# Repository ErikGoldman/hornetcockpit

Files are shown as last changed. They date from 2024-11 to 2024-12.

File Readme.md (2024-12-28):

# Stuff to buy

* [Buttons](https://www.aliexpress.us/item/3256807596969239.html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)
  * 3x for landing panel, 1x for emergency jet button

* [Rotary switches](https://www.aliexpress.us/item/3256806749667426.html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)
  * 2 x 3-position for the DDI on/day/night
  * 1 x 5-position for jett select on the button box

* [Rtoary encoder](https://www.aliexpress.us/item/3256804721655912.html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)
  * 2 for the UFC comm knobs

* [Switches](https://www.aliexpress.us/item/3256803381777279.html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)
  * 4 x On-Off for the landing panel
  * 1 x On-Off-On for the landing panel (flaps switch)

* [Heavy on/off switch](https://www.aliexpress.us/item/3256807335530736.html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)
  * 1  for Master Arm
  * 1 for landing gear on button box

* [Infinite metric inserts](https://www.aliexpress.us/item/3256806602613585.html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)
  * You'll need M2, M3, and M4. Length doesn't matter that much.

* [Tactile switches](https://www.aliexpress.us/item/3256806726559452.html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)
  * You'll need ~25 B3F-1025 buttons for the UFC

* [LED tactile switches](https://www.aliexpress.us/item/3256805751476152.html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)
  * You'll need 40 for the DDIs. Might as well get green even if we're not lighting them up but up to you.

* [Potentiometers](https://www.aliexpress.us/item/3256806040646290.html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)
  * 4 total for the DDI brightness and contrast

* [Micro limit switches](https://www.aliexpress.us/item/3256805410237576.html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)
  * 4x for the parking brake

* [Lots of metric screws](https://www.aliexpress.us/item/3256806962079941.html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)
  * Either buy a few packs or just go to a hardware store and get the ones you need. You'll use M2, M3, and M4 screws for this project.

* [S2 minis](https://www.aliexpress.us/item/3256807363603425.html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)
  * You'll need 4: 2x DDI, 1x UFC, 1x landing box

* [Jumper Wire](https://www.aliexpress.us/item/3256805315188857.html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)
  * Get 2x Female-to-Female and 2x Male-To-Male

* [Flexible wire](https://www.aliexpress.us/item/3256807235268703.html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)
  * 28 AWG flexible silicone wire is handy here

# Assemble

## Printing

Print one of everything in FilesToPrint. Let me know if you run into any trouble but otherwise just keep it organized since you'll have a lot of parts sitting around.

We'll be replacing all of the imperial inserts and screws with metric ones since metric is way cheaper and easier to source. Take a look at "Assembly instructions" to see how everything fits together and use the similarly-sized metric insert and screw instead of whatever is listed there.

There are backplates for the two DDIs, master arm panel, and UFC. Print those and they should line up next to each other. The desk clamps mount on the DDIs and on the master arm panel and allow you to screw into your desk. You may want to put some foam or something soft in the clamp to prevent scratching on your desk.

## PCBs

NextPCB is crazy cheap. There should be NextPCB-compatible BOMs in the directories and the .zip files should be what PCBNext wants to give a quote and manufacture everything.

Note that the holes in the DDIs are too small for your rotary encoders and potentiometers. I dremeled them to be a bit larger and everything was fine. I could modify the PCB to fit the new components but I'm lazy.

## Electrical

Look at the top of the .ino files to see the pin assignments. Look up how to wire buttons and switches if you haven't done it before, the internet will help here.

## Software

Use the .ino sketches to upload to the ESP32s. Note that if you just upload the sketch normally the ESP32 will have its default product ID/serial number/etc. and so you can't have multiple of them connected to DCS at the same time. To fix that, go to Tools -> USB CDC On Boot and set to "Disabled". They should now have descriptive names like "F18 UFC" in DCS.

At the top of the DDI.ino sketch you should see `#define IS_LEFT_DDI 1` -- that should be 1 for for the left DDI but set it to zero before you upload to the right DDI (`#define IS_LEFT_DDI 0`).

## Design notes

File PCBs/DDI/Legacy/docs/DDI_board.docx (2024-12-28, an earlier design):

# DDI and AMPCD boards

This document contains information about the hardware design for DDI and AMPCD panels.

# Modular vs non modular

## Option A: Modular DDI

A modular approach allows for simpler hardware thanks to the reuse of parts, this approach requires a total of 8 DDI/4 PCBs + four AMPCD/4 + three (3) Nano shields made for this purpose.

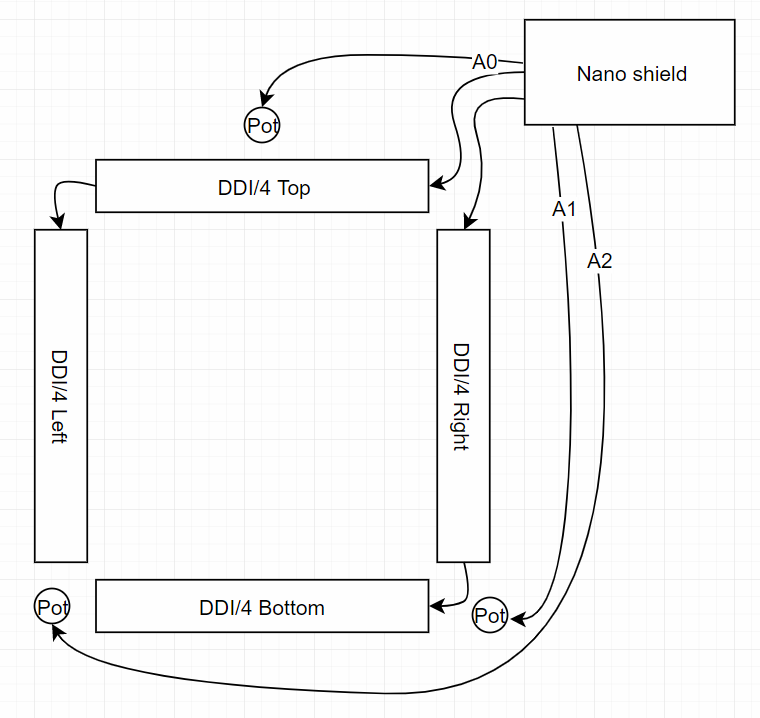
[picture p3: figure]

## Option B: Full board

This approach reuses 100% schematic from modular DDI but two different boards need to be created, one for LEFT/RIGHT DDI panels and one for AMPCD. One thing to consider is that this approach requires three boards of approximately 158mm (6.23in) x 167mm (6.59in) in size.

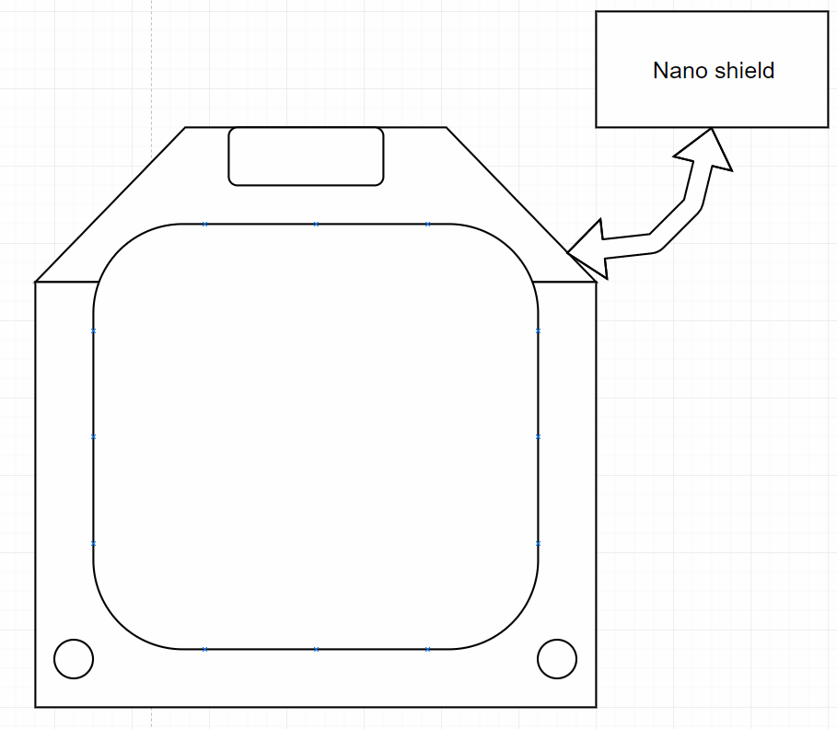
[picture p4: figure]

# Modular detailed

## Left and Right DDI panels

Left and right panels are identical, the only way to differentiate between these two panels is what option is installed on the Nano shield (see Nano shield options for more information)

## AMPCD panel

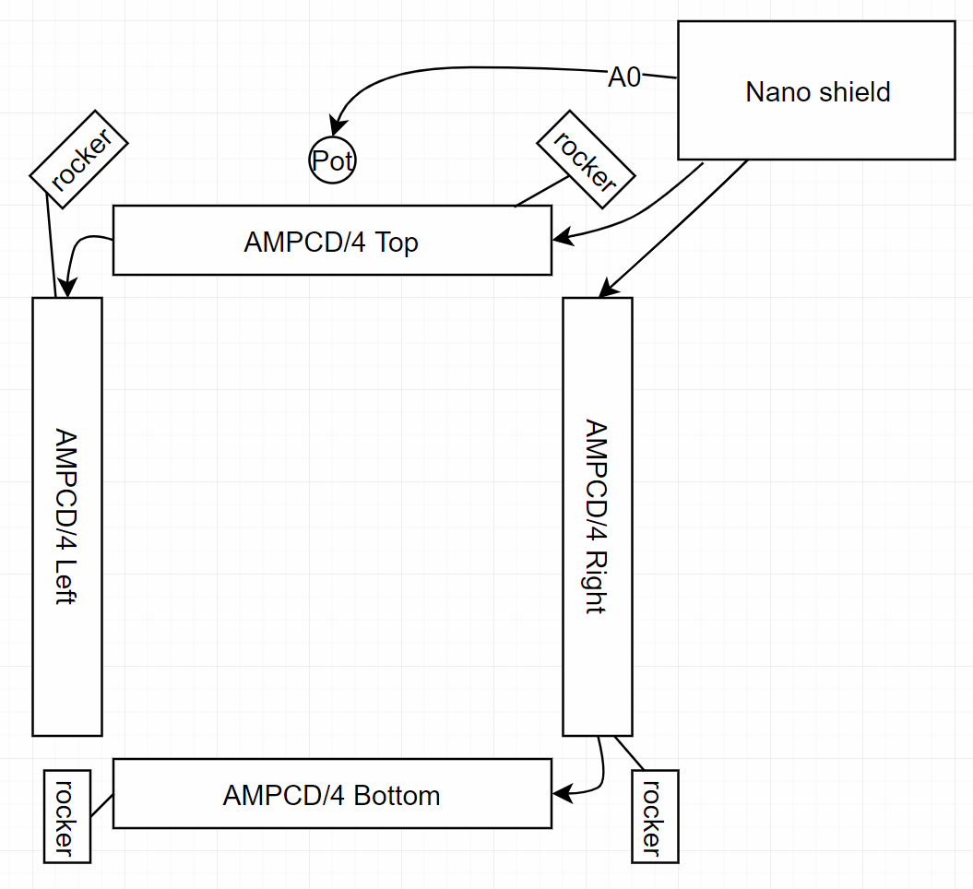
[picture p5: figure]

The AMPCD panel differentiates from the DDI panels thanks to the use of rocker switches, the rocker switches are handled the same way as the OSBs.

## Nano shield options

The Nano shield boards allow for software to recognize the position in the cockpit, this is done by configuring the pull-ups and pull-downs according to the following table.

Option | Requires
Left DDI | d1 Pull down, d0 Pull up
Right DDI | d1 Pull up, d0 Pull down
AMPCD | d1 pull up, d0 pull up

## DDI/4 and AMPCD/4 Addressing

Each one of the boards contains a TCA9534A IO expander, this device can be configured with up to 8 different I2C addresses, upon boot, and Software shall poll all 8 addresses in order to identify what modules are installed. The address assignation is done according to this table.

Location | I2C Address
DDI/4 Top | 0b0111000
DDI/4 Left | 0b0111001
DDI/4 Right | 0b0111010
DDI/4 bottom | 0b0111011

## Button press handling

Each DDI/4 board uses IO expander capable of generating an interrupt when any button is pressed, the PCB provides two button debouncing mechanisms in order to prevent fake interrupts or multiple interrupts in a short period of time.

The debouncing mechanism consists of:

- 6 hysteresis triggered inverted mechanism with <5ms detection delay. These circuits provide full debouncing capabilities and are intended to be used for the five OSBs + an extra button. These inputs filter most of the fake interrupts created by button bouncing by allowing only 0v or 5v outputs. One important distinction is that the values of the switch are inverted and software needs to take this into account.
- 2 non inverted switches with ~5ms detection delay intended for rockers (AMPCD only). These inputs provide medium debouncing capability by smoothing any glitches, fake interrupts may be triggered depending on the receiving IC specific thresholds.

Any change of any of these inputs will cause an interrupt to be fired and software can now read the status of all four DDI/4 blocks in order to determine which button was pushed. If necessary software might add extra debouncing time to compensate for flaky connections and bouncy switches.

The following pictures represent a simulation of the debouncing hardware please notice that the RC constant has been calculated for 10ms leading to a sub 5ms detection delay in most cases.

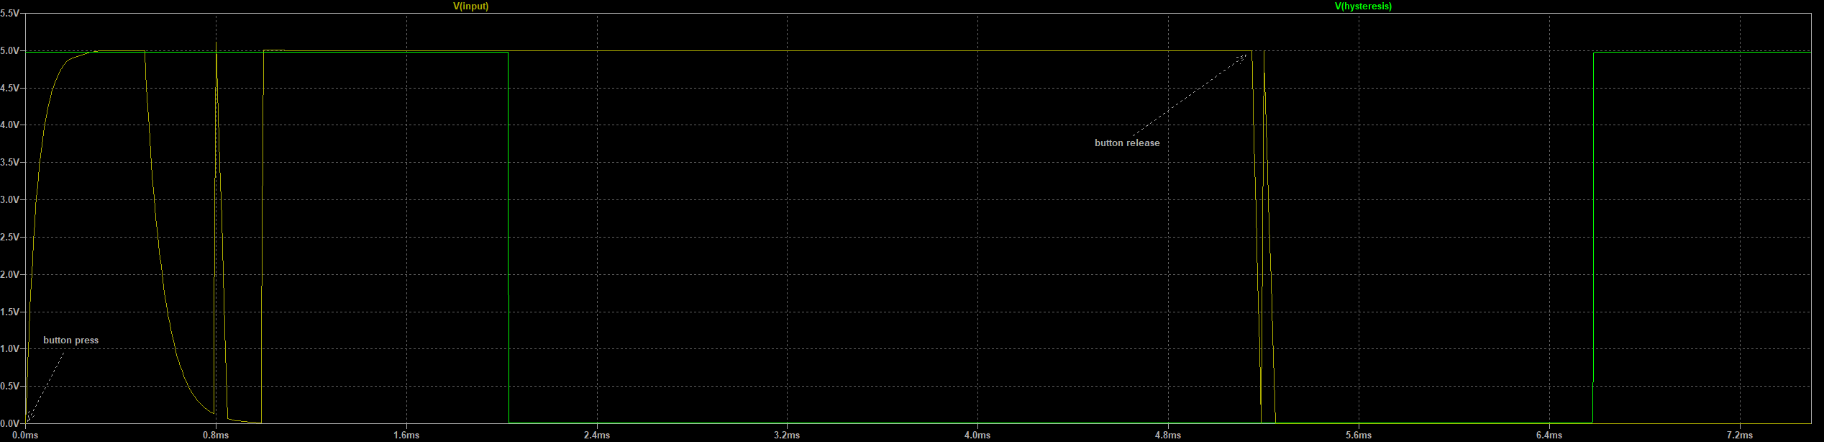
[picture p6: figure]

Figure 1 Button press detection with hysteresis

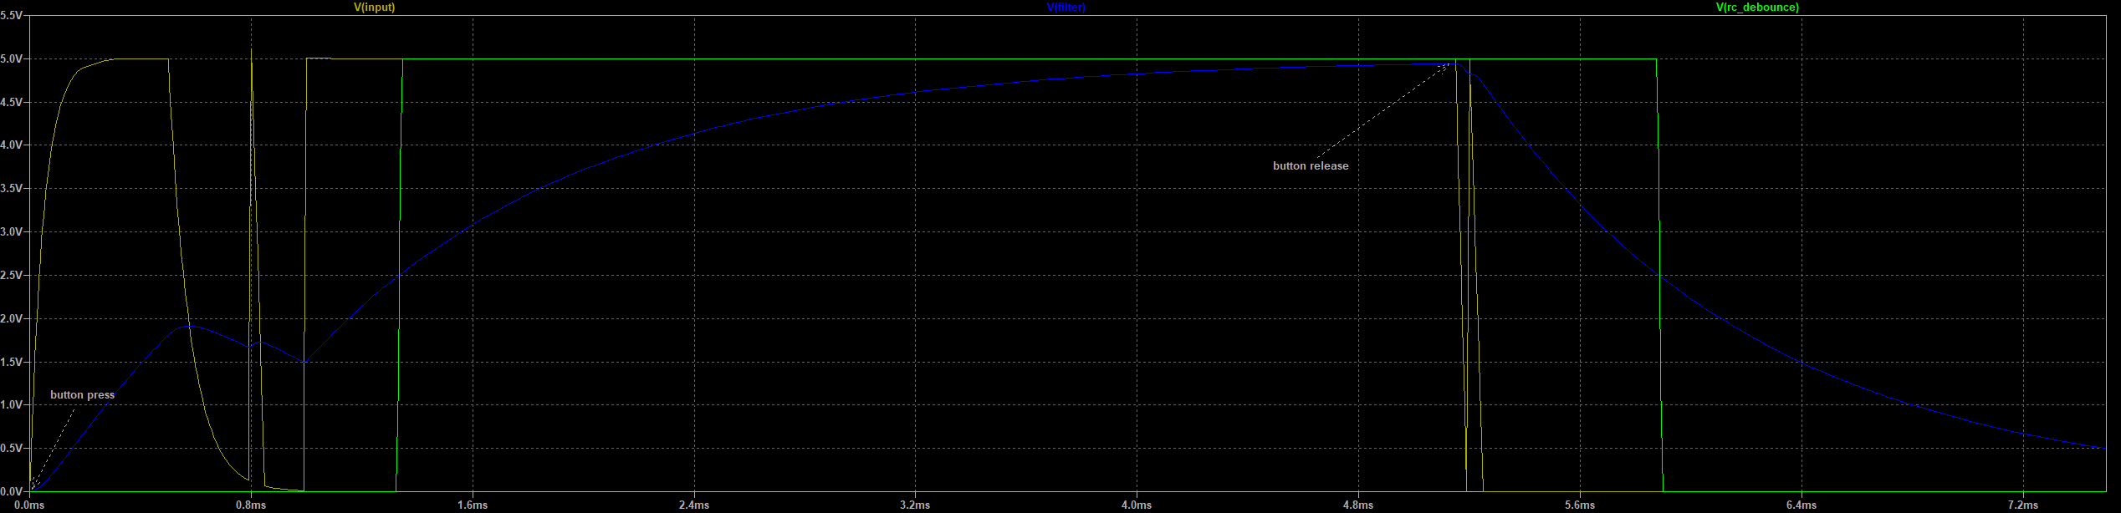
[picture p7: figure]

Figure 2 low pass detection using a 2.5v threshold example

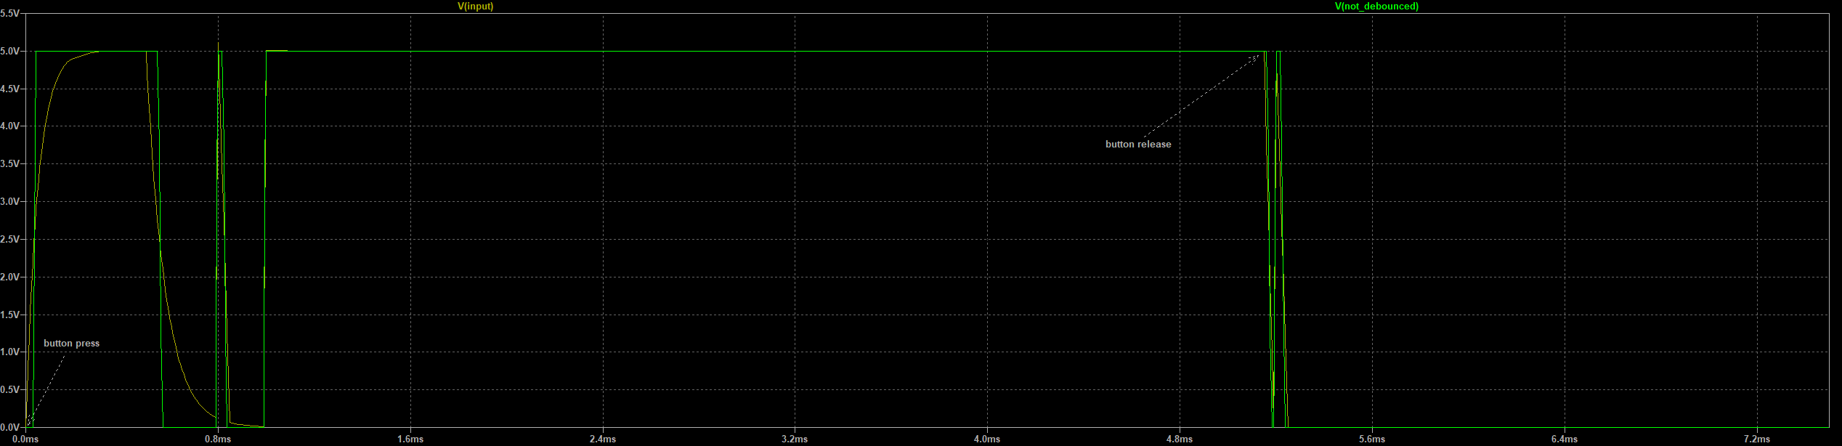
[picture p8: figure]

Figure 3 Raw signal detection (no debouncing)

## Potentiometer handling

The potentiometers installed in each DDI are read from A0-A2 pins from Arduino according to this table:

potentiometer | Pin
<<find names>> | A0
| A1
| A2

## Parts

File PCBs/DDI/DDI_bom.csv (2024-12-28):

Id | Designator | Footprint | Quantity | Designation | Supplier and ref
1 | C1,C2,C3,C4 | C_1206_3216Metric | 4 | 47uF
2 | D1,D2,D3,D4,D5,D6,D7,D8,D9,D10,D11,D12,D13,D14,D17,D18,D19,D20,D21,D22,D23,D24,D25,D26,D27,D28,D29,D30,D31,D32 | LED_0402_1005Metric | 30 | LED
3 | R1,R2,R3 | R_0603_1608Metric | 3 | 10K
4 | R4,R6,R8,R10,R16,R17,R19,R20 | R_0402_1005Metric | 8 | 150
5 | R5,R9,R11,R15,R18,R21,R7 | R_0402_1005Metric | 7 | 270
6 | R12,R13,R14 | R_0402_1005Metric | 3 | 33
7 | U1,U2,U3,U4 | TSSOP-16_4.4x5mm_P0.65mm | 4 | TCA9554PWR
8 | SW1,SW3,SW4,SW5,SW6,SW7,SW8,SW9,SW10,SW11,SW12,SW13,SW14,SW15,SW16,SW17,SW18,SW20,SW2,SW19 | TL1240GQ | 20 | TL1240GQ
9 | G***,G*** | OH_LOGO_ONLY_11x6mm | 2 | OH_LOGO_ONLY_11x6mm

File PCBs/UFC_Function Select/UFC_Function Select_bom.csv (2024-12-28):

Id | Designator | Footprint | Quantity | Designation | Supplier and ref
1 | D23,D4,D3,D27,D1,D26,D15,D20,D13,D10,D25,D7,D2,D24,D6,D16,D19,D11,D5,D21,D9,D8,D14,D22,D12,D28,D17,D18 | LED_WS2812B-2020_PLCC4_2.0x2.0mm | 28 | WS2812B-2020
2 | SW7,SW4,SW3,SW2,SW1,SW6,SW5 | Omron_B3F-1026 | 7 | B3F-1026
3 | J1 | PinHeader_2x03_P2.54mm_Vertical | 1 | TO UFC
4 | U1 | VQFN-24-1EP_4x4mm_P0.5mm_EP2.45x2.45mm | 1 | PCA9555RGER
5 | C1 | CP_Elec_6.3x5.4 | 1 | 100uF
6 | C2 | C_0603_1608Metric | 1 | .1uF
7 | R4 | R_0603_1608Metric | 1 | 10K

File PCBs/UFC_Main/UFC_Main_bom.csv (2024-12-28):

Id | Designator | Footprint | Quantity | Designation | Supplier and ref
1 | MK1,MK2,MK3,MK4 | MountingHole_4.5mm | 4 | MH
2 | POT1 | BR10K_Pot_11mm_x_11mm | 1 | VOL1
3 | POT3 | BR10K_Pot_11mm_x_11mm | 1 | BRT
4 | POT2 | BR10K_Pot_11mm_x_11mm | 1 | VOL2
5 | MK5 | MountingHole_6.4mm_M6 | 1 | SW_ADF
6 | TP1 | TestPoint_THTPad_D1.5mm_Drill0.7mm | 1 | 5V
7 | TP2,TP10,TP7,TP9,TP8 | TestPoint_THTPad_D1.5mm_Drill0.7mm | 5 | GND
8 | DS7,DS8 | UFCSingleDigit | 2 | UFCSingleDigit
9 | DS2 | UFCOptionDigit | 1 | UFCOptionDigit
10 | DS3,DS4,DS5,DS6 | UFCOptionDigit | 4 | UFCOptionDigit
11 | BL1 | SCRATCHPADBACKLIGHT | 1 | SCR BL
12 | DS1 | SCRATCHPADLCD | 1 | SCR DISP
13 | D30,D13,D44,D57,D99,D67,D1,D17,D9,D52,D62,D111,D14,D27,D54,D46,D2,D91,D109,D63,D45,D49,D113,D33,D26,D97,D101,D50,D41,D8,D107,D10,D68,D90,D11,D114,D5,D105,D115,D95,D92,D28,D117,D53,D22,D35,D23,D7,D65,D108,D42,D93,D103,D61,D29,D88,D64,D19,D87,D31,D102,D100,D32,D55,D56,D112,D4,D60,D51,D106,D6,D86,D21,D15,D12,D104,D94,D16,D18,D43,D116,D20,D48,D25,D96,D3,D66,D89,D98,D34,D24,D36,D47,D58,D59,D110 | LED_WS2812B-2020_PLCC4_2.0x2.0mm | 96 | WS2812B-2020
14 | SW4,SW12,SW11,SW5,SW10,SW9,SW7,SW17,SW14,SW1,SW6,SW3,SW13,SW19,SW2,SW8,SW18,SW15,SW16 | Omron_B3F-1026 | 19 | B3F-1026
15 | TP3 | TestPoint_THTPad_D1.5mm_Drill0.7mm | 1 | SCL
16 | TP5 | TestPoint_THTPad_D1.5mm_Drill0.7mm | 1 | SCL@3.3V
17 | TP4 | TestPoint_THTPad_D1.5mm_Drill0.7mm | 1 | SDA
18 | TP6 | TestPoint_THTPad_D1.5mm_Drill0.7mm | 1 | SDA@3.3V
19 | C1,C2,C3,C4,C16,C15,C13 | C_0805_2012Metric | 7 | 10uF
20 | C7,C9,C10,C11,C12 | C_0603_1608Metric | 5 | .1uF
21 | C8,C6,C5 | C_0402_1005Metric | 3 | 100nF
22 | J1 | PinHeader_1x02_P2.54mm_Vertical | 1 | EXT_PWR
23 | J2 | PinHeader_1x04_P2.54mm_Vertical | 1 | ENC1
24 | J3 | PinHeader_1x03_P2.54mm_Vertical | 1 | VOL1
25 | J4 | PinHeader_1x03_P2.54mm_Vertical | 1 | BRT
26 | J5 | PinHeader_2x03_P2.54mm_Vertical | 1 | AP KB
27 | J6 | PinHeader_1x04_P2.54mm_Vertical | 1 | HUD BIT
28 | J7 | PinHeader_1x04_P2.54mm_Vertical | 1 | ENC2
29 | J8 | PinHeader_1x03_P2.54mm_Vertical | 1 | VOL2
30 | J9 | PinHeader_1x03_P2.54mm_Vertical | 1 | ADF SW
31 | R3,R7,R8,R2 | R_0603_1608Metric | 4 | 10K
32 | R4,R9,R10,R11,R12,R41,R40 | R_0603_1608Metric | 7 | 4.7k
33 | R43,R44 | R_0603_1608Metric | 2 | 68
34 | U1 | LQFP-48_7x7mm_P0.5mm | 1 | HT1621B
35 | U2,U3,U4,U5,U7,U6,U11 | SSOP-28_3.9x9.9mm_P0.635mm | 7 | GN1640T
36 | U8,U9 | TSSOP-20_4.4x6.5mm_P0.65mm | 2 | TXS0108EPWR
37 | MC1 | S2_MINI | 1 | S2_MINI
38 | G*** | OH_LOGO_75.4mm_11.9mm | 1 | LOGO
39 | D75,D70,D76,D74,D78,D80,D82,D73,D71,D81,D84,D85,D83,D79,D77,D69,D72 | D_SOD-523 | 17 | 1N4148WT
40 | Q5,Q6,Q4,Q7,Q8 | SOT-23 | 5 | ME2328-G
41 | C14 | CP_Elec_8x10 | 1 | 1000uF
42 | R1 | R_1812_4532Metric_Pad1.30x3.40mm_HandSolder | 1 | 30
43 | Q2 | SOT-23 | 1 | 2N7002
44 | D38 | LED_0603_1608Metric_Pad1.05x0.95mm_HandSolder | 1 | +3.3V_PWR
45 | R14,R6 | R_0402_1005Metric | 2 | 100K
46 | U10 | WQFN-24-1EP_4x4mm_P0.5mm_EP2.45x2.45mm | 1 | TCA8418RTWR
47 | D40 | LED_0603_1608Metric_Pad1.05x0.95mm_HandSolder | 1 | EXT PWR
48 | D37 | LED_0603_1608Metric_Pad1.05x0.95mm_HandSolder | 1 | +5V_PWR
49 | R46 | R_0402_1005Metric | 1 | 33
50 | D39 | D_SOD-123F | 1 | 1N4004W
51 | R13,R45 | R_0603_1608Metric | 2 | 120

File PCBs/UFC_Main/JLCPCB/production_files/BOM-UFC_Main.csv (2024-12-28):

Comment | Designator | Footprint | LCSC
TCA8418RTWR | U10 | WQFN-24-1EP_4x4mm_P0.5mm_EP2.45x2.45mm | C138713
.1uF | C10,C11,C12,C7,C9 | C_0603_1608Metric | C14663
100nF | C5,C6,C8 | C_0402_1005Metric | C1525
10uF | C1,C13,C15,C16,C2,C3,C4 | C_0805_2012Metric | C15850
1N4004W | D39 | D_SOD-123F | C162732
TXS0108EPWR | U8,U9 | TSSOP-20_4.4x6.5mm_P0.65mm | C17206
30 | R1 | R_1812_4532Metric_Pad1.30x3.40mm_HandSolder | C174837
120 | R13,R45 | R_0603_1608Metric | C22787
4.7k | R10,R11,R12,R4,R40,R41,R9 | R_0603_1608Metric | C23162
33 | R46 | R_0402_1005Metric | C25105
10K | R2,R3,R7,R8 | R_0603_1608Metric | C25804
GN1640T | U11,U2,U3,U4,U5,U6,U7 | SSOP-28_3.9x9.9mm_P0.635mm | C2758330
68 | R43,R44 | R_0603_1608Metric | C27592
100K | R14,R6 | R_0402_1005Metric | C327804
1000uF | C14 | CP_Elec_8x10 | C445083
ME2328-G | Q1,Q10,Q11,Q3,Q4,Q5,Q6,Q7,Q8,Q9 | SOT-23 | C709746
+5V_PWR | D37,D38,D40 | LED_0603_1608Metric_Pad1.05x0.95mm_HandSolder | C72043
1N4148WT | D69,D70,D71,D72,D73,D74,D75,D76,D77,D78,D79,D80,D81,D82,D83,D84,D85 | D_SOD-523 | C727112
HT1621B | U1 | LQFP-48_7x7mm_P0.5mm | C7532
2N7002 | Q2 | SOT-23 | C8545
WS2812B-2020 | D1,D10,D100,D101,D102,D103,D104,D105,D106,D107,D108,D109,D11,D110,D111,D112,D113,D114,D115,D116,D117,D12,D13,D14,D15,D16,D17,D18,D19,D2,D20,D21,D22,D23,D24,D25,D26,D27,D28,D29,D3,D30,D31,D32,D33,D34,D35,D36,D4,D41,D42,D43,D44,D45,D46,D47,D48,D49,D5,D50,D51,D52,D53,D54,D55,D56,D57,D58,D59,D6,D60,D61,D62,D63,D64,D65,D66,D67,D68,D7,D8,D86,D87,D88,D89,D9,D90,D91,D92,D93,D94,D95,D96,D97,D98,D99 | LED_WS2812B-2020_PLCC4_2.0x2.0mm | C965555
S2_MINI | MC1 | S2_MINI
ADF SW | J9 | PinHeader_1x03_P2.54mm_Vertical
VOL2 | J8 | PinHeader_1x03_P2.54mm_Vertical
ENC2 | J7 | PinHeader_1x04_P2.54mm_Vertical
HUD BIT | J6 | PinHeader_1x04_P2.54mm_Vertical
AP KB | J5 | PinHeader_2x03_P2.54mm_Vertical
BRT | J4 | PinHeader_1x03_P2.54mm_Vertical
VOL1 | J3 | PinHeader_1x03_P2.54mm_Vertical
ENC1 | J2 | PinHeader_1x04_P2.54mm_Vertical
EXT_PWR | J1 | PinHeader_1x02_P2.54mm_Vertical
SCR DISP | DS1 | SCRATCHPADLCD
SCR BL | BL1 | SCRATCHPADBACKLIGHT
UFCOptionDigit | DS6 | UFCOptionDigit
UFCOptionDigit | DS5 | UFCOptionDigit
UFCOptionDigit | DS4 | UFCOptionDigit
UFCOptionDigit | DS3 | UFCOptionDigit
UFCOptionDigit | DS2 | UFCOptionDigit
UFCSingleDigit | DS8 | UFCSingleDigit
UFCSingleDigit | DS7 | UFCSingleDigit
VOL2 | POT2 | BR10K_Pot_11mm_x_11mm
BRT | POT3 | BR10K_Pot_11mm_x_11mm
VOL1 | POT1 | BR10K_Pot_11mm_x_11mm
B3F-1026 | SW1 | Omron_B3F-1026
B3F-1026 | SW2 | Omron_B3F-1026
B3F-1026 | SW3 | Omron_B3F-1026
B3F-1026 | SW4 | Omron_B3F-1026
B3F-1026 | SW5 | Omron_B3F-1026
B3F-1026 | SW6 | Omron_B3F-1026
B3F-1026 | SW7 | Omron_B3F-1026
B3F-1026 | SW8 | Omron_B3F-1026
B3F-1026 | SW9 | Omron_B3F-1026
B3F-1026 | SW10 | Omron_B3F-1026
B3F-1026 | SW11 | Omron_B3F-1026
B3F-1026 | SW12 | Omron_B3F-1026
B3F-1026 | SW13 | Omron_B3F-1026
B3F-1026 | SW14 | Omron_B3F-1026
B3F-1026 | SW15 | Omron_B3F-1026
B3F-1026 | SW16 | Omron_B3F-1026
B3F-1026 | SW17 | Omron_B3F-1026
B3F-1026 | SW18 | Omron_B3F-1026
B3F-1026 | SW19 | Omron_B3F-1026

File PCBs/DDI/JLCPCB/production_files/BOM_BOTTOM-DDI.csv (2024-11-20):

Comment | Designator | Footprint | LCSC
Conn_01x06 | J1 | Molex_KK-254_AE-6410-06A_1x06_P2.54mm_Vertical | C504992

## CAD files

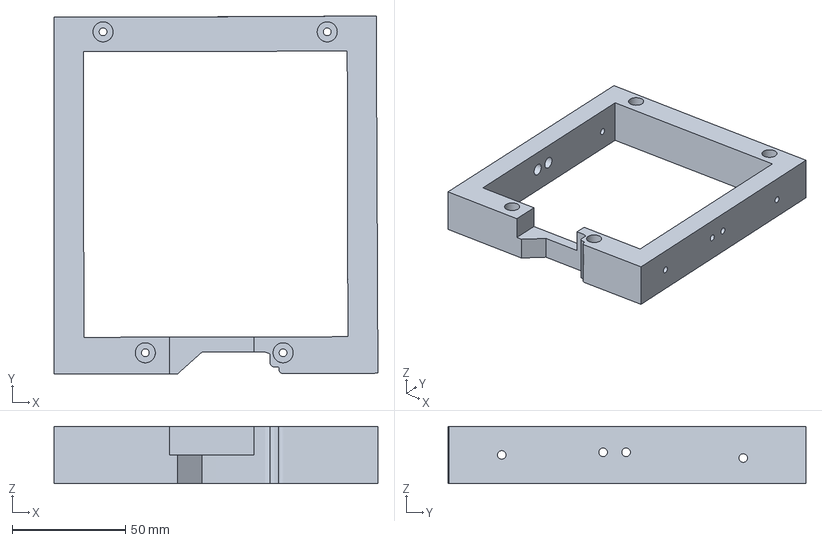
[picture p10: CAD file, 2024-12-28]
FilesToPrint/DDI/DDI desk Mount Plate.3mf
143.3 x 158.4 x 25.4 mm

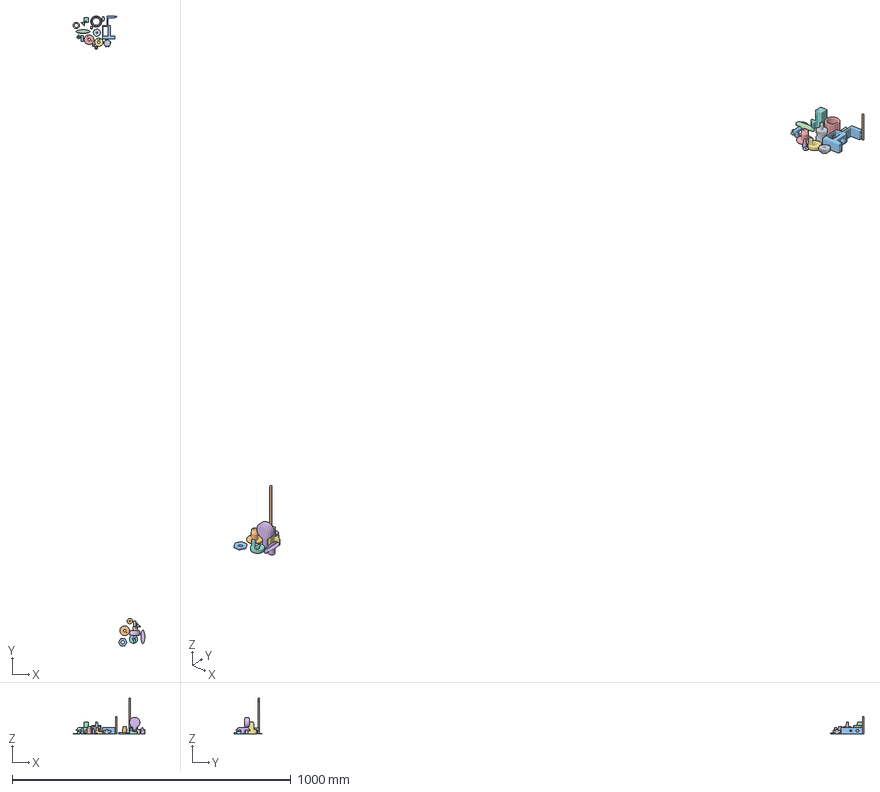
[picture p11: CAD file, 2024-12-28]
FilesToPrint/Landing panel/button box components.3mf
257.4 x 2259.5 x 128.1 mm
launch bar switch cover
circular top switch cover
parking brake lollipop
PB enclosure
PB EnclosureTopBody
PB M14 nut
PB handle
PB EnclosureBottomBody
PB shaft
flaps switch cover
AntiSkidSwitchCover
PB washer

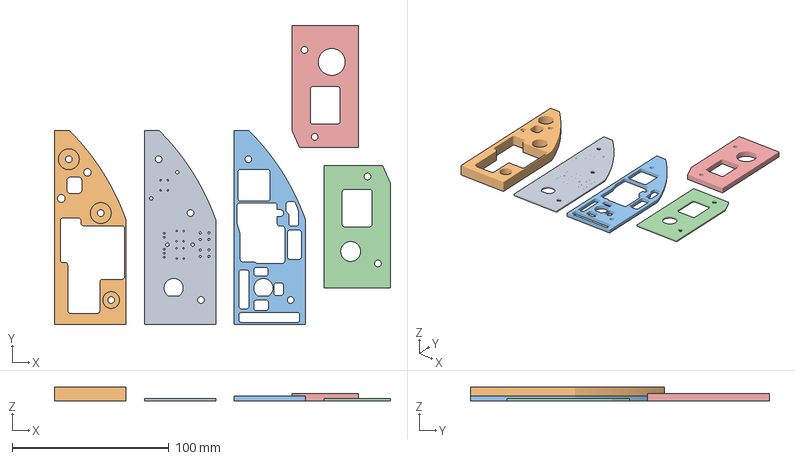
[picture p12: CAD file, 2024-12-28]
FilesToPrint/Master arm panel/master arm front panels.3mf
214.2 x 190.4 x 9.20 mm
master arm pcb
master arm spacer
master arm backplate
master arm legend plate
master arm thick front cover

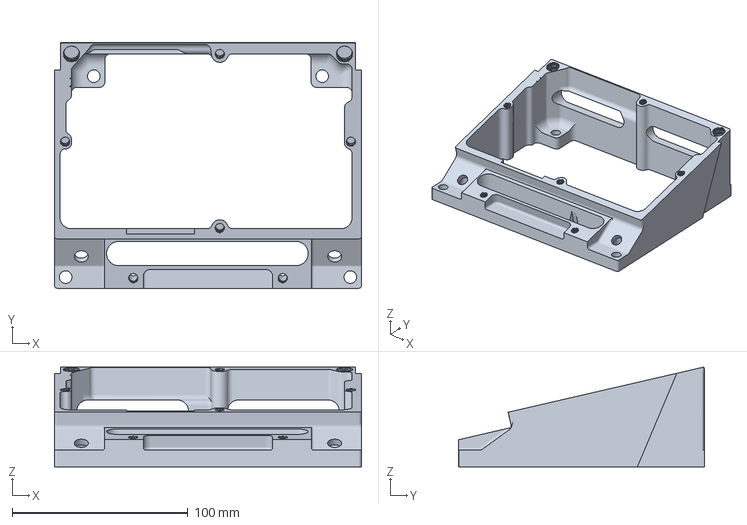
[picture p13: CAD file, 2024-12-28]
FilesToPrint/UFC/ufc panel support structure.3mf
174.6 x 139.7 x 56.8 mm

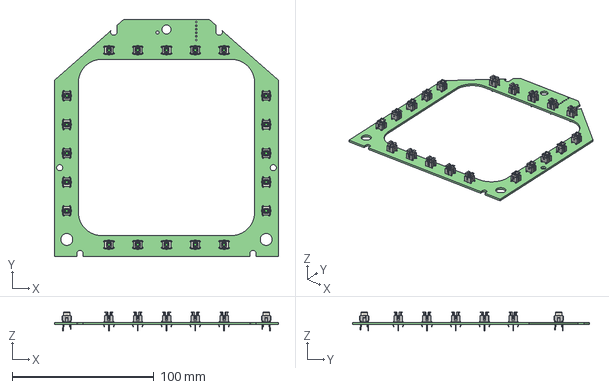
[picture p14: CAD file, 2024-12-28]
PCBs/DDI/MCAD/DDI.step
158.2 x 167.4 x 13.4 mm
DDI PCB

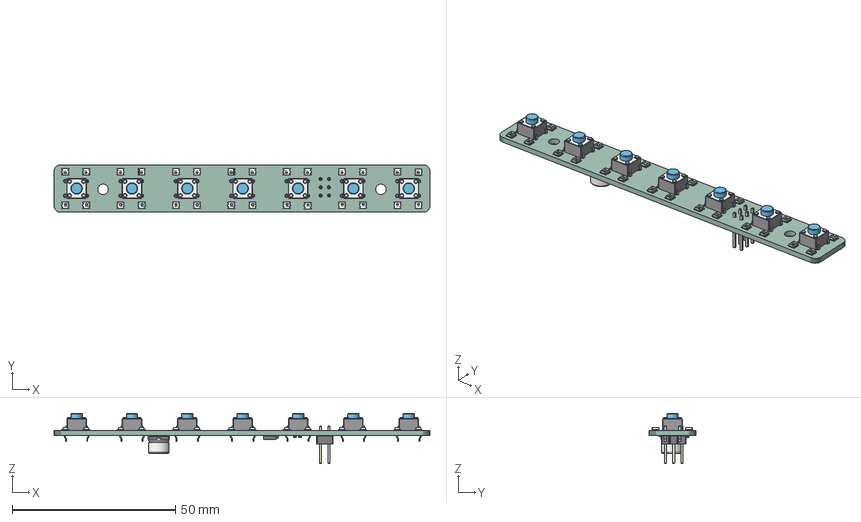
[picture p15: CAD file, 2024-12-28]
PCBs/UFC_Function Select/MCAD/PCB, UFC_Function Select.step
115.0 x 14.5 x 15.4 mm
PCB

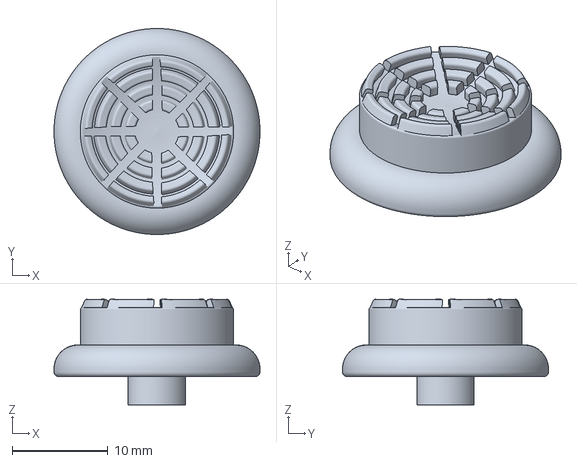
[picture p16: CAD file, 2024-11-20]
stecs mods/tdc.3mf
21.5 x 21.5 x 11.0 mm

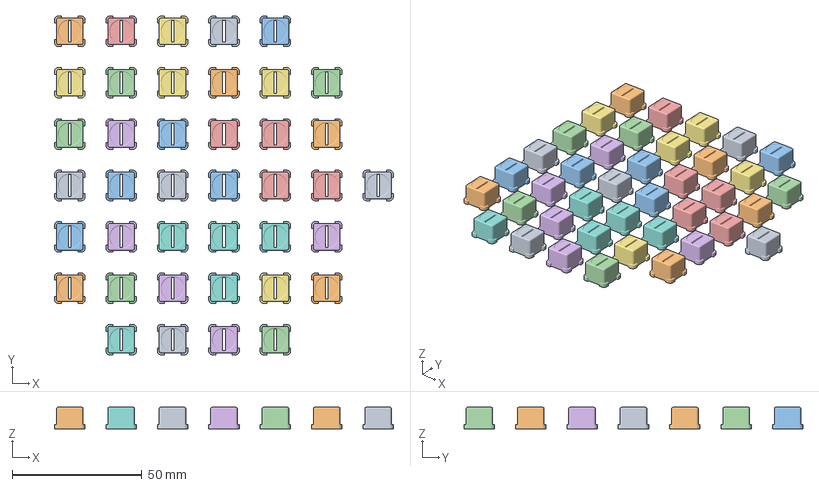
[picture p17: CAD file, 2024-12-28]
FilesToPrint/DDI/ddi buttons.3mf
130.6 x 130.6 x 8.29 mm
RESN_OH1A3-11_DDI BUTTON_-_V8 x 40

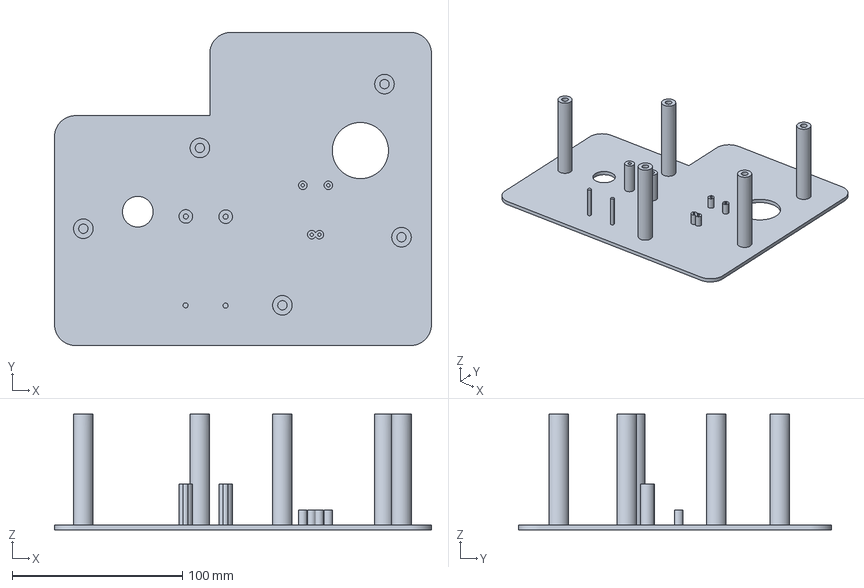
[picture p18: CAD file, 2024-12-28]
FilesToPrint/Landing panel/button box landing enclosure bottom.3mf
221.6 x 184.1 x 68.0 mm

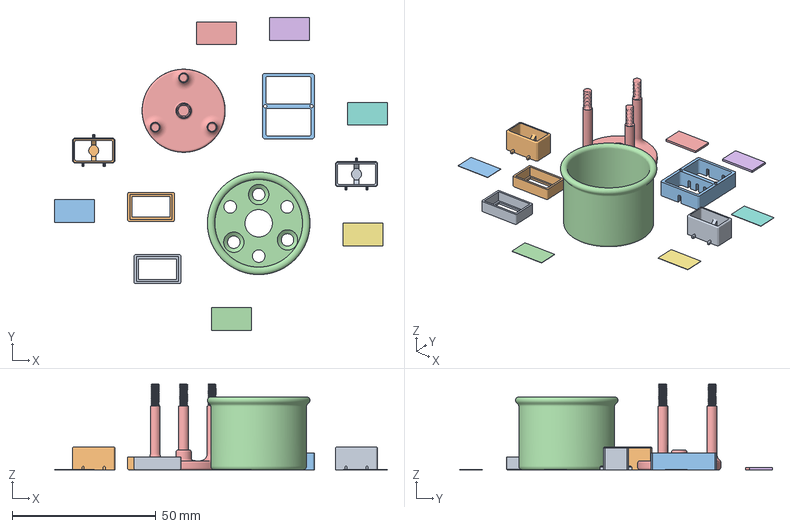
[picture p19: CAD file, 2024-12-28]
FilesToPrint/Master arm panel/master mode buttons.3mf
115.9 x 108.8 x 29.9 mm
master mode pushbutton actuator
master mode pushbutton legend diffuser
master mode pushbutton legend cover
master mode pushbutton legend
master mode pushbutton bezel
master mode pushbutton base
emerg jett housing
emergency jett button

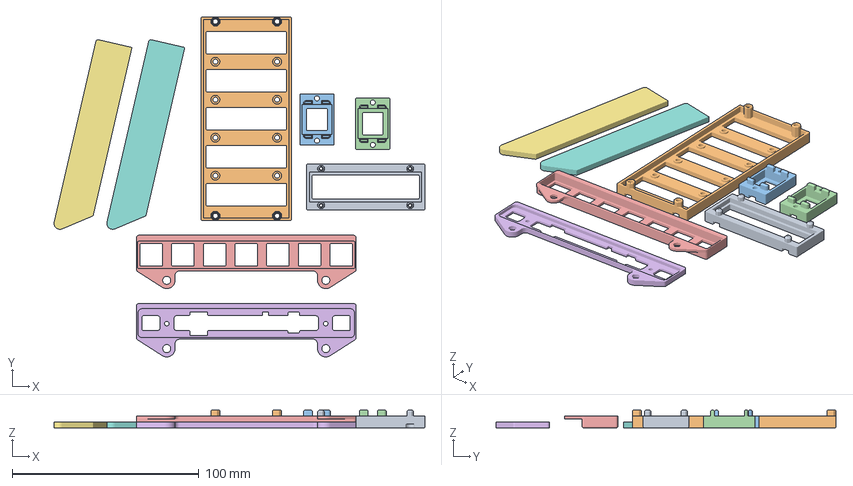
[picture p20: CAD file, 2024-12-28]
FilesToPrint/UFC/ufc bezels.3mf
198.4 x 181.8 x 9.52 mm
FDM_OH1A8A1-105_UFC SCRATCHPAD BEZEL_-_V33
FDM_OH1A8A1-103_UFC OPT BEZEL_-_V33
FDM_OH1A8A1-101_UFC COMM BEZEL_-_V33 x 2
FDM_OH1A8A3-10 - AP MODULE FWD BODY_-_v10
FDM_OH1A8A3-11 - AP MODULE MOUNTING PLATE_-_v10
OH1A8A1-11 FWD UFC GUARD x 2

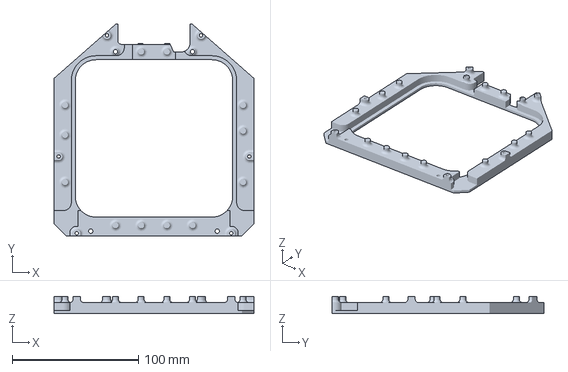
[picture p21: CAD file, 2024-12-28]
FilesToPrint/DDI/ddi bezel.3mf
158.2 x 167.4 x 13.6 mm

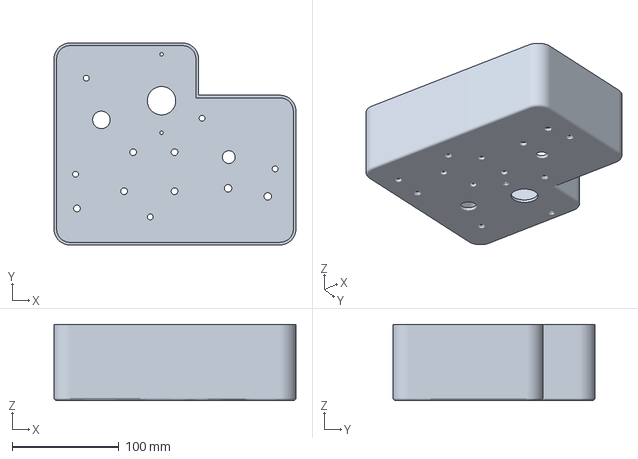
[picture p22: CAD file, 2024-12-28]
FilesToPrint/Landing panel/button box landing enclosure top.3mf
226.8 x 189.3 x 71.3 mm

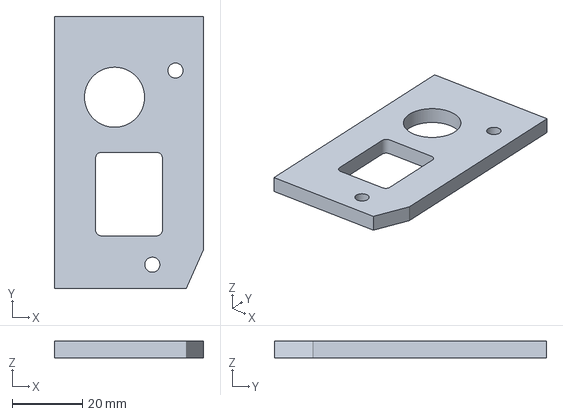
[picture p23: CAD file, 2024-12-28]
FilesToPrint/Master arm panel/master arm thick front cover.3mf
42.5 x 77.8 x 4.76 mm

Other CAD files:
FilesToPrint/UFC/UFC desk Back Plate.3mf
FilesToPrint/DDI/DDI desk mount clamps.3mf
FilesToPrint/Master arm panel/master arm fake pcb.3mf
FilesToPrint/UFC/ufc spacer plate.3mf
FilesToPrint/DDI/OHC0003-08FLGN3-SR - KNOB, GREY, .25 SHAFT, SINGLE SETSCREW.3mf
FilesToPrint/DDI/ddi back.3mf
FilesToPrint/DDI/ddi button accessories.3mf
FilesToPrint/Master arm panel/master arm desk extension.3mf
FilesToPrint/UFC/ufc backplate.3mf
FilesToPrint/UFC/ufc button guards.3mf
FilesToPrint/UFC/ufc buttons.3mf
FilesToPrint/UFC/ufc top panel.3mf
PCBs/DDI/Legacy/docs/DDI_PCB.DXF
PCBs/DDI/Legacy/docs/DDI_PCB_DEFINITION.SLDDRW
PCBs/UFC_Function Select/Legacy/AP Switch Module.dxf
PCBs/UFC_Main/Legacy/UFC Panel_v4.dxf
stecs mods/tdc.stl

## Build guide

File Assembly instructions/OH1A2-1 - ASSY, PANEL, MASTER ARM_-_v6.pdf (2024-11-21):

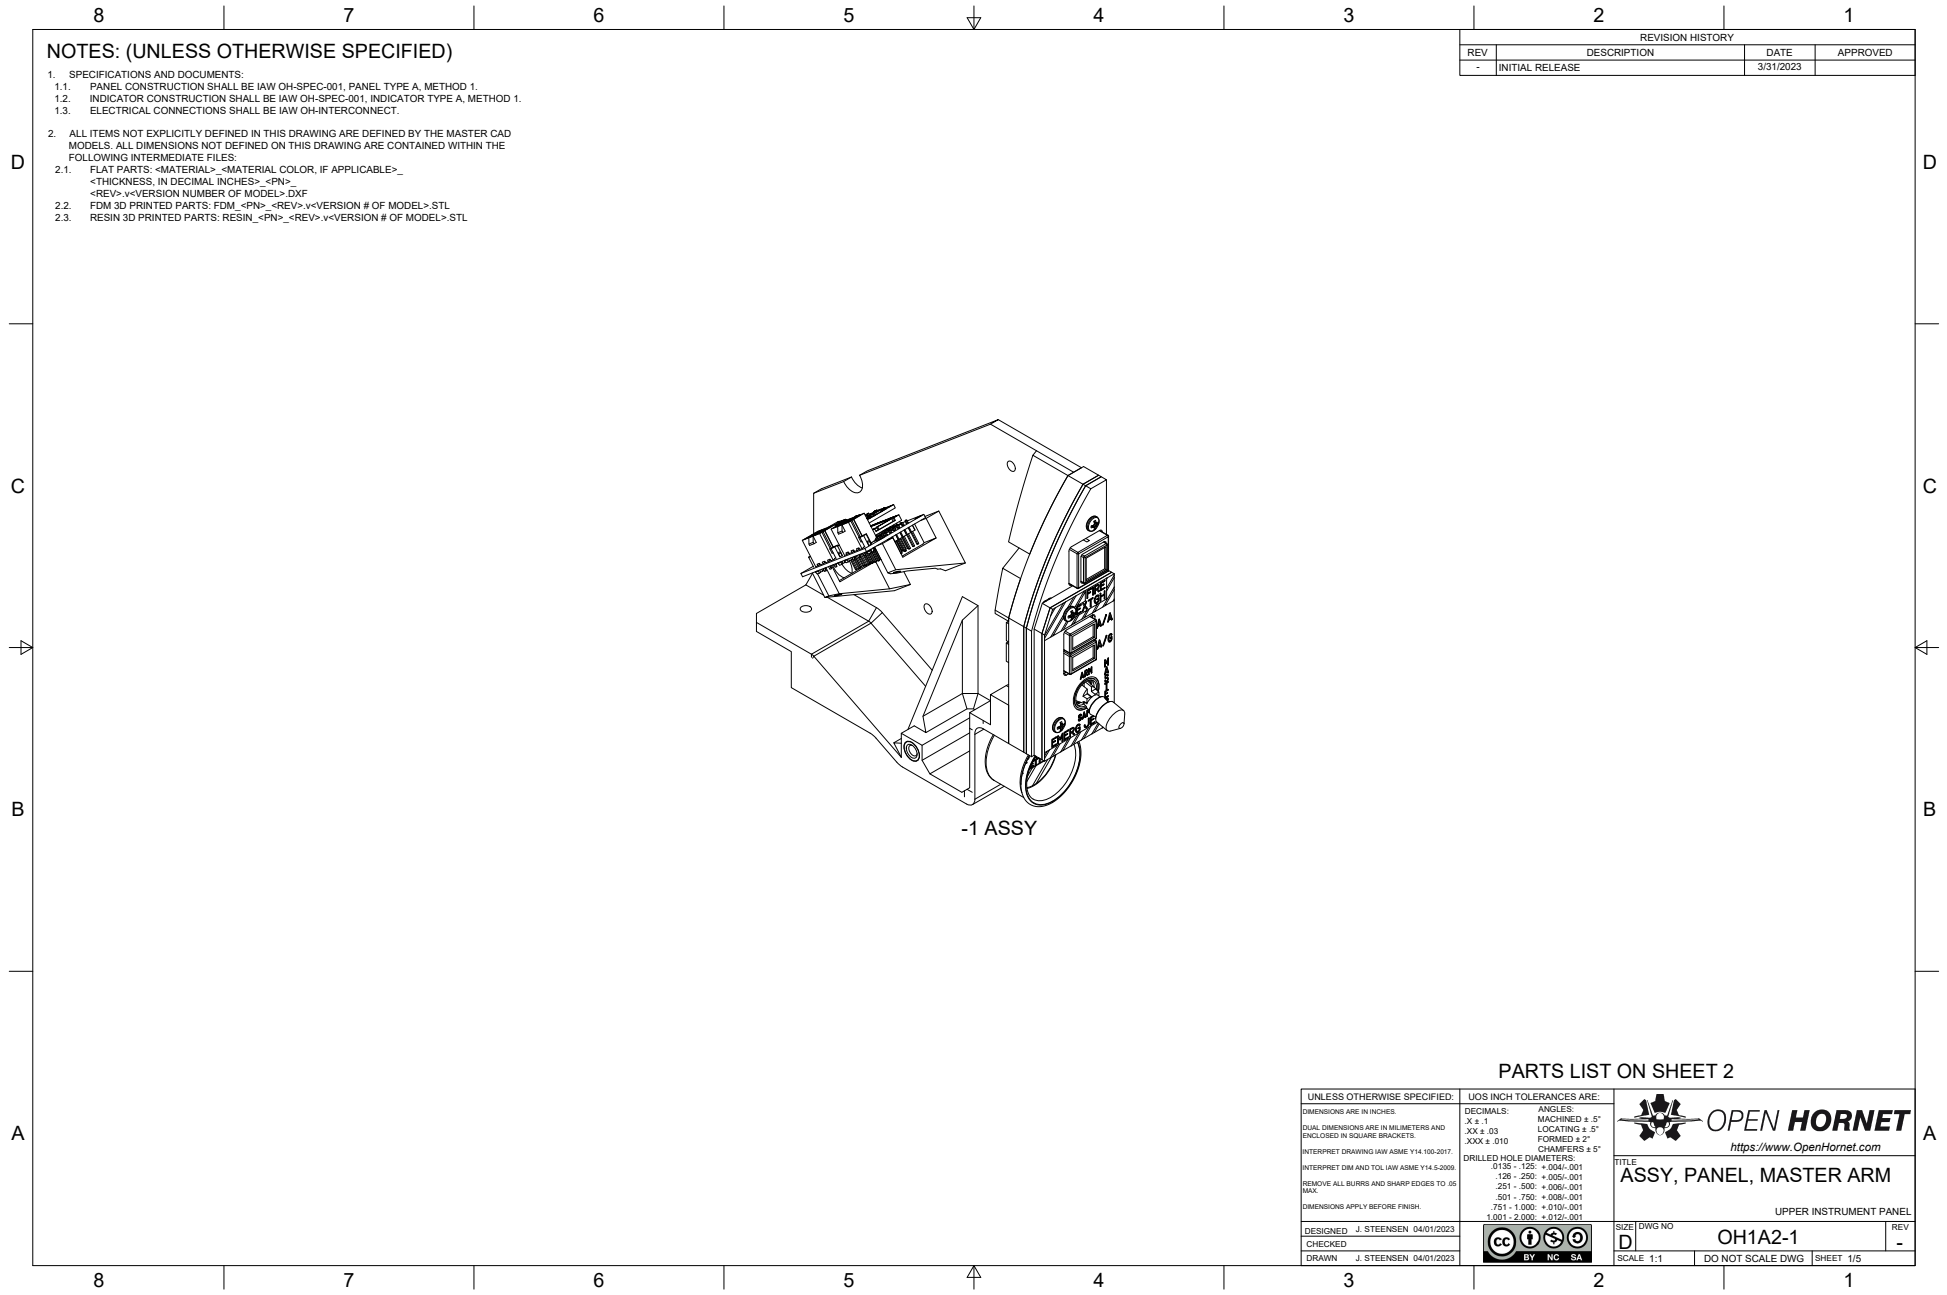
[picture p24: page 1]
J. STEENSEN 04/01/2023; DO NOT SCALE DWG; -1 ASSY; REVISION HISTORY

NOTES: (UNLESS OTHERWISE SPECIFIED)

REV | DESCRIPTION | DATE | APPROVED
- | INITIAL RELEASE | 3/31/2023

1. SPECIFICATIONS AND DOCUMENTS:
1.1. PANEL CONSTRUCTION SHALL BE IAW OH-SPEC-001, PANEL TYPE A, METHOD 1.
1.2. INDICATOR CONSTRUCTION SHALL BE IAW OH-SPEC-001, INDICATOR TYPE A, METHOD 1.
1.3. ELECTRICAL CONNECTIONS SHALL BE IAW OH-INTERCONNECT.

2. ALL ITEMS NOT EXPLICITLY DEFINED IN THIS DRAWING ARE DEFINED BY THE MASTER CAD
MODELS. ALL DIMENSIONS NOT DEFINED ON THIS DRAWING ARE CONTAINED WITHIN THE
FOLLOWING INTERMEDIATE FILES:
2.1. FLAT PARTS: <MATERIAL>_<MATERIAL COLOR, IF APPLICABLE>_

<THICKNESS, IN DECIMAL INCHES>_<PN>_
<REV>.v<VERSION NUMBER OF MODEL>.DXF

2.2. FDM 3D PRINTED PARTS: FDM_<PN>_<REV>.v<VERSION # OF MODEL>.STL
2.3. RESIN 3D PRINTED PARTS: RESIN_<PN>_<REV>.v<VERSION # OF MODEL>.STL

PARTS LIST ON SHEET 2

UNLESS OTHERWISE SPECIFIED: | UOS INCH TOLERANCES ARE: | https://www.OpenHornet.com
DIMENSIONS ARE IN INCHES. DUAL DIMENSIONS ARE IN MILIMETERS AND ENCLOSED IN SQUARE BRACKETS. INTERPRET DRAWING IAW ASME Y14.100-2017. INTERPRET DIM AND TOL IAW ASME Y14.5-2009. REMOVE ALL BURRS AND SHARP EDGES TO .05 MAX. DIMENSIONS APPLY BEFORE FINISH. | ANGLES: DECIMALS: MACHINED ± .5° .X ± .1 LOCATING ± .5° .XX ± .03 FORMED ± 2° .XXX ± .010 CHAMFERS ± 5° DRILLED HOLE DIAMETERS: .0135 - .125: +.004/-.001 .126 - .250: +.005/-.001 .251 - .500: +.006/-.001 .501 - .750: +.008/-.001 .751 - 1.000: +.010/-.001 1.001 - 2.000: +.012/-.001

TITLE
ASSY, PANEL, MASTER ARM

UPPER INSTRUMENT PANEL

J. STEENSEN 04/01/2023 DESIGNED | | SIZE D | DWG NO OH1A2-1 | REV -

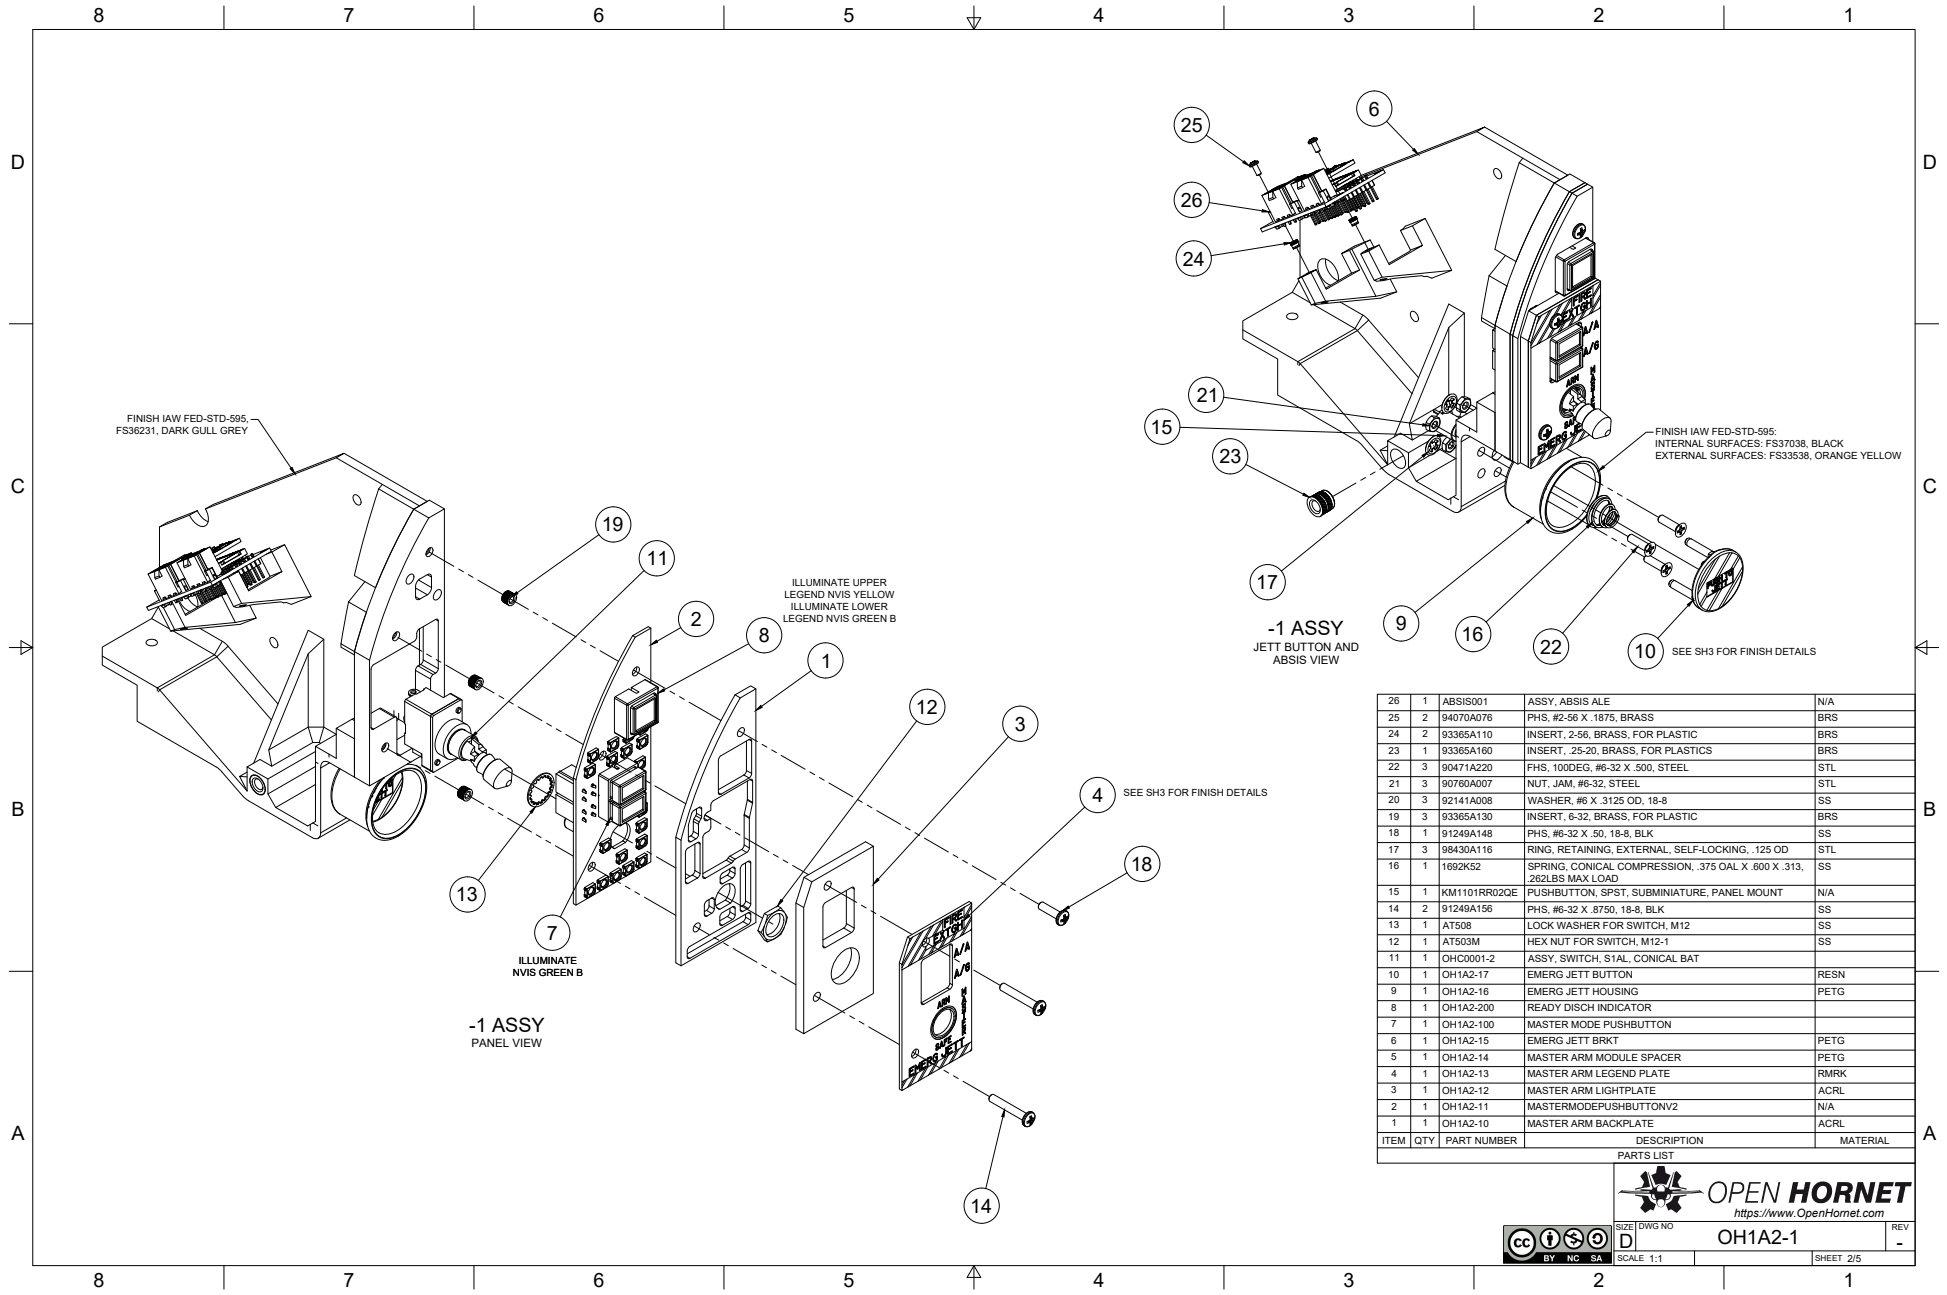
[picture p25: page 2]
-1 ASSY; PARTS LIST; ITEM QTY PART NUMBER; DESCRIPTION; MATERIAL; MASTER ARM BACKPLATE; ACRL; MASTER ARM LIGHTPLATE; MASTER ARM LEGEND PLATE; RMRK; MASTER ARM MODULE SPACER; PETG; EMERG JETT BRKT; MASTER MODE PUSHBUTTON; READY DISCH INDICATOR; EMERG JETT HOUSING; EMERG JETT BUTTON; RESN; OHC0001-2; ASSY, SWITCH, S1AL, CONICAL BAT; HEX NUT FOR SWITCH, M12-1; LOCK WASHER FOR SWITCH, M12; PHS, #6-32 X .8750, 18-8, BLK; KM1101RR02QE PUSHBUTTON, SPST, SUBMINIATURE, PANEL MOUNT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

FINISH IAW FED-STD-595,

INTERNAL SURFACES: FS37038, BLACK
EXTERNAL SURFACES: FS33538, ORANGE YELLOW

ILLUMINATE UPPER
LEGEND NVIS YELLOW
ILLUMINATE LOWER
LEGEND NVIS GREEN B

JETT BUTTON AND
ABSIS VIEW

SEE SH3 FOR FINISH DETAILS

https://www.OpenHornet.com

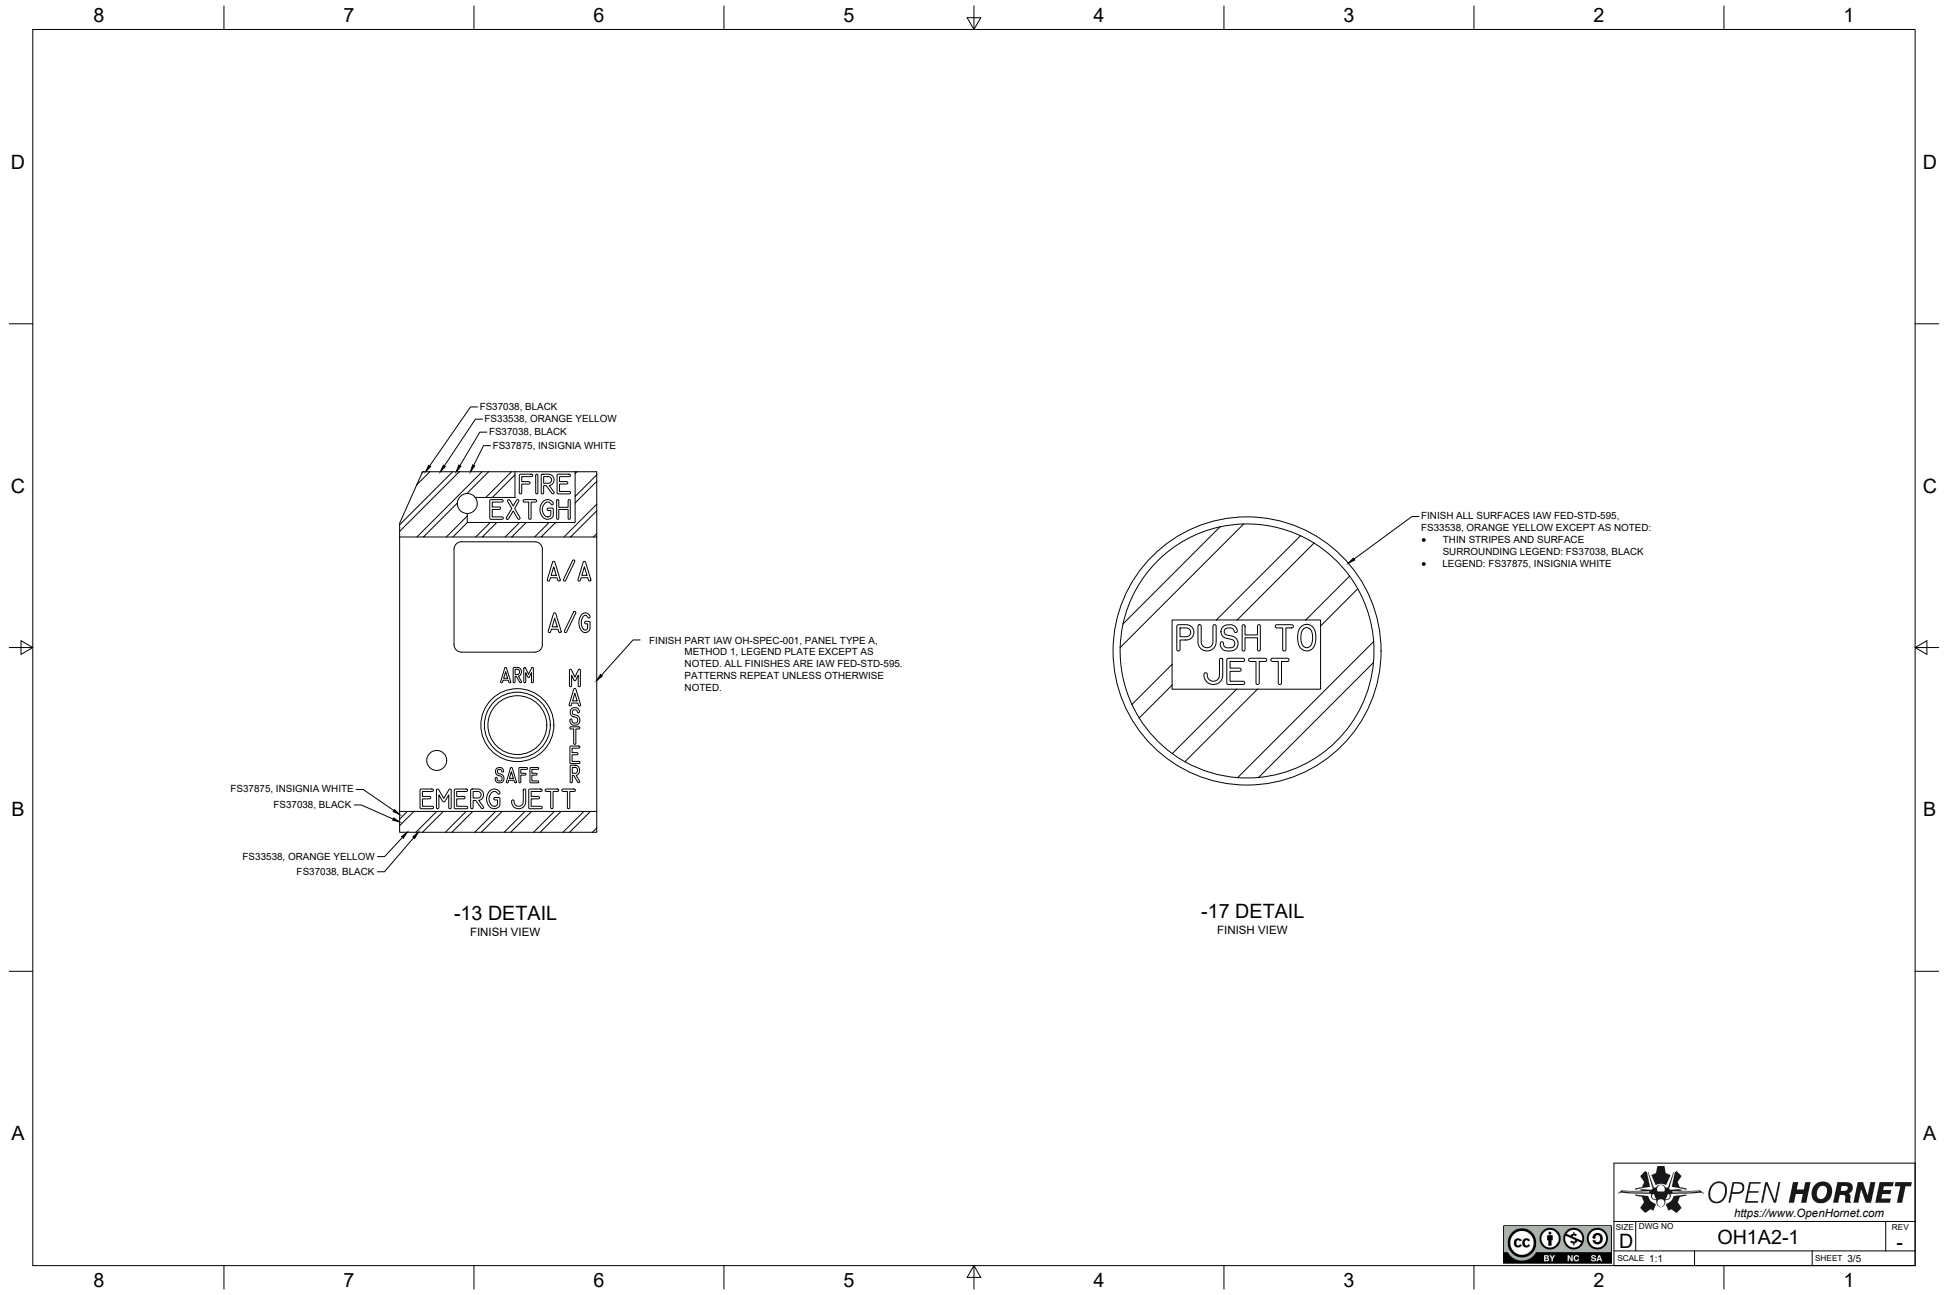
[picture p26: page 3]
-13 DETAIL; FINISH VIEW; FS37038, BLACK FS33538, ORANGE YELLOW FS37038, BLACK FS37875, INSIGNIA WHITE; FS37875, INSIGNIA WHITE; FS37038, BLACK; FS33538, ORANGE YELLOW; -17 DETAIL

FINISH ALL SURFACES IAW FED-STD-595,
FS33538, ORANGE YELLOW EXCEPT AS NOTED:
· THIN STRIPES AND SURFACE
SURROUNDING LEGEND: FS37038, BLACK
· LEGEND: FS37875, INSIGNIA WHITE

FINISH PART IAW OH-SPEC-001, PANEL TYPE A,

METHOD 1, LEGEND PLATE EXCEPT AS
NOTED. ALL FINISHES ARE IAW FED-STD-595.
PATTERNS REPEAT UNLESS OTHERWISE
NOTED.

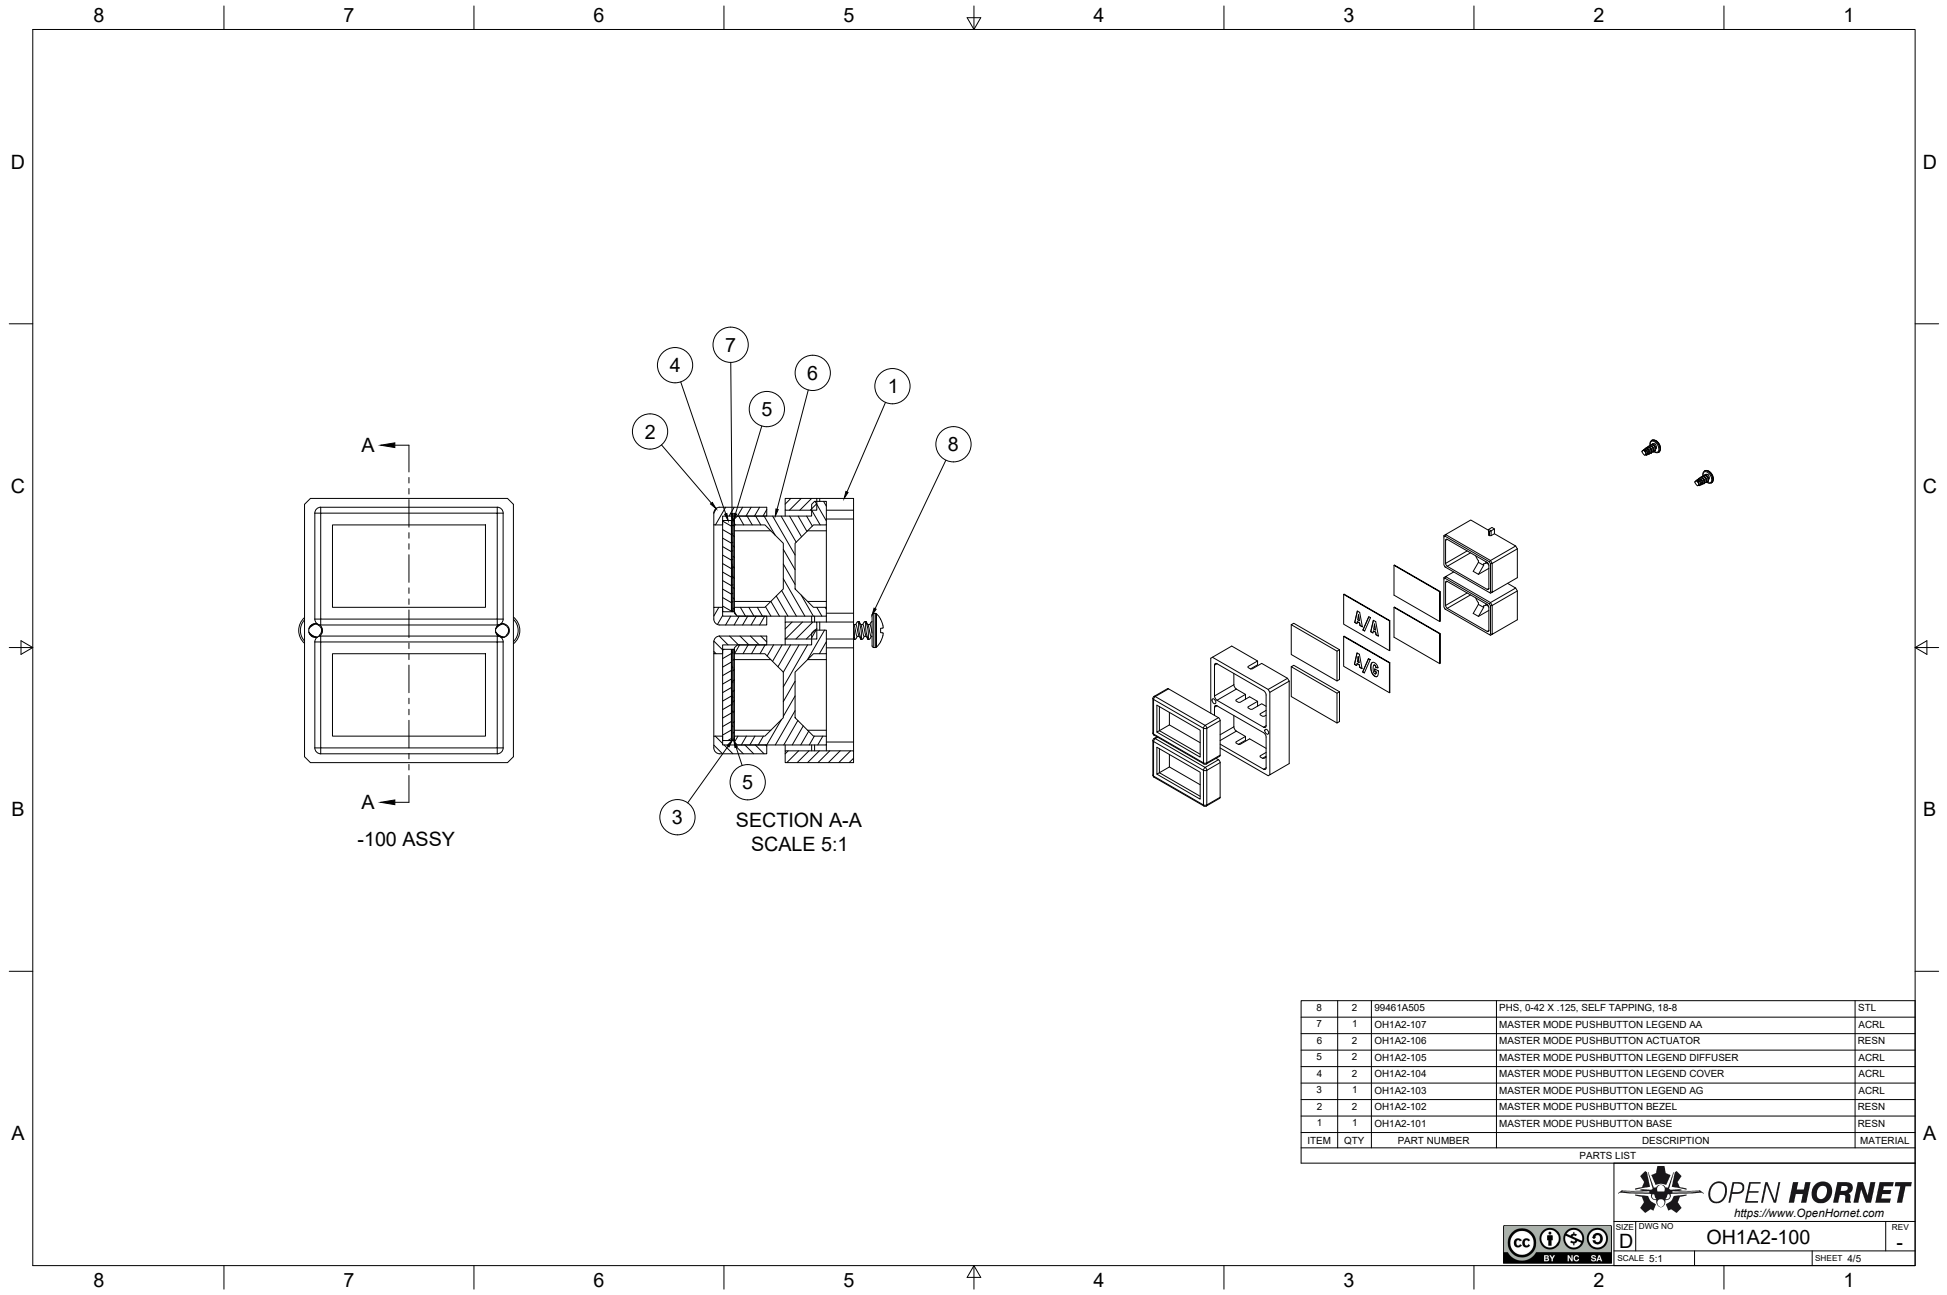
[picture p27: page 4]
-100 ASSY; PARTS LIST; SECTION A-A SCALE 5:1

8 | 2 | 99461A505 | PHS, 0-42 X .125, SELF TAPPING, 18-8 | STL
7 | 1 | OH1A2-107 | MASTER MODE PUSHBUTTON LEGEND AA | ACRL
6 | 2 | OH1A2-106 | MASTER MODE PUSHBUTTON ACTUATOR | RESN
5 | 2 | OH1A2-105 | MASTER MODE PUSHBUTTON LEGEND DIFFUSER | ACRL
4 | 2 | OH1A2-104 | MASTER MODE PUSHBUTTON LEGEND COVER | ACRL
3 | 1 | OH1A2-103 | MASTER MODE PUSHBUTTON LEGEND AG | ACRL
2 | 2 | OH1A2-102 | MASTER MODE PUSHBUTTON BEZEL | RESN
1 | 1 | OH1A2-101 | MASTER MODE PUSHBUTTON BASE | RESN
ITEM | QTY | PART NUMBER | DESCRIPTION | MATERIAL

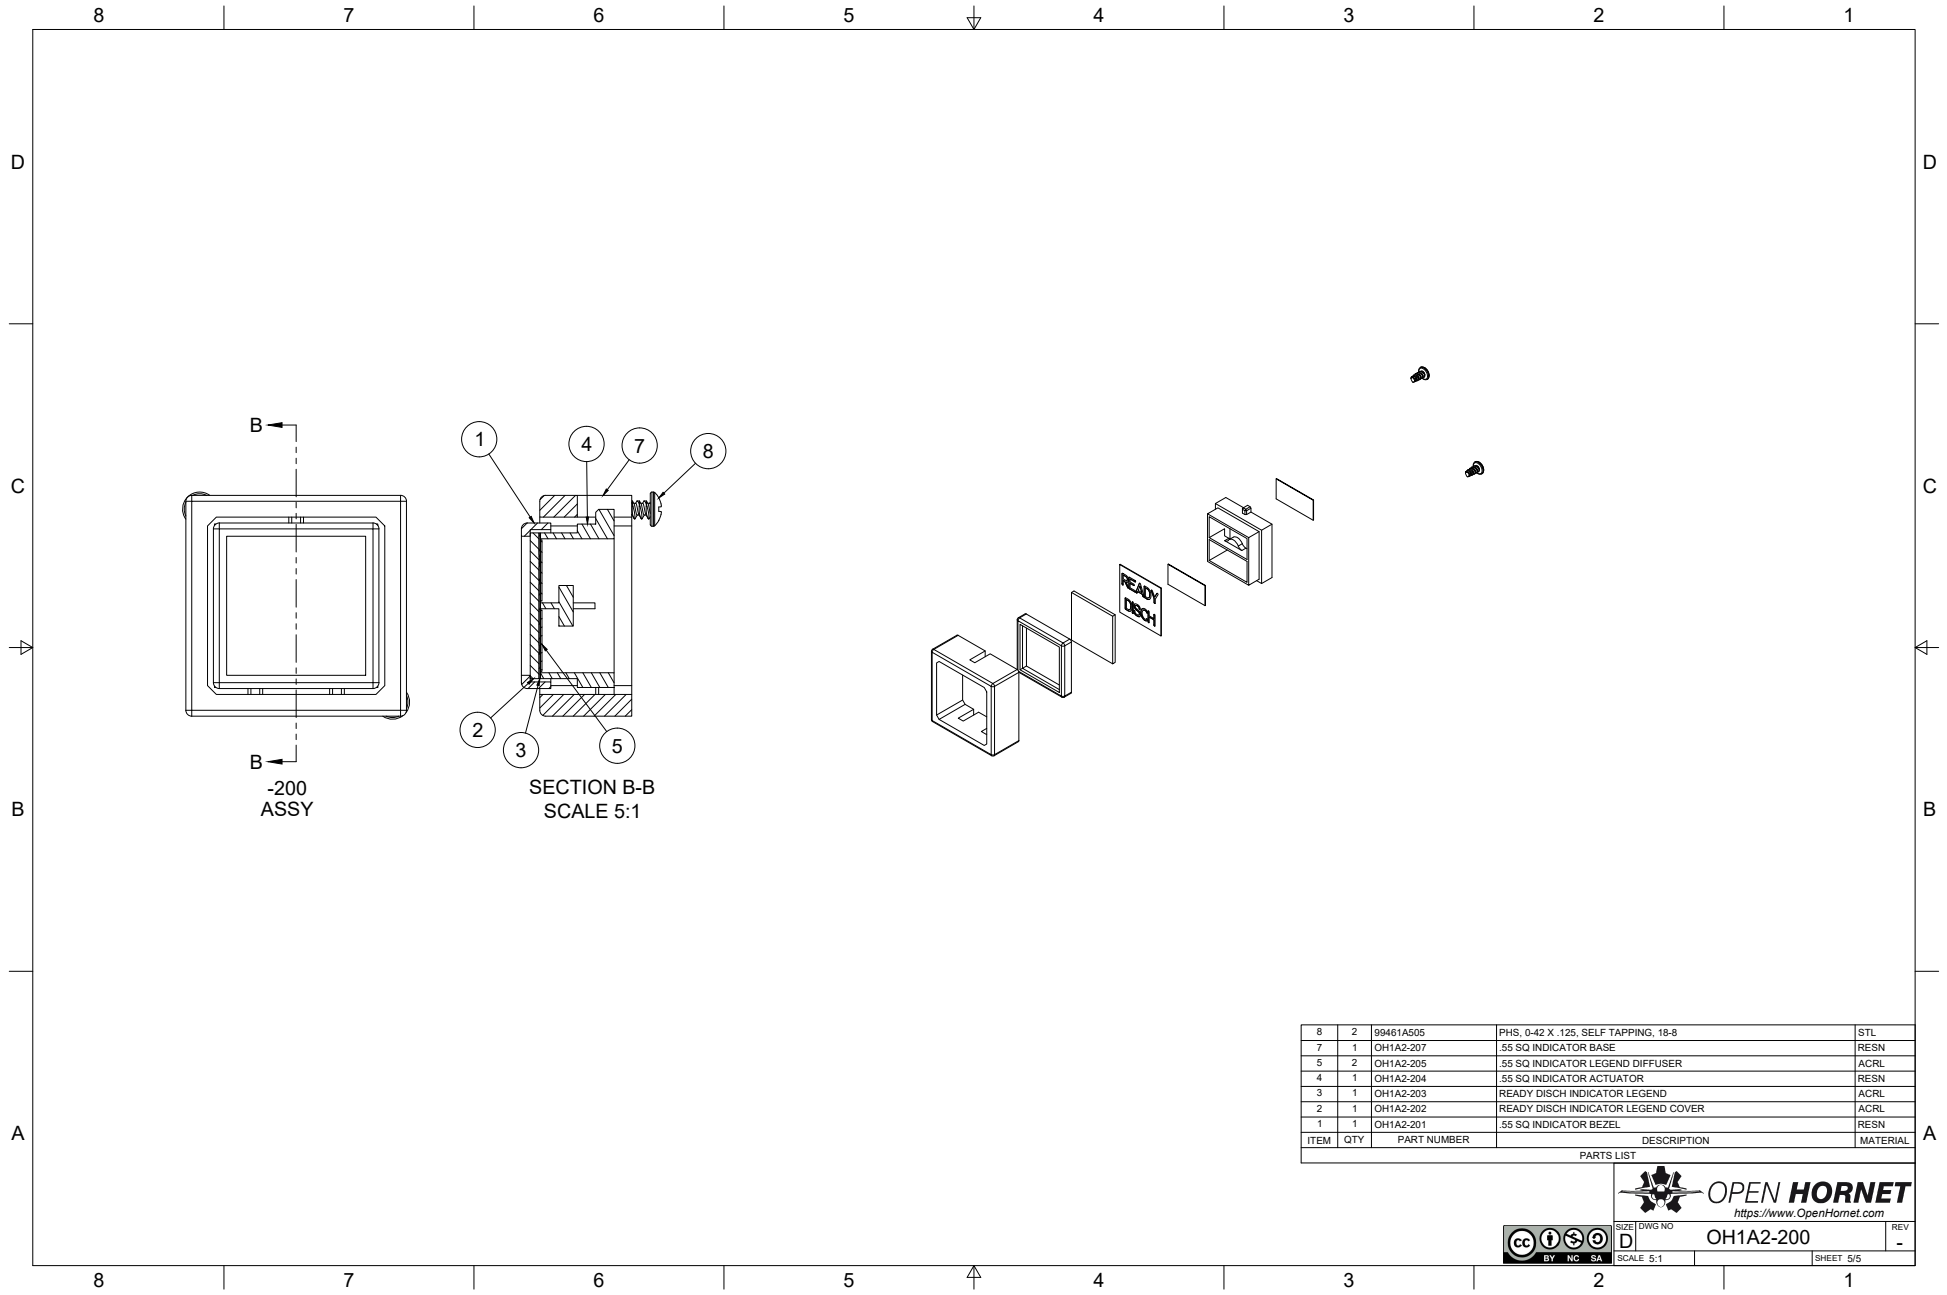
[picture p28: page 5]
PARTS LIST; SECTION B-B SCALE 5:1

8 | 2 | 99461A505 | PHS, 0-42 X .125, SELF TAPPING, 18-8 | STL
7 | 1 | OH1A2-207 | .55 SQ INDICATOR BASE | RESN
5 | 2 | OH1A2-205 | .55 SQ INDICATOR LEGEND DIFFUSER | ACRL
4 | 1 | OH1A2-204 | .55 SQ INDICATOR ACTUATOR | RESN
3 | 1 | OH1A2-203 | READY DISCH INDICATOR LEGEND | ACRL
2 | 1 | OH1A2-202 | READY DISCH INDICATOR LEGEND COVER | ACRL
1 | 1 | OH1A2-201 | .55 SQ INDICATOR BEZEL | RESN
ITEM | QTY | PART NUMBER | DESCRIPTION | MATERIAL

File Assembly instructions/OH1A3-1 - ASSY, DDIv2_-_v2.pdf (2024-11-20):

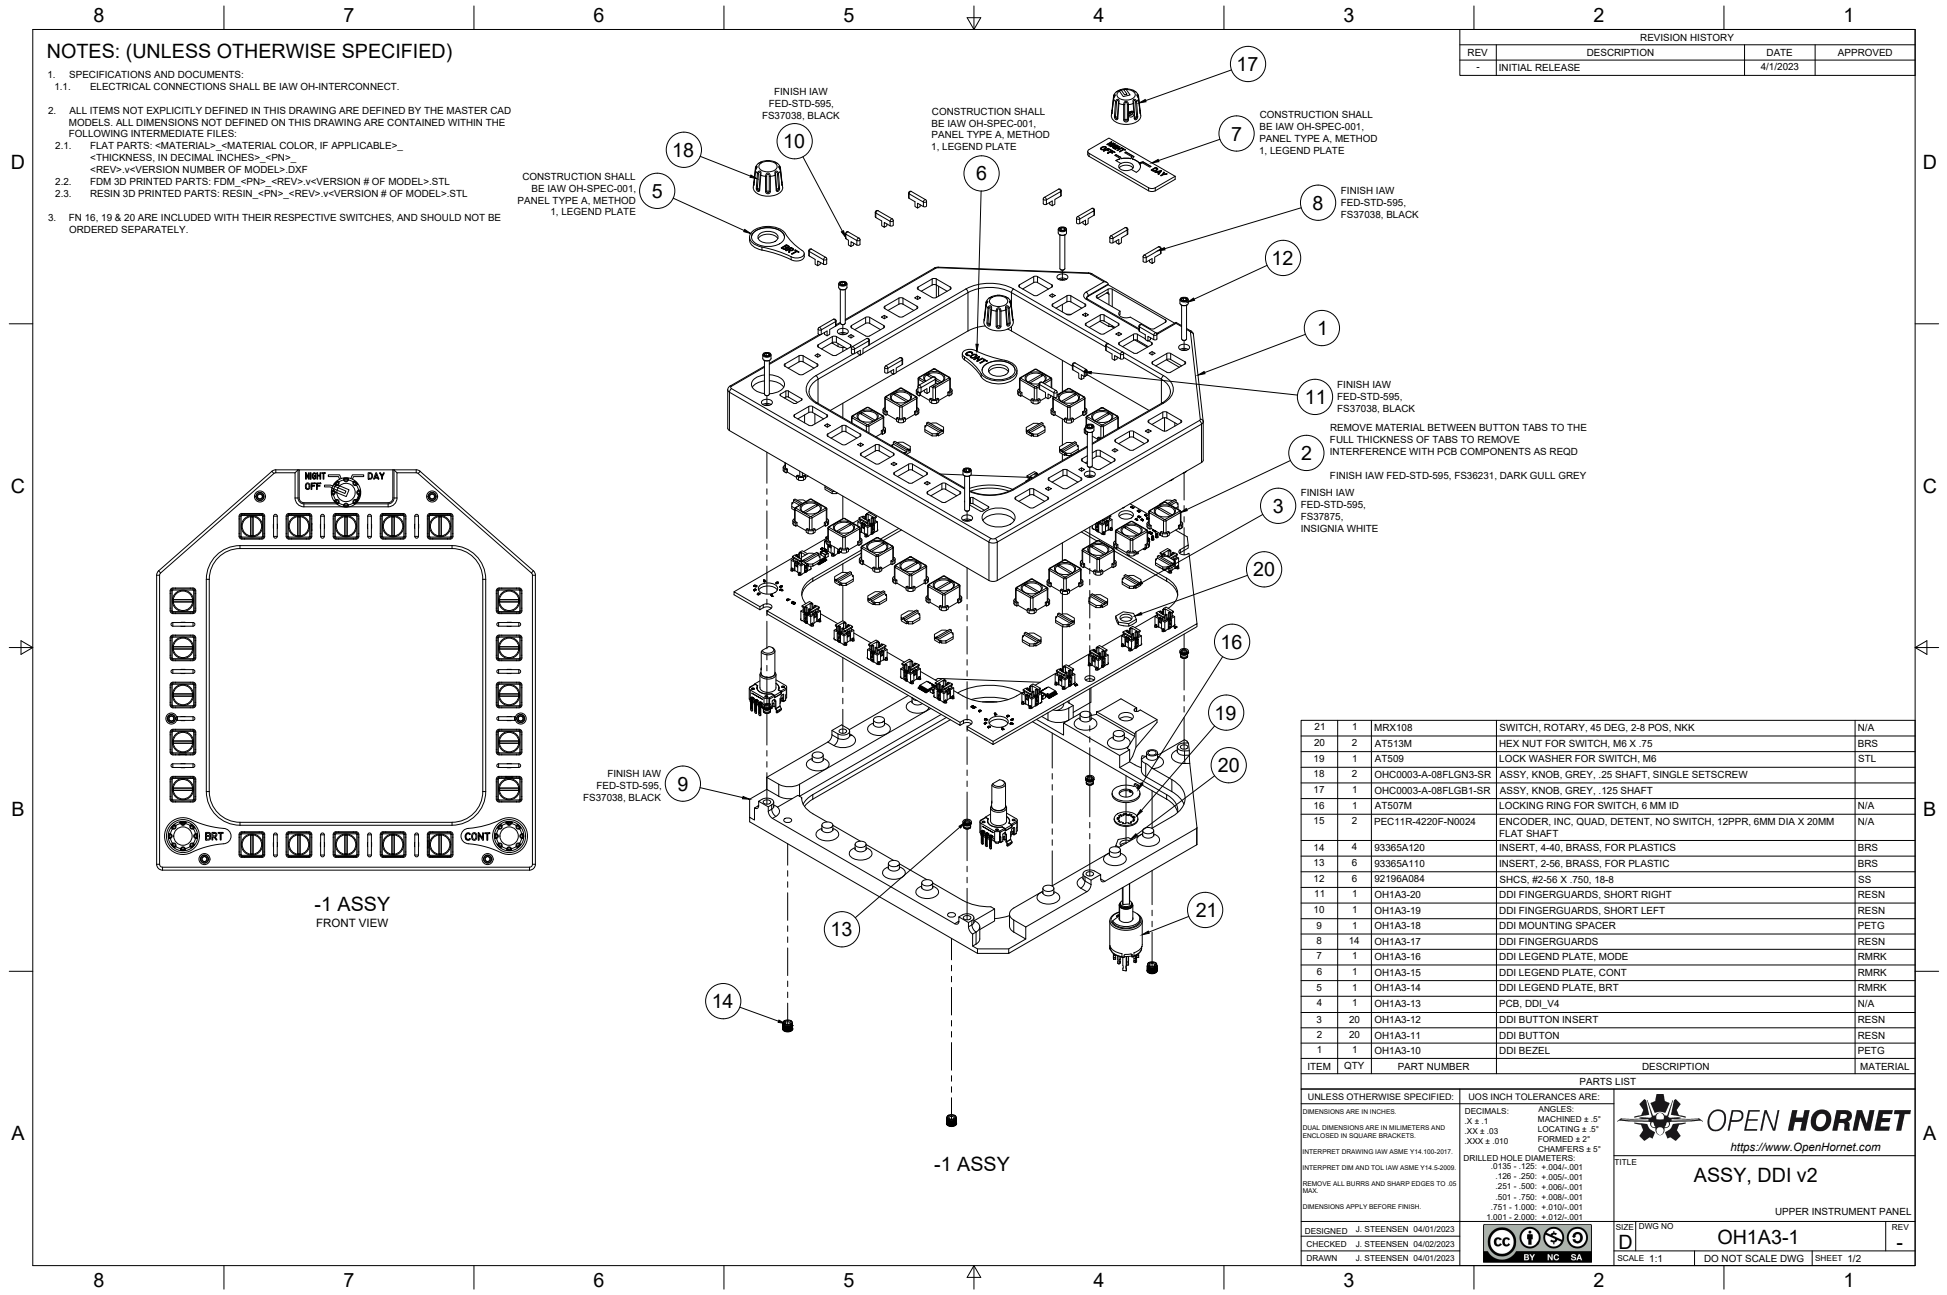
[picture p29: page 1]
SIZE DWG NO; REV; .X ± .1 .XX ± .03 .XXX ± .010; MACHINED ± .5° LOCATING ± .5° FORMED ± 2° CHAMFERS ± 5°; UNLESS OTHERWISE SPECIFIED:; UOS INCH TOLERANCES ARE:; J. STEENSEN 04/01/2023; DO NOT SCALE DWG; J. STEENSEN 04/02/2023; PARTS LIST; ITEM; QTY; PART NUMBER; DESCRIPTION; MATERIAL; DDI BEZEL; PETG; DDI BUTTON; RESN; DDI BUTTON INSERT; PCB, DDI_V4; DDI LEGEND PLATE, BRT; RMRK; DDI LEGEND PLATE, CONT; DDI LEGEND PLATE, MODE; DDI FINGERGUARDS; DDI MOUNTING SPACER; DDI FINGERGUARDS, SHORT LEFT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

NOTES: (UNLESS OTHERWISE SPECIFIED)

1. SPECIFICATIONS AND DOCUMENTS:
1.1. ELECTRICAL CONNECTIONS SHALL BE IAW OH-INTERCONNECT.

2. ALL ITEMS NOT EXPLICITLY DEFINED IN THIS DRAWING ARE DEFINED BY THE MASTER CAD
MODELS. ALL DIMENSIONS NOT DEFINED ON THIS DRAWING ARE CONTAINED WITHIN THE
FOLLOWING INTERMEDIATE FILES:
2.1. FLAT PARTS: <MATERIAL>_<MATERIAL COLOR, IF APPLICABLE>_

CONSTRUCTION SHALL
BE IAW OH-SPEC-001,
PANEL TYPE A, METHOD
1, LEGEND PLATE

<THICKNESS, IN DECIMAL INCHES>_<PN>_
<REV>.v<VERSION NUMBER OF MODEL>.DXF

2.2. FDM 3D PRINTED PARTS: FDM_<PN>_<REV>.v<VERSION # OF MODEL>.STL
2.3. RESIN 3D PRINTED PARTS: RESIN_<PN>_<REV>.v<VERSION # OF MODEL>.STL

3. FN 16, 19 & 20 ARE INCLUDED WITH THEIR RESPECTIVE SWITCHES, AND SHOULD NOT BE
ORDERED SEPARATELY.

REMOVE MATERIAL BETWEEN BUTTON TABS TO THE
FULL THICKNESS OF TABS TO REMOVE

INTERFERENCE WITH PCB COMPONENTS AS REQD

FINISH IAW FED-STD-595, FS36231, DARK GULL GREY

DIMENSIONS ARE IN INCHES.

DUAL DIMENSIONS ARE IN MILIMETERS AND
ENCLOSED IN SQUARE BRACKETS.

https://www.OpenHornet.com
ASSY, DDI v2

INTERPRET DRAWING IAW ASME Y14.100-2017.

DRILLED HOLE DIAMETERS:

INTERPRET DIM AND TOL IAW ASME Y14.5-2009.

REMOVE ALL BURRS AND SHARP EDGES TO .05
MAX.

DIMENSIONS APPLY BEFORE FINISH.

UPPER INSTRUMENT PANEL

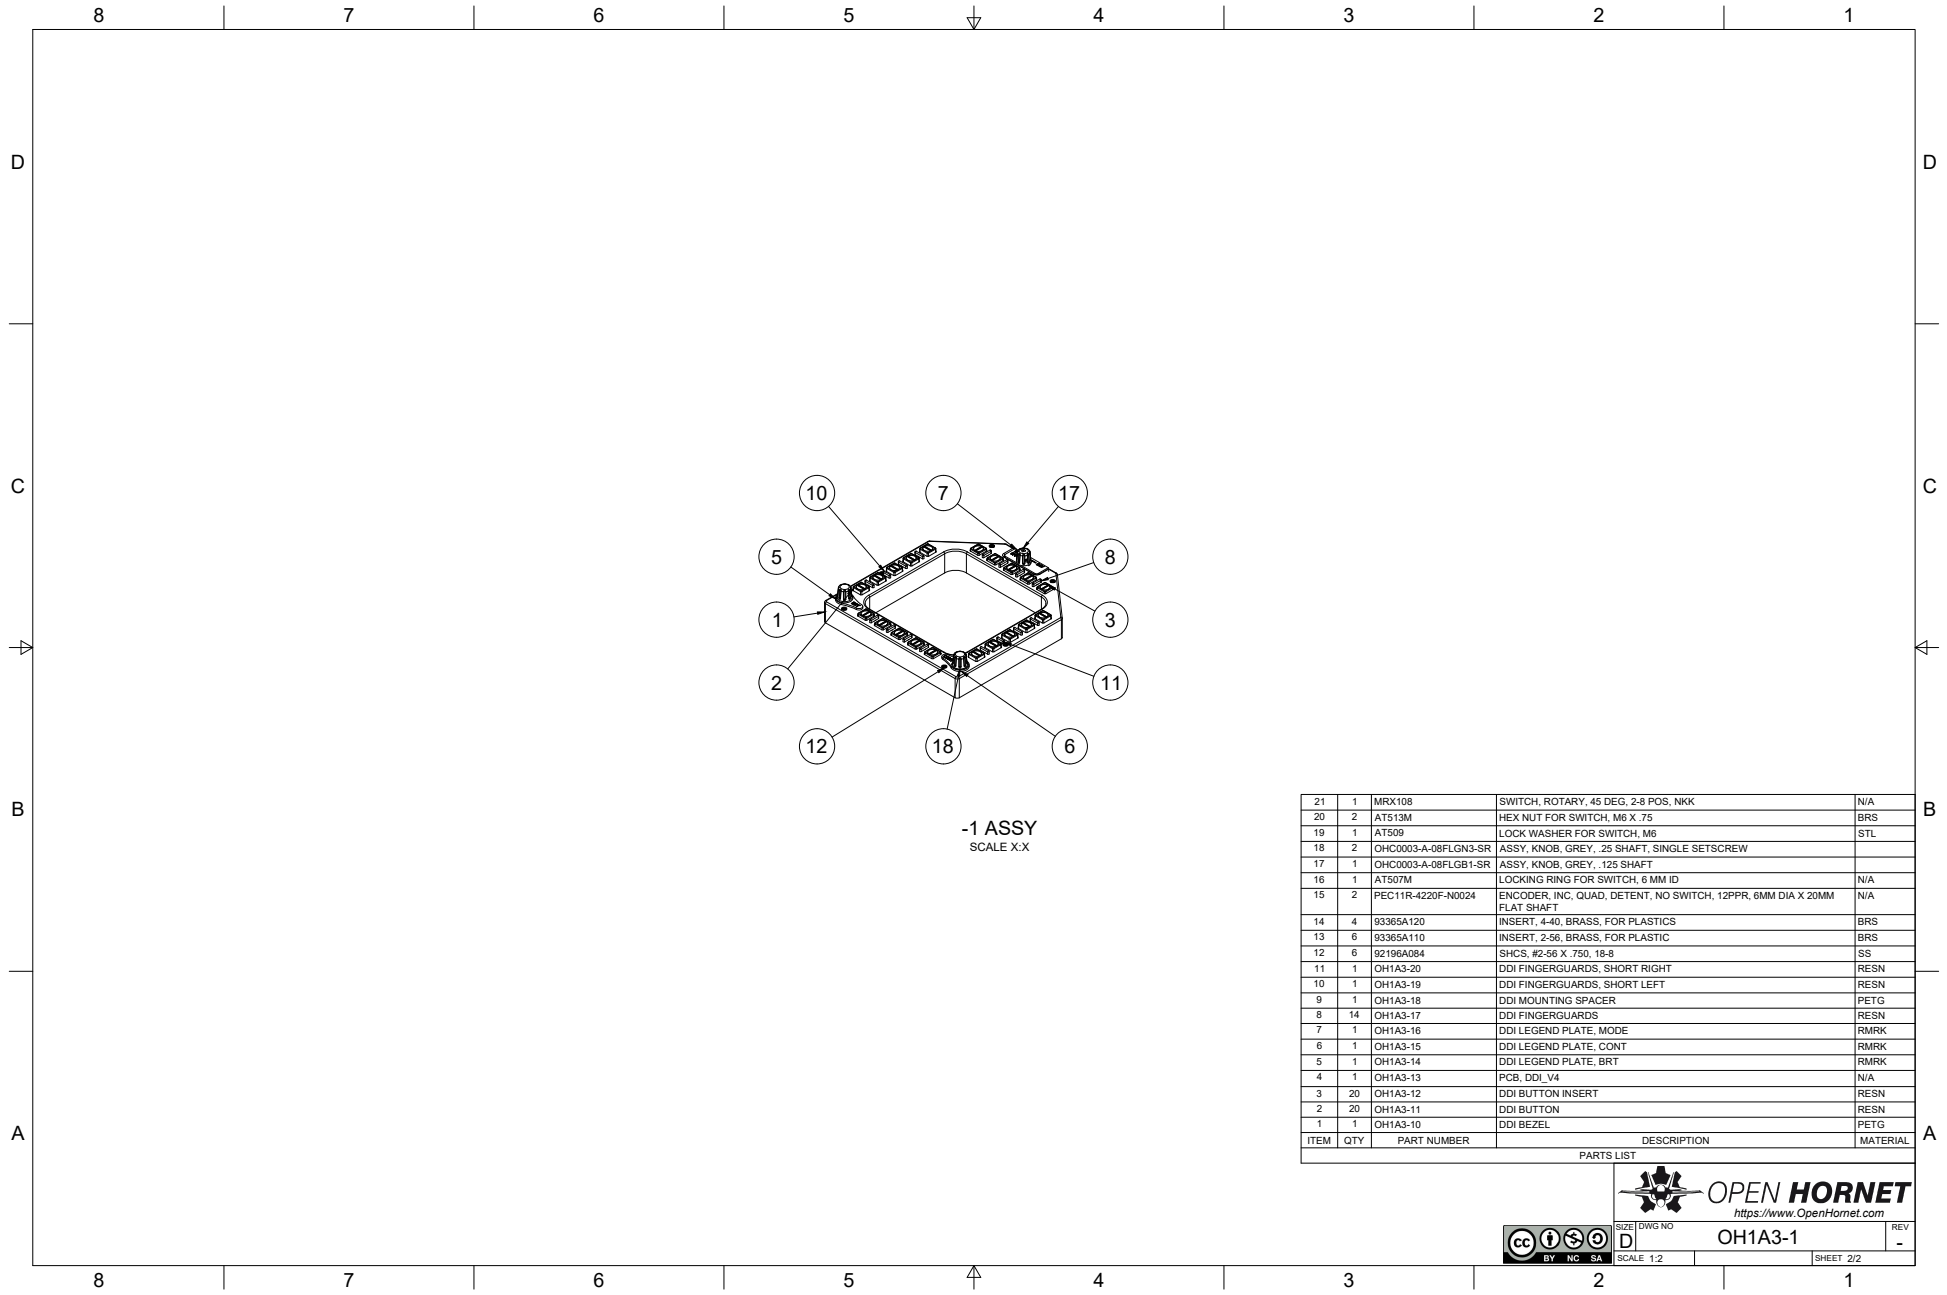
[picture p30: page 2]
PARTS LIST; -1 ASSY; SCALE X:X

21 | 1 | MRX108 | SWITCH, ROTARY, 45 DEG, 2-8 POS, NKK | N/A
20 | 2 | AT513M | HEX NUT FOR SWITCH, M6 X .75 | BRS
19 | 1 | AT509 | LOCK WASHER FOR SWITCH, M6 | STL
18 | 2 | OHC0003-A-08FLGN3-SR | ASSY, KNOB, GREY, .25 SHAFT, SINGLE SETSCREW
17 | 1 | OHC0003-A-08FLGB1-SR | ASSY, KNOB, GREY, .125 SHAFT
16 | 1 | AT507M | LOCKING RING FOR SWITCH, 6 MM ID | N/A
15 | 2 | PEC11R-4220F-N0024 | ENCODER, INC, QUAD, DETENT, NO SWITCH, 12PPR, 6MM DIA X 20MM FLAT SHAFT | N/A

14 | 4 | 93365A120 | INSERT, 4-40, BRASS, FOR PLASTICS | BRS
13 | 6 | 93365A110 | INSERT, 2-56, BRASS, FOR PLASTIC | BRS
12 | 6 | 92196A084 | SHCS, #2-56 X .750, 18-8 | SS
11 | 1 | OH1A3-20 | DDI FINGERGUARDS, SHORT RIGHT | RESN
10 | 1 | OH1A3-19 | DDI FINGERGUARDS, SHORT LEFT | RESN
9 | 1 | OH1A3-18 | DDI MOUNTING SPACER | PETG
8 | 14 | OH1A3-17 | DDI FINGERGUARDS | RESN
7 | 1 | OH1A3-16 | DDI LEGEND PLATE, MODE | RMRK
6 | 1 | OH1A3-15 | DDI LEGEND PLATE, CONT | RMRK
5 | 1 | OH1A3-14 | DDI LEGEND PLATE, BRT | RMRK
4 | 1 | OH1A3-13 | PCB, DDI_V4 | N/A
3 | 20 | OH1A3-12 | DDI BUTTON INSERT | RESN
2 | 20 | OH1A3-11 | DDI BUTTON | RESN
1 | 1 | OH1A3-10 | DDI BEZEL | PETG
ITEM | QTY | PART NUMBER | DESCRIPTION | MATERIAL

https://www.OpenHornet.com

SIZE D | DWG NO OH1A3-1 | REV -

1:2 SCALE | | 2/2 SHEET

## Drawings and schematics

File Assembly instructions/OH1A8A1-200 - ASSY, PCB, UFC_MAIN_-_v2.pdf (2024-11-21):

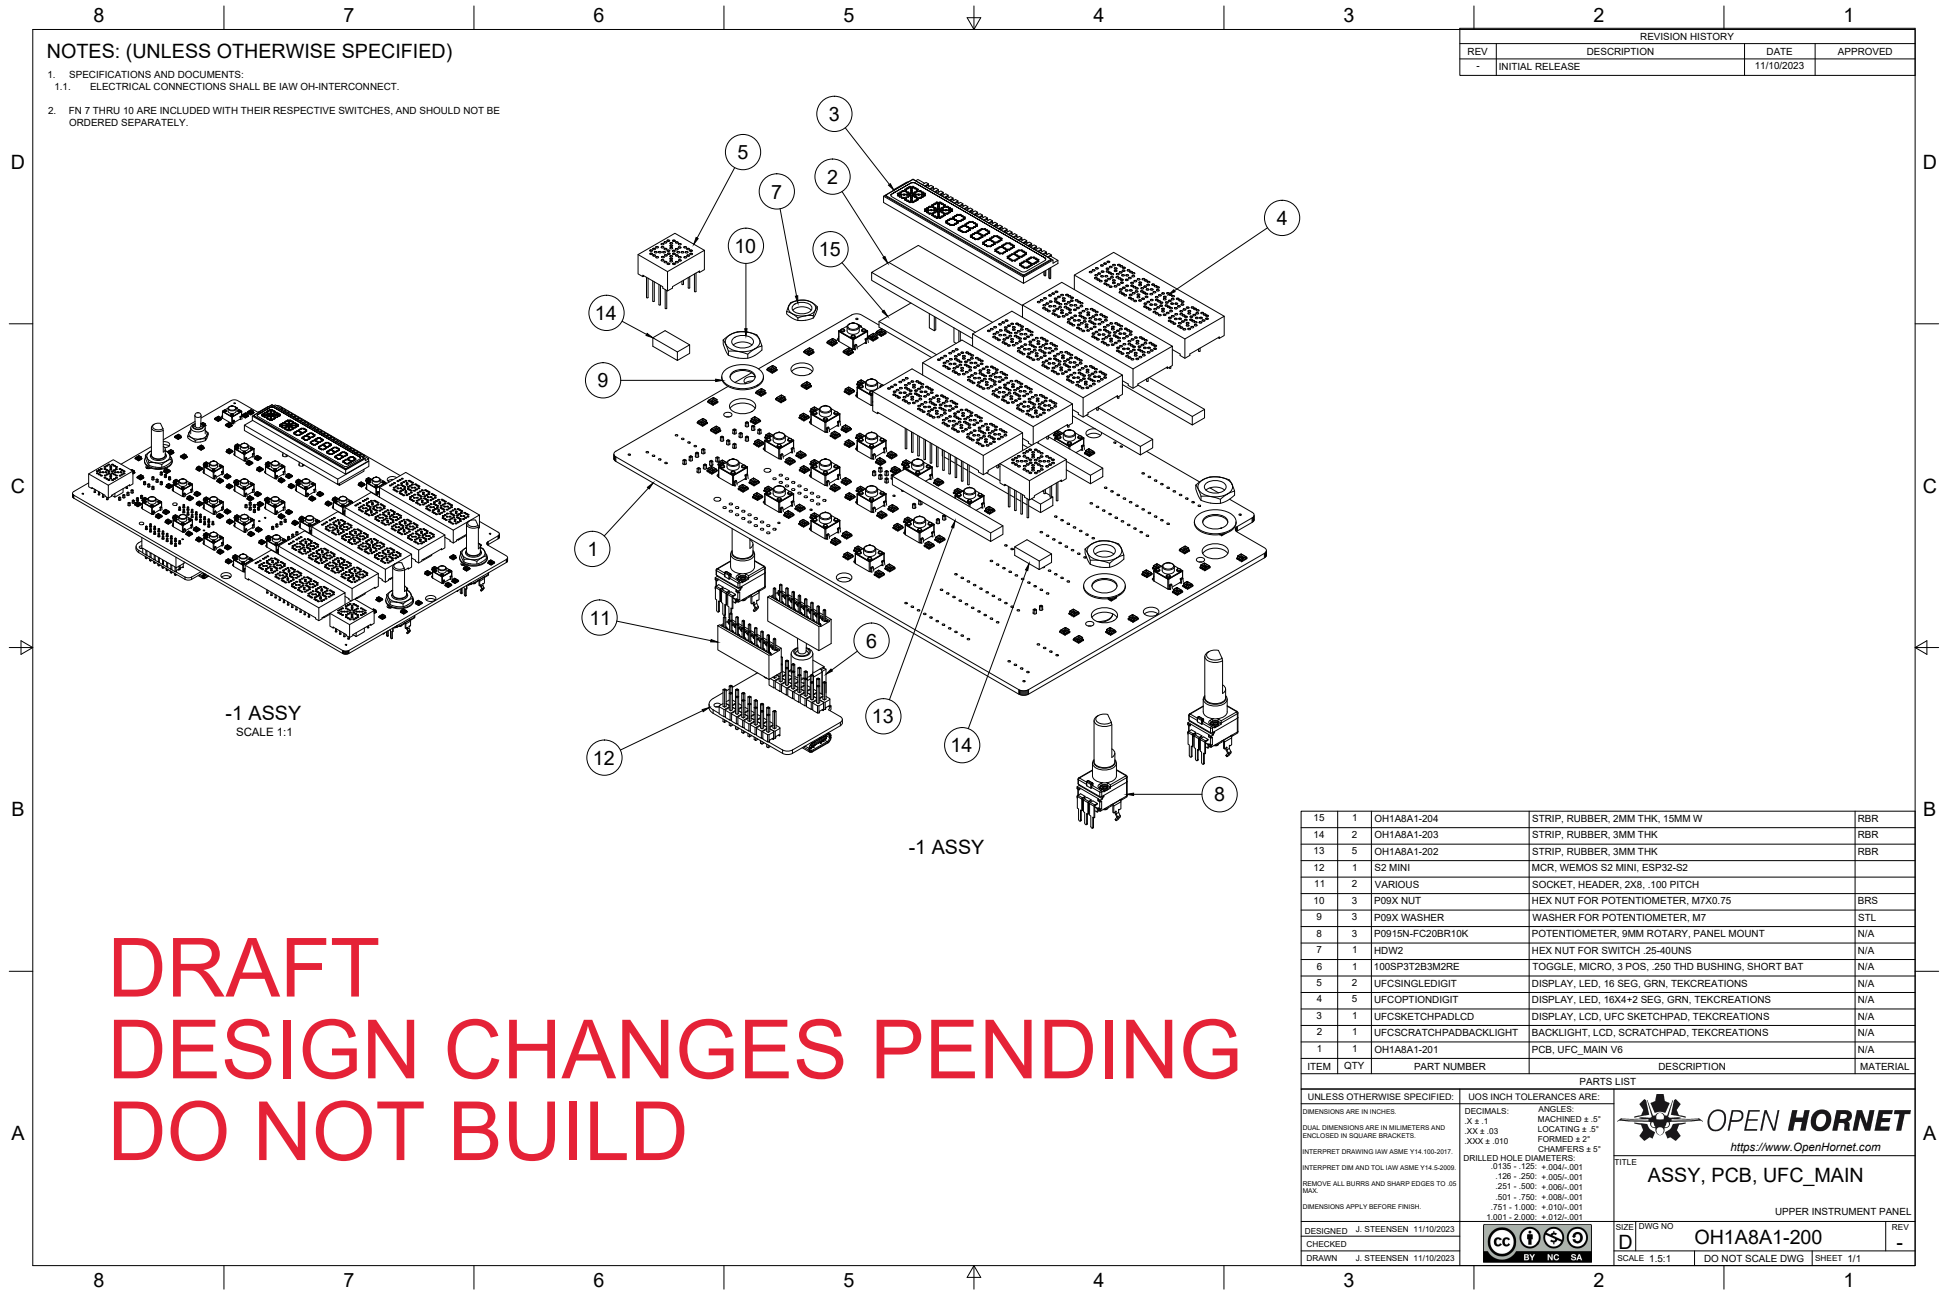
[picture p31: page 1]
SIZE DWG NO; REV; .X ± .1 .XX ± .03 .XXX ± .010; MACHINED ± .5° LOCATING ± .5° FORMED ± 2° CHAMFERS ± 5°; UNLESS OTHERWISE SPECIFIED:; UOS INCH TOLERANCES ARE:; J. STEENSEN 11/10/2023; DO NOT SCALE DWG; ASSY, PCB, UFC_MAIN; PARTS LIST; ITEM; QTY; PART NUMBER; DESCRIPTION; MATERIAL; PCB, UFC_MAIN V6; UFCSCRATCHPADBACKLIGHT; BACKLIGHT, LCD, SCRATCHPAD, TEKCREATIONS; UFCSKETCHPADLCD; DISPLAY, LCD, UFC SKETCHPAD, TEKCREATIONS; UFCOPTIONDIGIT; DISPLAY, LED, 16X4+2 SEG, GRN, TEKCREATIONS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

NOTES: (UNLESS OTHERWISE SPECIFIED)

1. SPECIFICATIONS AND DOCUMENTS:
1.1. ELECTRICAL CONNECTIONS SHALL BE IAW OH-INTERCONNECT.

2. FN 7 THRU 10 ARE INCLUDED WITH THEIR RESPECTIVE SWITCHES, AND SHOULD NOT BE

-1 ASSY
DRAFT
DESIGN CHANGES PENDING
DO NOT BUILD

DIMENSIONS ARE IN INCHES.

DUAL DIMENSIONS ARE IN MILIMETERS AND
ENCLOSED IN SQUARE BRACKETS.

https://www.OpenHornet.com

INTERPRET DRAWING IAW ASME Y14.100-2017.

DRILLED HOLE DIAMETERS:

INTERPRET DIM AND TOL IAW ASME Y14.5-2009.

REMOVE ALL BURRS AND SHARP EDGES TO .05
MAX.

DIMENSIONS APPLY BEFORE FINISH.

UPPER INSTRUMENT PANEL

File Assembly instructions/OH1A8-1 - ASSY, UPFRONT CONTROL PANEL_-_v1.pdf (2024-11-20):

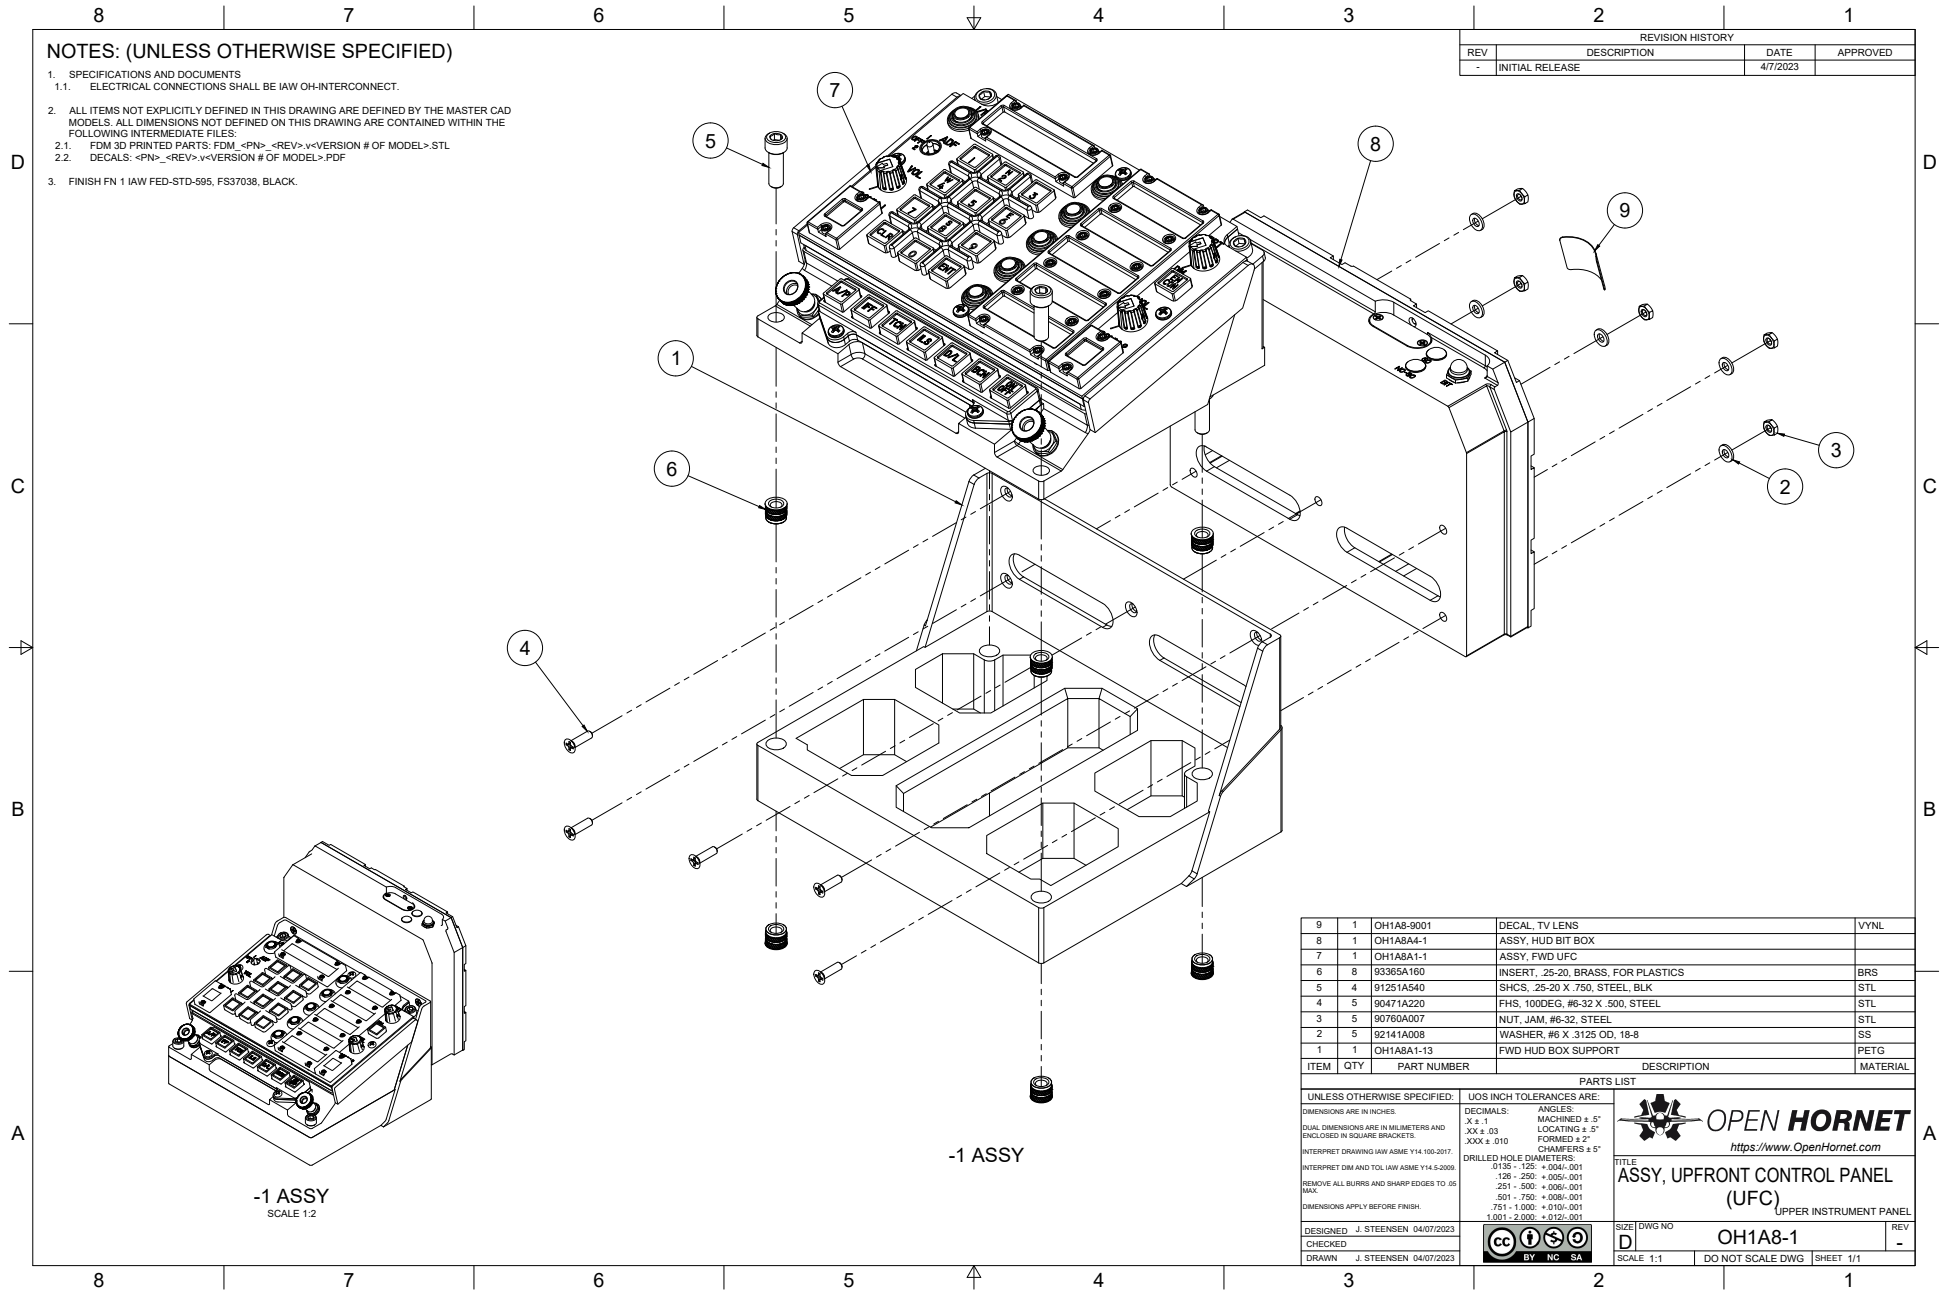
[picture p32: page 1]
SIZE DWG NO; REV; .X ± .1 .XX ± .03 .XXX ± .010; MACHINED ± .5° LOCATING ± .5° FORMED ± 2° CHAMFERS ± 5°; UNLESS OTHERWISE SPECIFIED:; UOS INCH TOLERANCES ARE:; J. STEENSEN 04/07/2023; DO NOT SCALE DWG; PARTS LIST; ITEM; QTY; PART NUMBER; DESCRIPTION; MATERIAL; FWD HUD BOX SUPPORT; PETG; WASHER, #6 X .3125 OD, 18-8; NUT, JAM, #6-32, STEEL; STL; FHS, 100DEG, #6-32 X .500, STEEL; SHCS, .25-20 X .750, STEEL, BLK; INSERT, .25-20, BRASS, FOR PLASTICS; BRS; ASSY, FWD UFC; ASSY, HUD BIT BOX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

NOTES: (UNLESS OTHERWISE SPECIFIED)

1. SPECIFICATIONS AND DOCUMENTS
1.1. ELECTRICAL CONNECTIONS SHALL BE IAW OH-INTERCONNECT.

2. ALL ITEMS NOT EXPLICITLY DEFINED IN THIS DRAWING ARE DEFINED BY THE MASTER CAD
MODELS. ALL DIMENSIONS NOT DEFINED ON THIS DRAWING ARE CONTAINED WITHIN THE
FOLLOWING INTERMEDIATE FILES:
2.1. FDM 3D PRINTED PARTS: FDM_<PN>_<REV>.v<VERSION # OF MODEL>.STL
2.2. DECALS: <PN>_<REV>.v<VERSION # OF MODEL>.PDF

3. FINISH FN 1 IAW FED-STD-595, FS37038, BLACK.

DIMENSIONS ARE IN INCHES.

DUAL DIMENSIONS ARE IN MILIMETERS AND
ENCLOSED IN SQUARE BRACKETS.

https://www.OpenHornet.com

INTERPRET DRAWING IAW ASME Y14.100-2017.

DRILLED HOLE DIAMETERS:

TITLE
ASSY, UPFRONT CONTROL PANEL

INTERPRET DIM AND TOL IAW ASME Y14.5-2009.

REMOVE ALL BURRS AND SHARP EDGES TO .05
MAX.

UPPER INSTRUMENT PANEL (UFC)

DIMENSIONS APPLY BEFORE FINISH.

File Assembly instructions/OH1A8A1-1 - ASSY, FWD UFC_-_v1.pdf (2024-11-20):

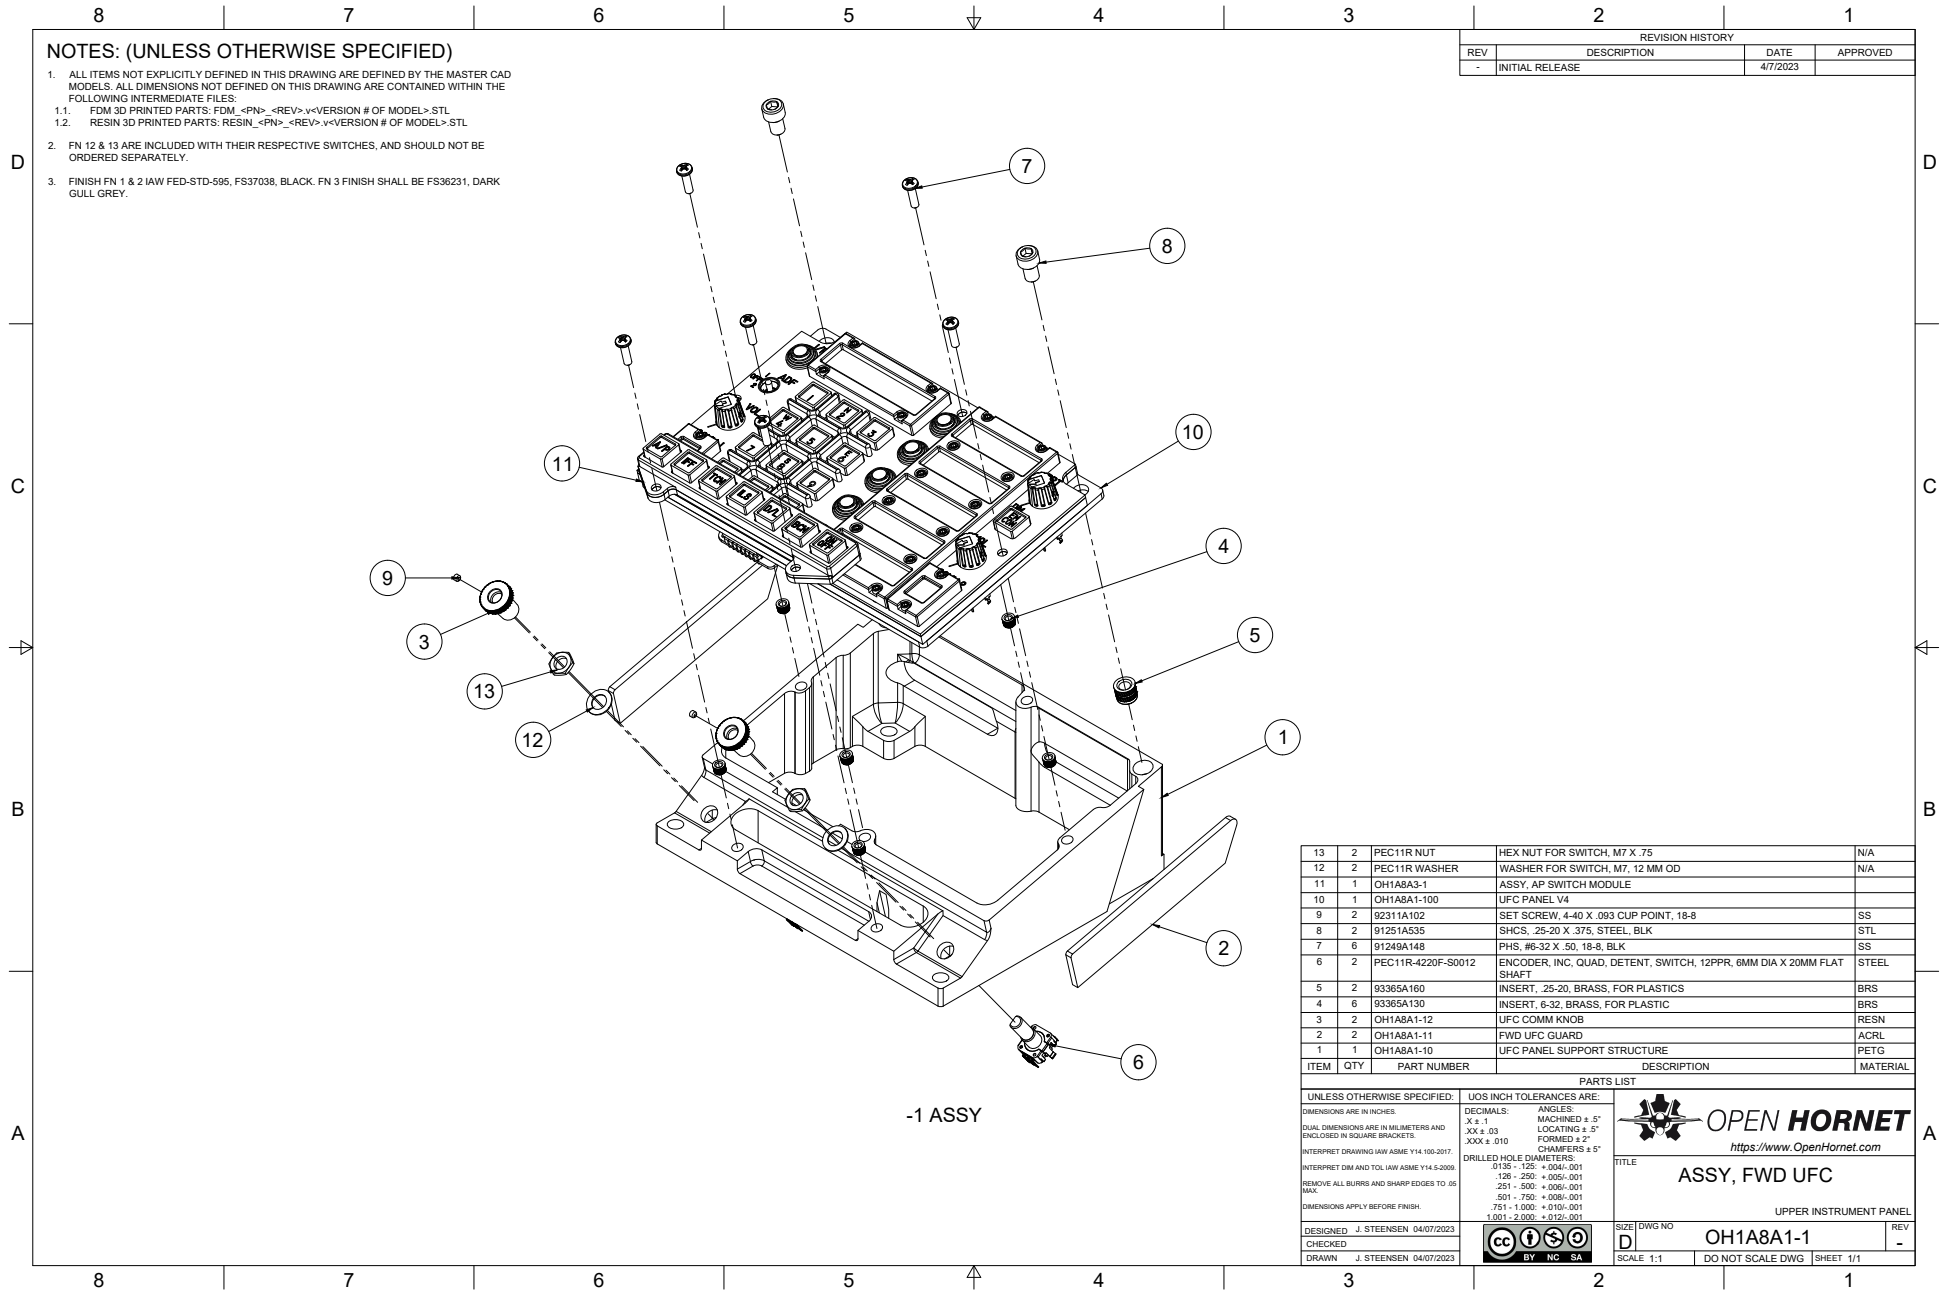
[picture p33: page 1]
SIZE DWG NO; REV; .X ± .1 .XX ± .03 .XXX ± .010; MACHINED ± .5° LOCATING ± .5° FORMED ± 2° CHAMFERS ± 5°; UNLESS OTHERWISE SPECIFIED:; UOS INCH TOLERANCES ARE:; J. STEENSEN 04/07/2023; DO NOT SCALE DWG; PARTS LIST; ITEM; QTY; PART NUMBER; DESCRIPTION; MATERIAL; UFC PANEL SUPPORT STRUCTURE; PETG; FWD UFC GUARD; ACRL; UFC COMM KNOB; RESN; INSERT, 6-32, BRASS, FOR PLASTIC; BRS; INSERT, .25-20, BRASS, FOR PLASTICS; PEC11R-4220F-S0012; ENCODER, INC, QUAD, DETENT, SWITCH, 12PPR, 6MM DIA X 20MM FLAT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

NOTES: (UNLESS OTHERWISE SPECIFIED)

1. ALL ITEMS NOT EXPLICITLY DEFINED IN THIS DRAWING ARE DEFINED BY THE MASTER CAD
MODELS. ALL DIMENSIONS NOT DEFINED ON THIS DRAWING ARE CONTAINED WITHIN THE
FOLLOWING INTERMEDIATE FILES:
1.1. FDM 3D PRINTED PARTS: FDM_<PN>_<REV>.v<VERSION # OF MODEL>.STL
1.2. RESIN 3D PRINTED PARTS: RESIN_<PN>_<REV>.v<VERSION # OF MODEL>.STL

2. FN 12 & 13 ARE INCLUDED WITH THEIR RESPECTIVE SWITCHES, AND SHOULD NOT BE
ORDERED SEPARATELY.

3. FINISH FN 1 & 2 IAW FED-STD-595, FS37038, BLACK. FN 3 FINISH SHALL BE FS36231, DARK
GULL GREY.

DIMENSIONS ARE IN INCHES.

DUAL DIMENSIONS ARE IN MILIMETERS AND
ENCLOSED IN SQUARE BRACKETS.

https://www.OpenHornet.com
ASSY, FWD UFC

INTERPRET DRAWING IAW ASME Y14.100-2017.

DRILLED HOLE DIAMETERS:

INTERPRET DIM AND TOL IAW ASME Y14.5-2009.

REMOVE ALL BURRS AND SHARP EDGES TO .05
MAX.

DIMENSIONS APPLY BEFORE FINISH.

UPPER INSTRUMENT PANEL

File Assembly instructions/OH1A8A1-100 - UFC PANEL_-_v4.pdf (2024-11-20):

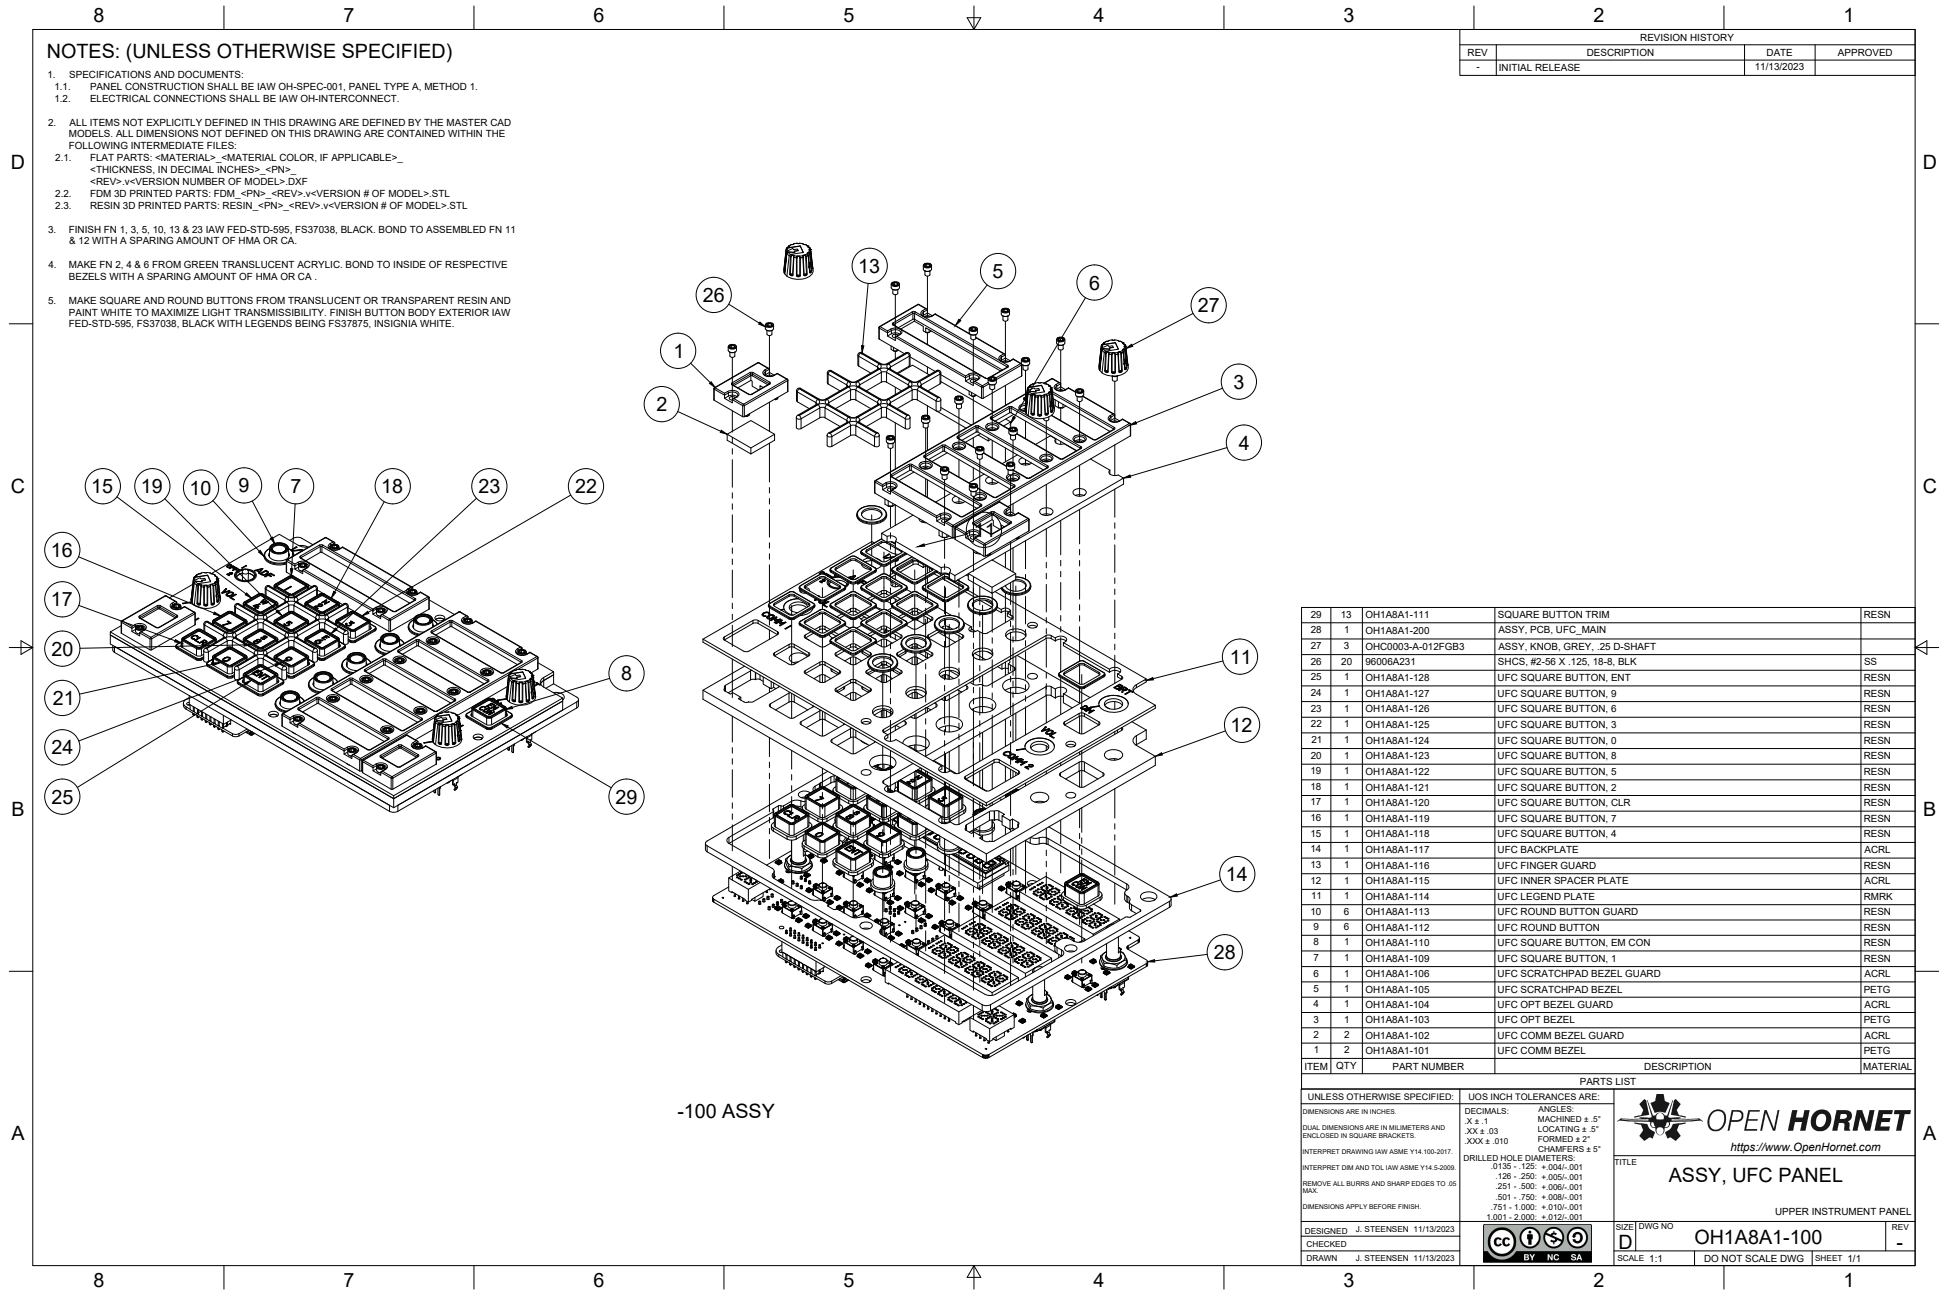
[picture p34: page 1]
SIZE DWG NO; REV; .X ± .1 .XX ± .03 .XXX ± .010; MACHINED ± .5° LOCATING ± .5° FORMED ± 2° CHAMFERS ± 5°; UNLESS OTHERWISE SPECIFIED:; UOS INCH TOLERANCES ARE:; J. STEENSEN 11/13/2023; DO NOT SCALE DWG; -100 ASSY; REVISION HISTORY; INITIAL RELEASE; PARTS LIST; ITEM QTY; PART NUMBER; DESCRIPTION; MATERIAL; UFC COMM BEZEL; PETG; UFC COMM BEZEL GUARD; ACRL; UFC OPT BEZEL; UFC OPT BEZEL GUARD; UFC SCRATCHPAD BEZEL; UFC SCRATCHPAD BEZEL GUARD; UFC SQUARE BUTTON, 1; RESN; UFC SQUARE BUTTON, EM CON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

NOTES: (UNLESS OTHERWISE SPECIFIED)

1. SPECIFICATIONS AND DOCUMENTS:
1.1. PANEL CONSTRUCTION SHALL BE IAW OH-SPEC-001, PANEL TYPE A, METHOD 1.
1.2. ELECTRICAL CONNECTIONS SHALL BE IAW OH-INTERCONNECT.

2. ALL ITEMS NOT EXPLICITLY DEFINED IN THIS DRAWING ARE DEFINED BY THE MASTER CAD
MODELS. ALL DIMENSIONS NOT DEFINED ON THIS DRAWING ARE CONTAINED WITHIN THE
FOLLOWING INTERMEDIATE FILES:
2.1. FLAT PARTS: <MATERIAL>_<MATERIAL COLOR, IF APPLICABLE>_

<THICKNESS, IN DECIMAL INCHES>_<PN>_
<REV>.v<VERSION NUMBER OF MODEL>.DXF

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

3. FINISH FN 1, 3, 5, 10, 13 & 23 IAW FED-STD-595, FS37038, BLACK. BOND TO ASSEMBLED FN 11
& 12 WITH A SPARING AMOUNT OF HMA OR CA.

4. MAKE FN 2, 4 & 6 FROM GREEN TRANSLUCENT ACRYLIC. BOND TO INSIDE OF RESPECTIVE
BEZELS WITH A SPARING AMOUNT OF HMA OR CA .

5. MAKE SQUARE AND ROUND BUTTONS FROM TRANSLUCENT OR TRANSPARENT RESIN AND
PAINT WHITE TO MAXIMIZE LIGHT TRANSMISSIBILITY. FINISH BUTTON BODY EXTERIOR IAW
FED-STD-595, FS37038, BLACK WITH LEGENDS BEING FS37875, INSIGNIA WHITE.

DIMENSIONS ARE IN INCHES.

DUAL DIMENSIONS ARE IN MILIMETERS AND
ENCLOSED IN SQUARE BRACKETS.

https://www.OpenHornet.com

INTERPRET DRAWING IAW ASME Y14.100-2017.

DRILLED HOLE DIAMETERS:

TITLE
ASSY, UFC PANEL

INTERPRET DIM AND TOL IAW ASME Y14.5-2009.

REMOVE ALL BURRS AND SHARP EDGES TO .05
MAX.

DIMENSIONS APPLY BEFORE FINISH.

UPPER INSTRUMENT PANEL

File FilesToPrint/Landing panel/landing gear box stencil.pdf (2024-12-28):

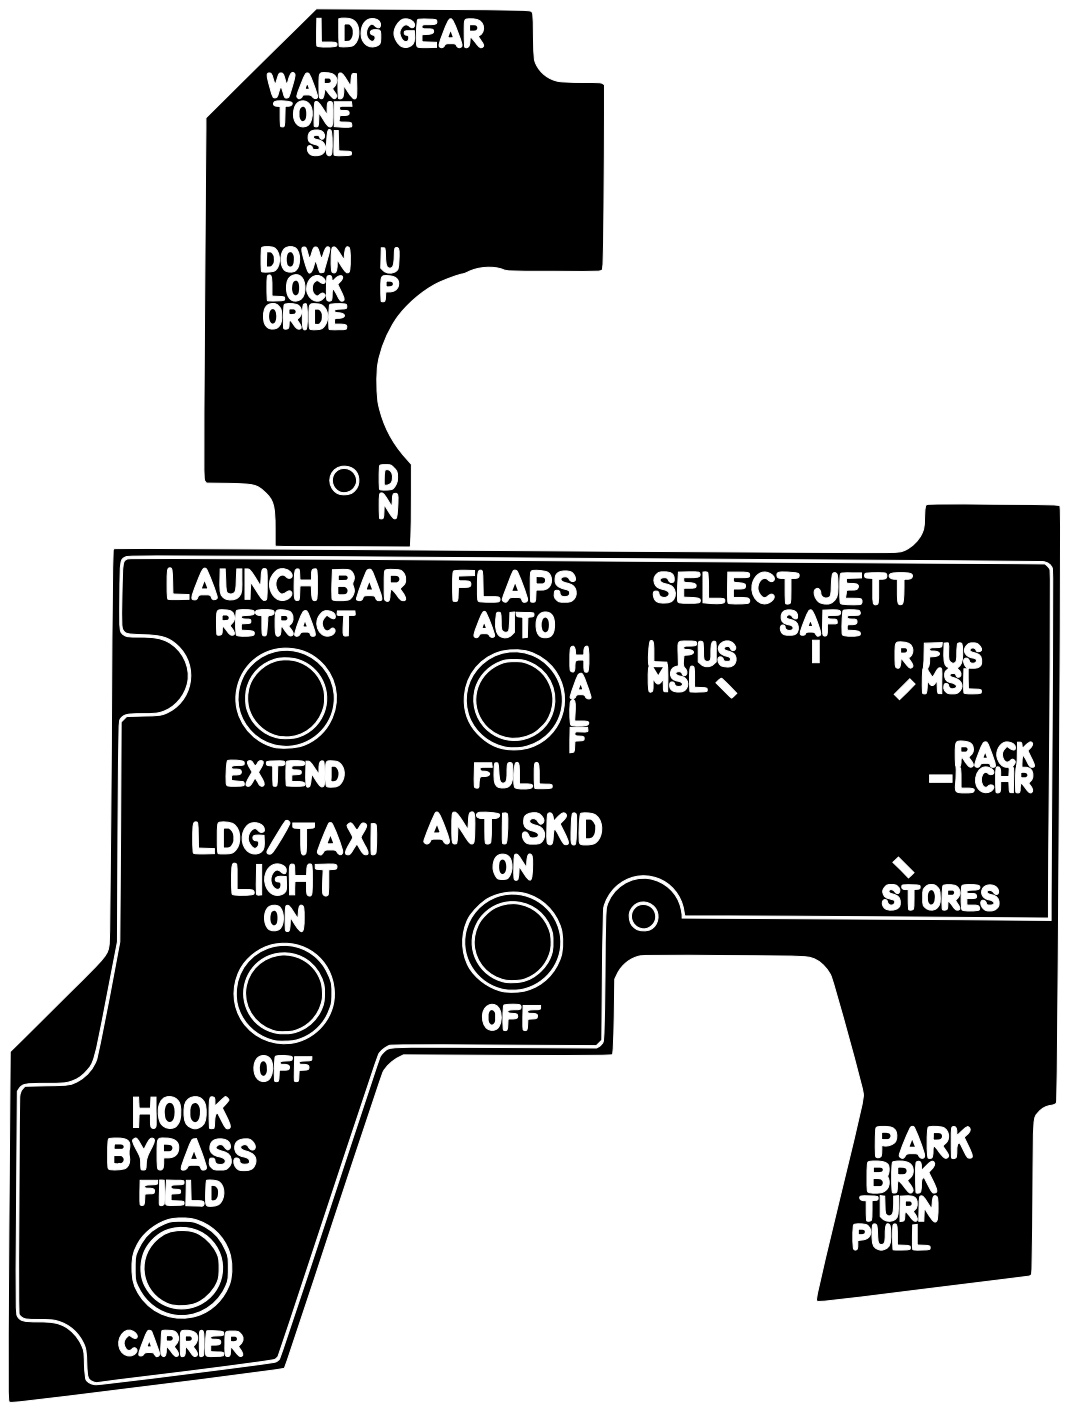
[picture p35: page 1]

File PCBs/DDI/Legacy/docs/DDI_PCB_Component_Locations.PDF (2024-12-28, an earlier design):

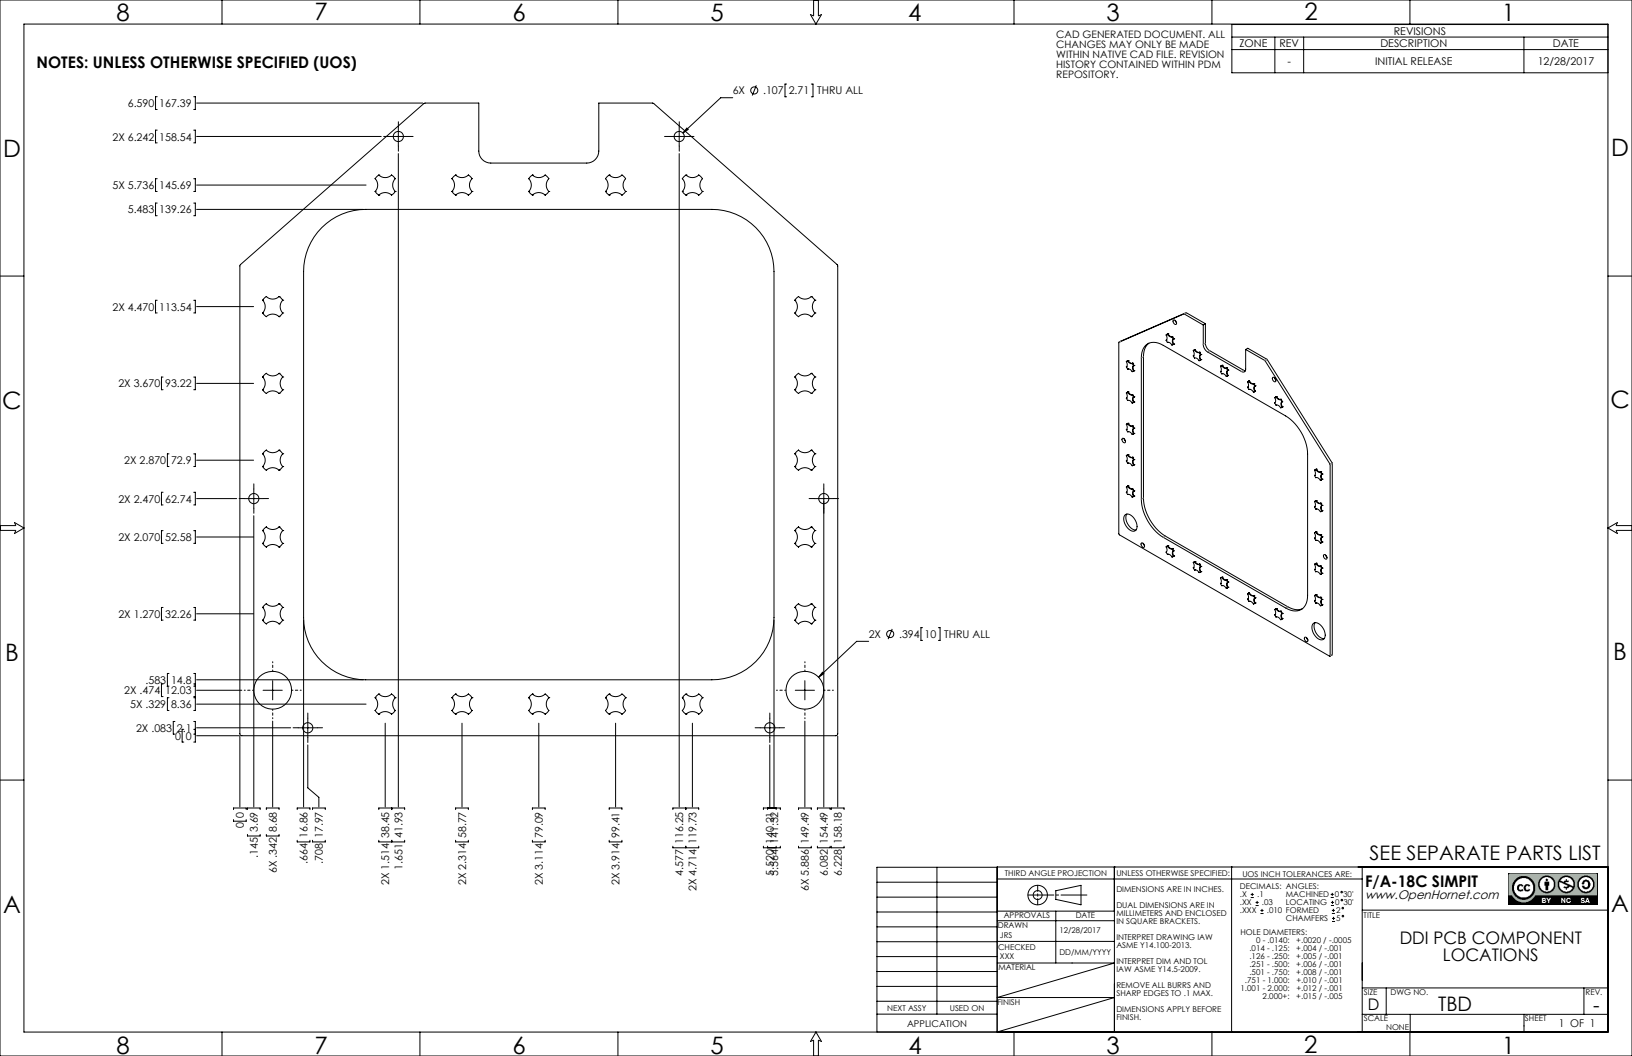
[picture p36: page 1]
.107 2.71 THRU ALL; .394 10 THRU ALL; NEXT ASSY; USED ON; DWG NO.; MACHINED; LOCATING; HOLE DIAMETERS: 0 - .0140: +.0020 / -.0005 .014 - .125: +.004 / -.001 .126 - .250: +.005 / -.001 .251 - .500: +.006 / -.001 .501 - .750: +.008 / -.001 .751 - 1.000: +.010 / -.001 1.001 - 2.000: +.012 / -.001 2.000+: +.015 / -.005 FINISH

CAD GENERATED DOCUMENT. ALL
CHANGES MAY ONLY BE MADE
WITHIN NATIVE CAD FILE. REVISION
HISTORY CONTAINED WITHIN PDM
REPOSITORY.

ZONE | REV | DESCRIPTION | DATE

NOTES: UNLESS OTHERWISE SPECIFIED (UOS)

- | INITIAL RELEASE | 12/28/2017

SEE SEPARATE PARTS LIST
F/A-18C SIMPIT
www.OpenHornet.com
DDI PCB COMPONENT
LOCATIONS
TBD

THIRD ANGLE PROJECTION

UNLESS OTHERWISE SPECIFIED:
DIMENSIONS ARE IN INCHES.
DUAL DIMENSIONS ARE IN
MILLIMETERS AND ENCLOSED
IN SQUARE BRACKETS.
INTERPRET DRAWING IAW
ASME Y14.100-2013.
INTERPRET DIM AND TOL
IAW ASME Y14.5-2009.
REMOVE ALL BURRS AND
SHARP EDGES TO .1 MAX.
DIMENSIONS APPLY BEFORE
FINISH.

UOS INCH TOLERANCES ARE:
DECIMALS:

DD/MM/YYYY

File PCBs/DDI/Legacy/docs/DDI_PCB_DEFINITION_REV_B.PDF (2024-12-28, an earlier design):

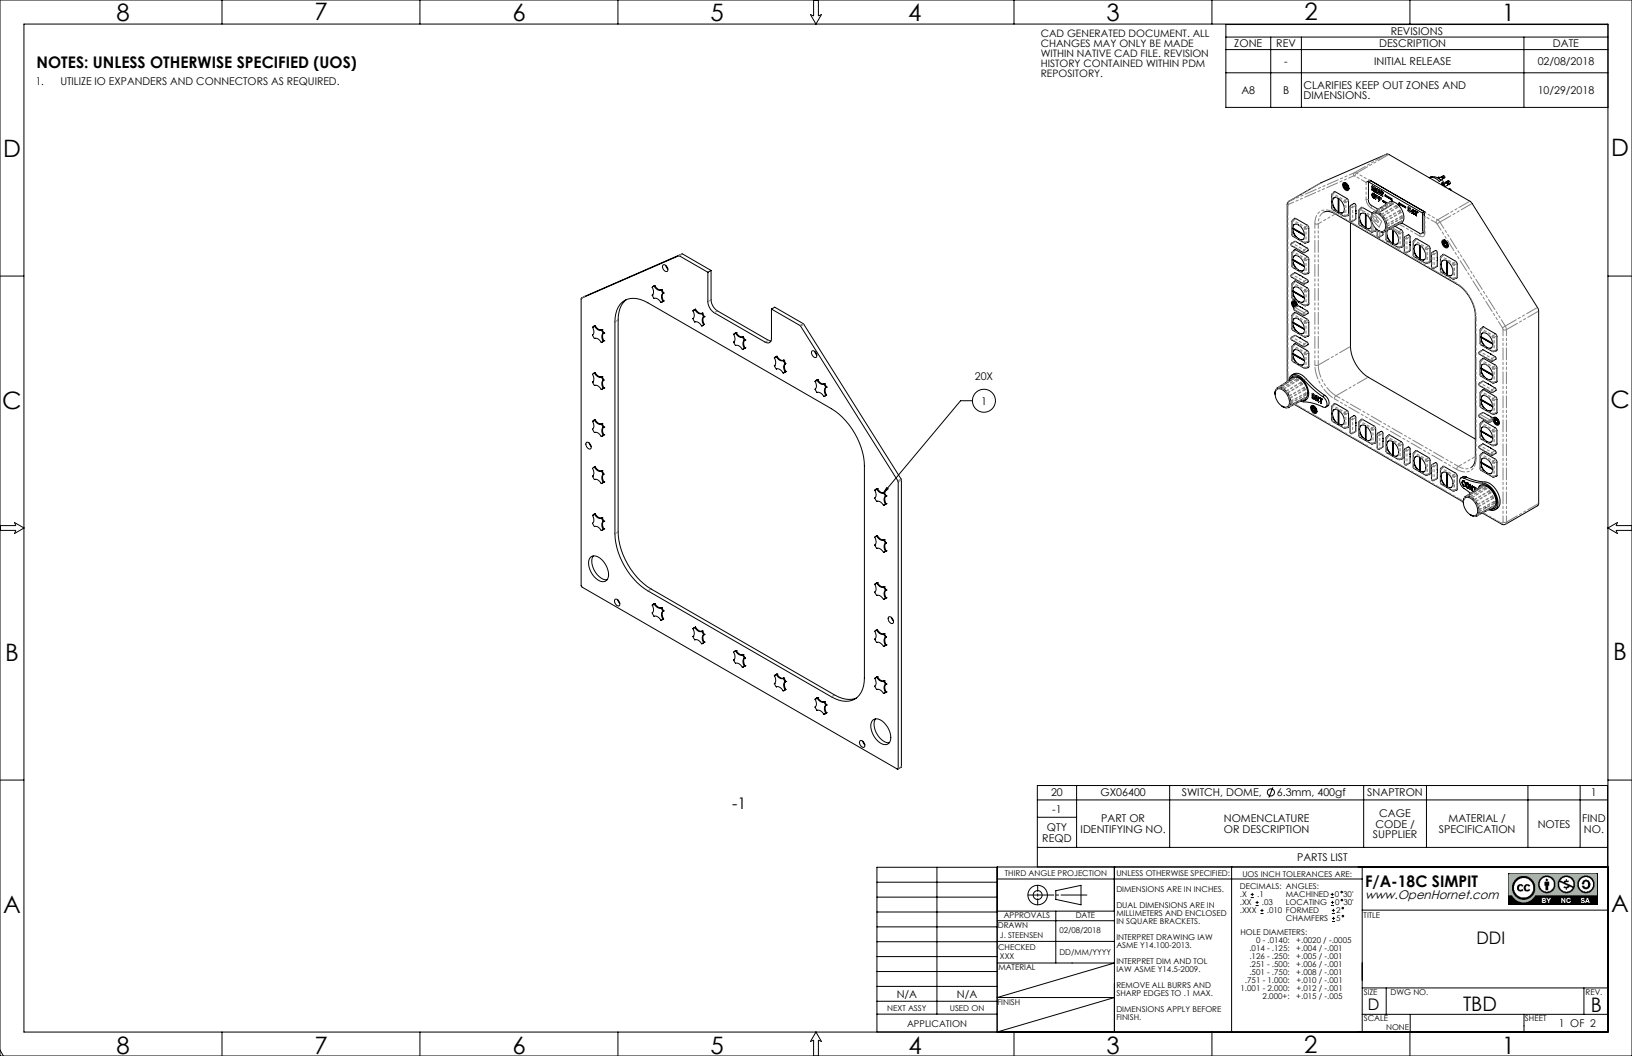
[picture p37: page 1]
SWITCH, DOME, 6.3mm, 400gf; SNAPTRON; PART OR IDENTIFYING NO.; OR DESCRIPTION; CODE /; MATERIAL /; PARTS LIST; F/A-18C SIMPIT; DWG NO.; J. STEENSEN; MACHINED; LOCATING; HOLE DIAMETERS: 0 - .0140: +.0020 / -.0005 .014 - .125: +.004 / -.001 .126 - .250: +.005 / -.001 .251 - .500: +.006 / -.001 .501 - .750: +.008 / -.001 .751 - 1.000: +.010 / -.001 1.001 - 2.000: +.012 / -.001 2.000+: +.015 / -.005 FINISH

CAD GENERATED DOCUMENT. ALL
CHANGES MAY ONLY BE MADE
WITHIN NATIVE CAD FILE. REVISION
HISTORY CONTAINED WITHIN PDM
REPOSITORY.

ZONE | REV | DESCRIPTION | DATE

NOTES: UNLESS OTHERWISE SPECIFIED (UOS)
1. UTILIZE IO EXPANDERS AND CONNECTORS AS REQUIRED.

- | INITIAL RELEASE | 02/08/2018
A8 | B | CLARIFIES KEEP OUT ZONES AND DIMENSIONS. | 10/29/2018

THIRD ANGLE PROJECTION

UNLESS OTHERWISE SPECIFIED:
DIMENSIONS ARE IN INCHES.
DUAL DIMENSIONS ARE IN
MILLIMETERS AND ENCLOSED
IN SQUARE BRACKETS.
INTERPRET DRAWING IAW
ASME Y14.100-2013.
INTERPRET DIM AND TOL
IAW ASME Y14.5-2009.
REMOVE ALL BURRS AND
SHARP EDGES TO .1 MAX.
DIMENSIONS APPLY BEFORE
FINISH.

UOS INCH TOLERANCES ARE:
DECIMALS:

DD/MM/YYYY

N/A | N/A
NEXT ASSY | USED ON

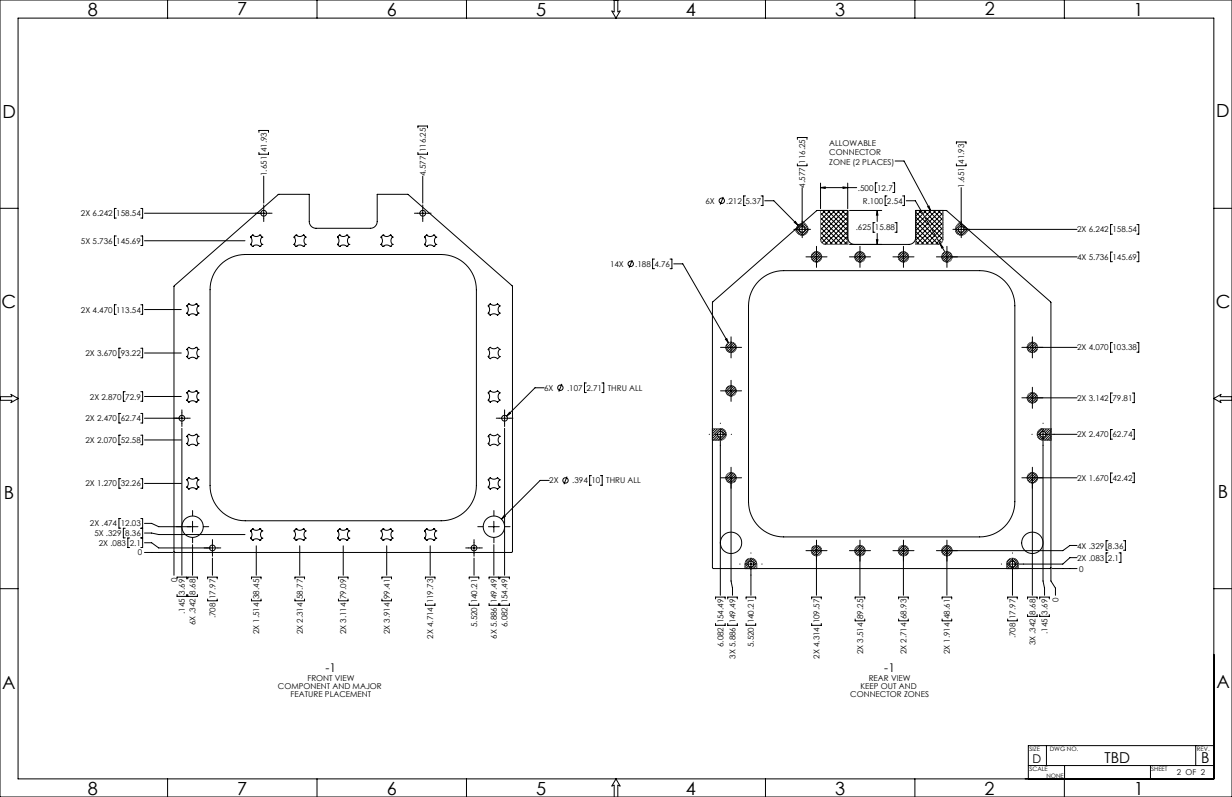
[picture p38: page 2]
.107 2.71 THRU ALL; .394 10 THRU ALL; ZONE (2 PLACES); SIZE DWG NO.; REV.

FRONT VIEW
COMPONENT AND MAJOR
FEATURE PLACEMENT

REAR VIEW
KEEP OUT AND
CONNECTOR ZONES

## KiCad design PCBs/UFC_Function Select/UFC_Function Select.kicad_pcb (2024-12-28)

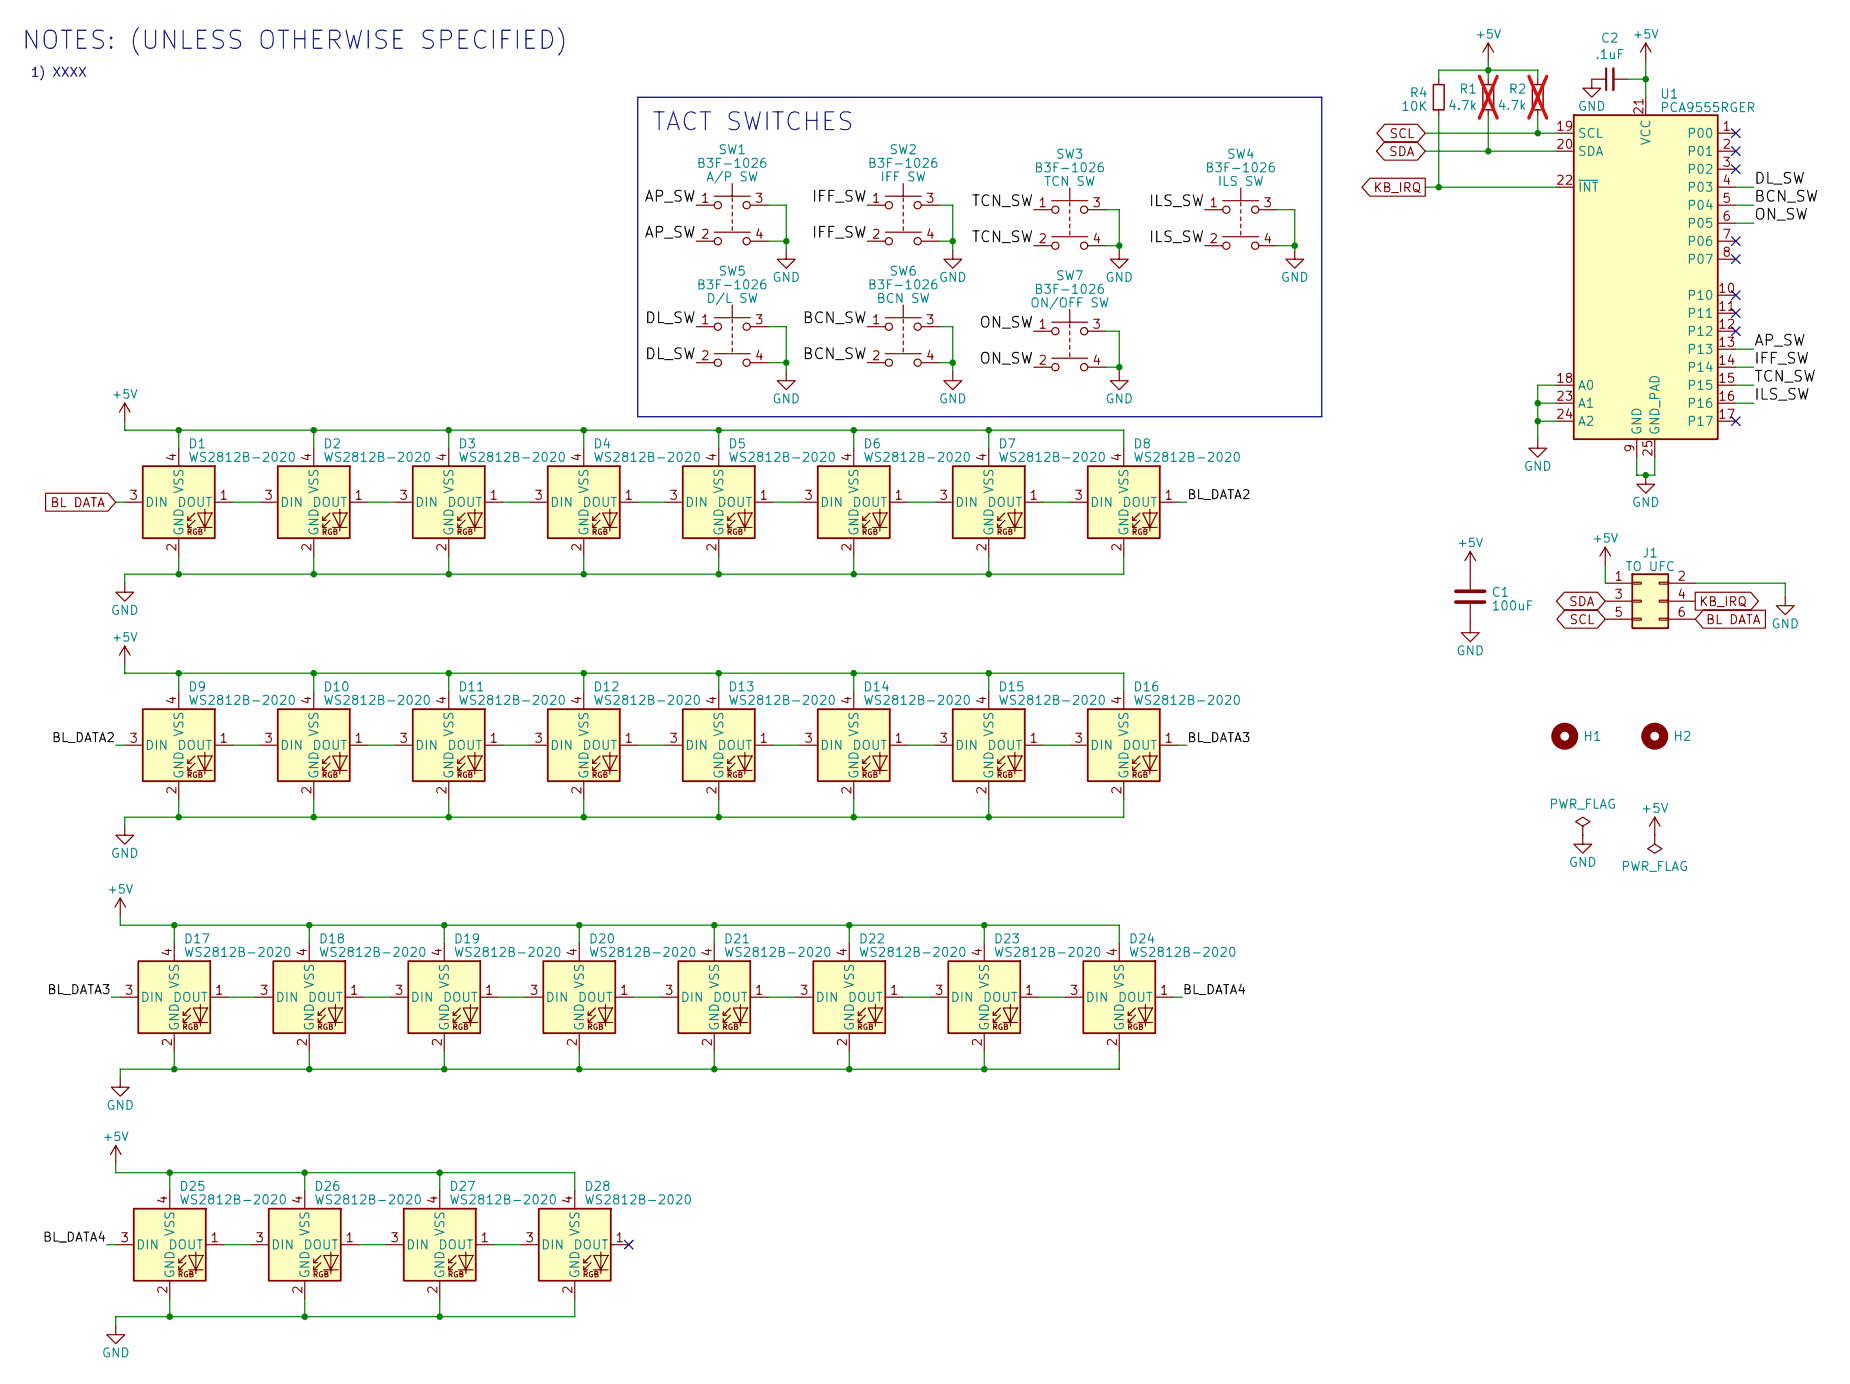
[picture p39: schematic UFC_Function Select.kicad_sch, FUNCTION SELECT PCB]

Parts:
C1: 100uF; CP_Elec_6.3x5.4; LCSC C2963046
C2: .1uF; C_0603_1608Metric; LCSC C14663
D1, D2, D3, D4, D5, D6, D7, D8, D9, D10, D11, D12, D13, D14, D15, D16, D17, D18, D19, D20, D21, D22, D23, D24, D25, D26, D27, D28: WS2812B-2020; LED_WS2812B-2020_PLCC4_2.0x2.0mm; Manufacturer PN WS2812B-2020; LCSC C965555
H1, H2: MountingHole_3.2mm_M3_DIN965
J1: TO UFC; PinHeader_2x03_P2.54mm_Vertical
R1, R2: 4.7k; R_0603_1608Metric; LCSC C23162; not fitted
R4: 10K; R_0603_1608Metric; LCSC C25804
SW1, SW2, SW3, SW4, SW5, SW6, SW7: B3F-1026; Omron_B3F-1026
U1: PCA9555RGER; VQFN-24-1EP_4x4mm_P0.5mm_EP2.45x2.45mm; LCSC C2652275

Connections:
+5V: C1.1, C2.2, D1.4 (VSS), D2.4 (VSS), D3.4 (VSS), D4.4 (VSS), D5.4 (VSS), D6.4 (VSS), D7.4 (VSS), D8.4 (VSS), D9.4 (VSS), D10.4 (VSS), D11.4 (VSS), D12.4 (VSS), D13.4 (VSS), D14.4 (VSS), D15.4 (VSS), D16.4 (VSS), D17.4 (VSS), D18.4 (VSS), D19.4 (VSS), D20.4 (VSS), D21.4 (VSS), D22.4 (VSS), D23.4 (VSS), D24.4 (VSS), D25.4 (VSS), D26.4 (VSS), D27.4 (VSS), D28.4 (VSS), J1.1, R1.1, R2.2, R4.2, U1.21 (VCC)
/AP_SW: SW1.1, SW1.2, U1.13
/BCN_SW: SW6.1, SW6.2, U1.5 (P04)
/BL_DATA2: D8.1 (DOUT), D9.3 (DIN)
/BL_DATA3: D16.1 (DOUT), D17.3 (DIN)
/BL_DATA4: D24.1 (DOUT), D25.3 (DIN)
/DL_SW: SW5.1, SW5.2, U1.4 (P03)
/IFF_SW: SW2.1, SW2.2, U1.14
/ILS_SW: SW4.1, SW4.2, U1.16
/ON_SW: SW7.1, SW7.2, U1.6 (P05)
/TCN_SW: SW3.1, SW3.2, U1.15
BL DATA: D1.3 (DIN), J1.6
GND: C1.2, C2.1, D1.2 (GND), D2.2 (GND), D3.2 (GND), D4.2 (GND), D5.2 (GND), D6.2 (GND), D7.2 (GND), D8.2 (GND), D9.2 (GND), D10.2 (GND), D11.2 (GND), D12.2 (GND), D13.2 (GND), D14.2 (GND), D15.2 (GND), D16.2 (GND), D17.2 (GND), D18.2 (GND), D19.2 (GND), D20.2 (GND), D21.2 (GND), D22.2 (GND), D23.2 (GND), D24.2 (GND), D25.2 (GND), D26.2 (GND), D27.2 (GND), D28.2 (GND), J1.2, SW1.3, SW1.4, SW2.3, SW2.4, SW3.3, SW3.4, SW4.3, SW4.4, SW5.3, SW5.4, SW6.3, SW6.4, SW7.3, SW7.4, U1.9 (GND), U1.18 (A0), U1.23 (A1), U1.24 (A2), U1.25 (GND_PAD)
KB_IRQ: J1.4, R4.1, U1.22 (~INT)
unnamed: D1.1 (DOUT), D2.3 (DIN)
unnamed: D2.1 (DOUT), D3.3 (DIN)
unnamed: D3.1 (DOUT), D4.3 (DIN)
unnamed: D4.1 (DOUT), D5.3 (DIN)
unnamed: D5.1 (DOUT), D6.3 (DIN)
unnamed: D6.1 (DOUT), D7.3 (DIN)
unnamed: D7.1 (DOUT), D8.3 (DIN)
unnamed: D9.1 (DOUT), D10.3 (DIN)
unnamed: D10.1 (DOUT), D11.3 (DIN)
unnamed: D11.1 (DOUT), D12.3 (DIN)
unnamed: D12.1 (DOUT), D13.3 (DIN)
unnamed: D13.1 (DOUT), D14.3 (DIN)
unnamed: D14.1 (DOUT), D15.3 (DIN)
unnamed: D15.1 (DOUT), D16.3 (DIN)
unnamed: D17.1 (DOUT), D18.3 (DIN)
unnamed: D18.1 (DOUT), D19.3 (DIN)
unnamed: D19.1 (DOUT), D20.3 (DIN)
unnamed: D20.1 (DOUT), D21.3 (DIN)
unnamed: D21.1 (DOUT), D22.3 (DIN)
unnamed: D22.1 (DOUT), D23.3 (DIN)
unnamed: D23.1 (DOUT), D24.3 (DIN)
unnamed: D25.1 (DOUT), D26.3 (DIN)
unnamed: D26.1 (DOUT), D27.3 (DIN)
unnamed: D27.1 (DOUT), D28.3 (DIN)
SCL: J1.5, R2.1, U1.19 (SCL)
SDA: J1.3, R1.2, U1.20 (SDA)

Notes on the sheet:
TACT SWITCHES
NOTES: (UNLESS OTHERWISE SPECIFIED)
1) XXXX

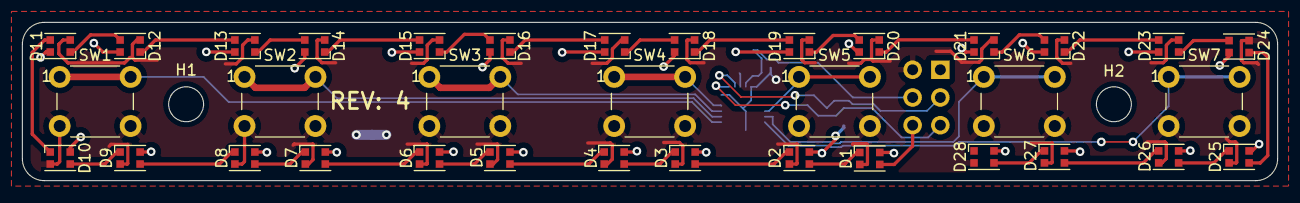
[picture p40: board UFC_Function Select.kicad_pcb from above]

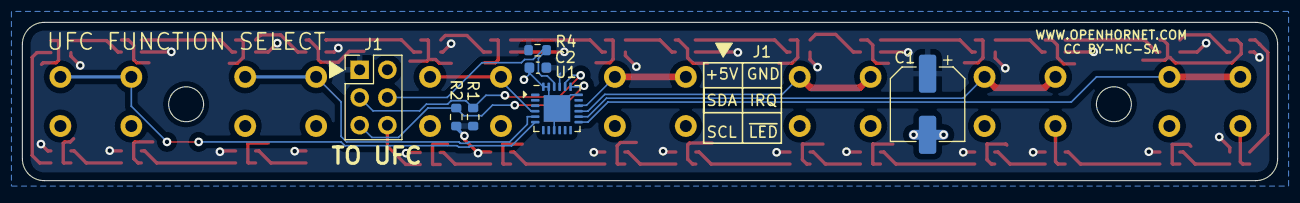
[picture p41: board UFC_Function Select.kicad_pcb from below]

Board: 2 copper layers, 115.0 x 14.5 mm, 44 parts (7 on the bottom side), 40 nets.

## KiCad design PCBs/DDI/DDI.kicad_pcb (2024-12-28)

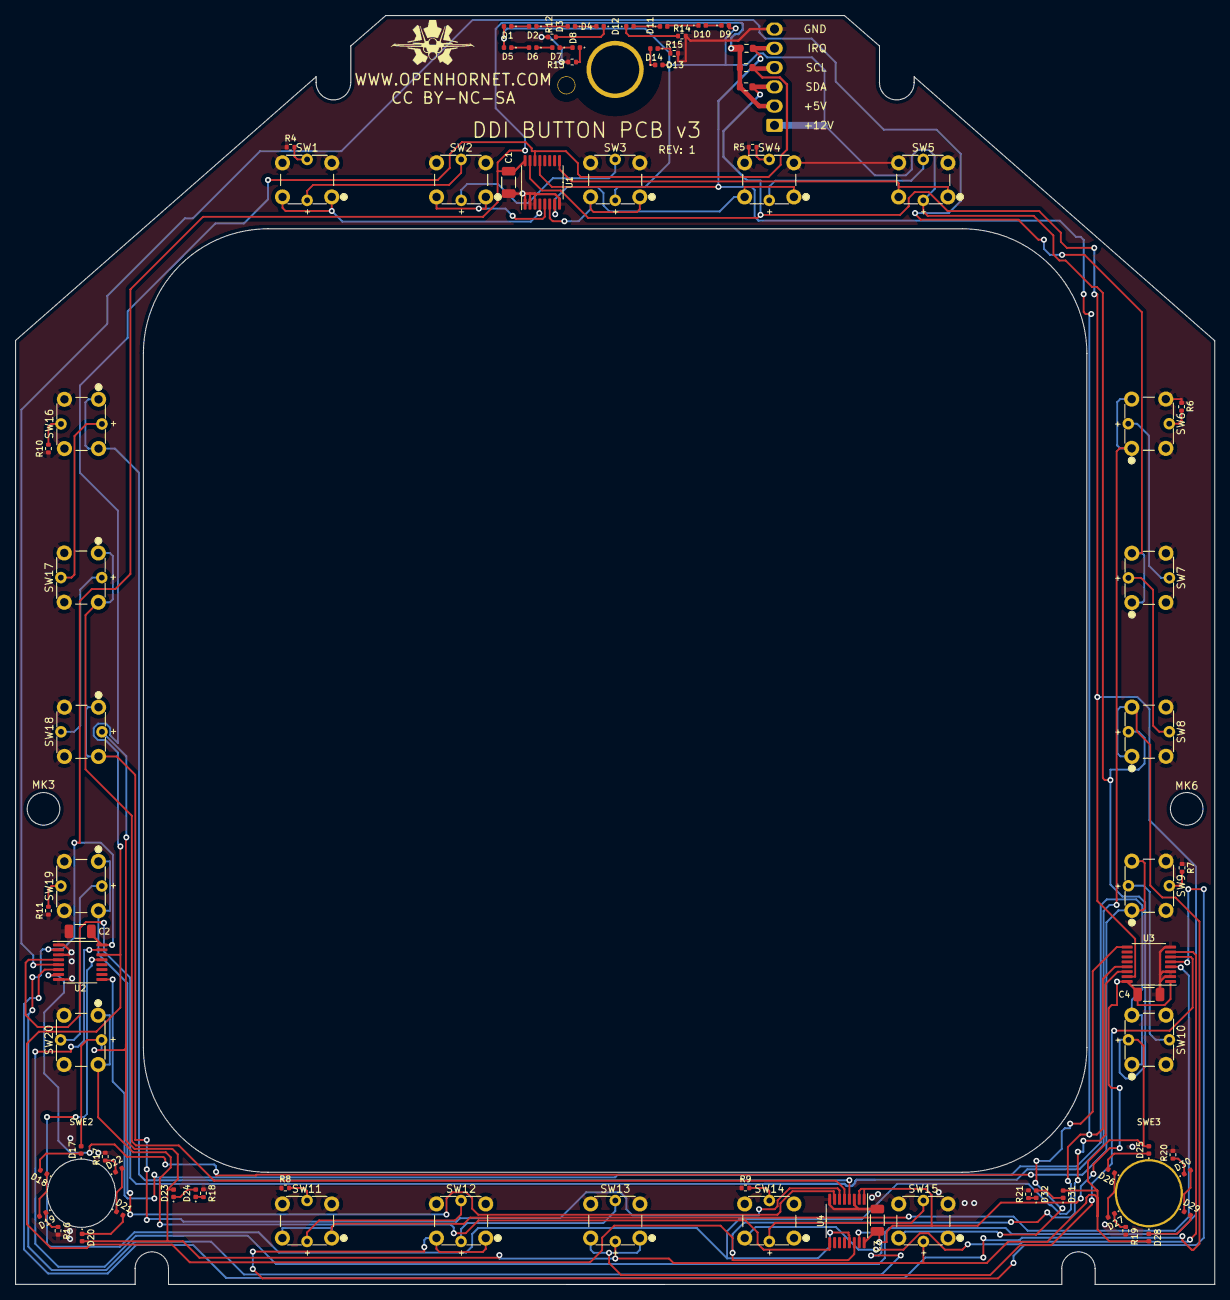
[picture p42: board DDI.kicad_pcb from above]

Board: 2 copper layers, 158.2 x 167.4 mm, 85 parts (1 on the bottom side), 56 nets.

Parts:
C1, C2, C3, C4: 47uF; C_1206_3216Metric
D1, D2, D3, D4, D5, D6, D7, D8, D9, D10, D11, D12, D13, D14, D17, D18, D19, D20, D21, D22, D23, D24, D25, D26, D27, D28, D29, D30, D31, D32: LED; LED_0402_1005Metric
J1: Conn_01x06; Molex_KK-254_AE-6410-06A_1x06_P2.54mm_Vertical
MK3, MK6: MH; MountingHole_4.3mm_M4
R1, R2, R3: 10K; R_0603_1608Metric
R4, R6, R8, R10, R16, R17, R19, R20: 150; R_0402_1005Metric
R5, R7, R9, R11, R15, R18, R21: 270; R_0402_1005Metric
R12, R13, R14: 33; R_0402_1005Metric
SW1, SW2, SW3, SW4, SW5, SW6, SW7, SW8, SW9, SW10, SW11, SW12, SW13, SW14, SW15, SW16, SW17, SW18, SW19, SW20: TL1240GQ
SWE1: MRY106_RotarySW
SWE2, SWE3: MountingHole_8.4mm_M8
U1, U2, U3, U4: TCA9554PWR; TSSOP-16_4.4x5mm_P0.65mm

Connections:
+5V: C1.1, C2.1, C3.1, C4.1, J1.2, R1.1, R2.1, R3.1, U1.16, U2.2, U2.16, U3.1, U3.16, U4.1, U4.2, U4.16
/U1P0: SW1.1, U1.4
/U1P1: SW2.1, U1.5
/U1P2: SW3.1, U1.6
/U1P3: SW4.1, U1.7
/U1P4: SW5.1, U1.9
/U2P0: SW6.1, U2.4
/U2P1: SW7.1, U2.5
/U2P2: SW8.1, U2.6
/U2P3: SW9.1, U2.7
/U2P4: SW10.1, U2.9
/U3P0: SW11.1, U3.4
/U3P1: SW12.1, U3.5
/U3P2: SW13.1, U3.6
/U3P3: SW14.1, U3.7
/U3P4: SW15.1, U3.9
/U4P0: SW16.1, U4.4
/U4P1: SW17.1, U4.5
/U4P2: SW18.1, U4.6
/U4P3: SW19.1, U4.7
/U4P4: SW20.1, U4.9
GND: C1.2, C2.2, C3.2, C4.2, J1.6, R4.1, R5.1, R6.1, R7.1, R8.1, R9.1, R10.1, R11.1, R12.2, R13.2, R14.2, R15.2, R16.2, R17.2, R18.2, R19.2, R20.2, R21.2, SW1.2, SW2.2, SW3.2, SW4.2, SW5.2, SW6.2, SW7.2, SW8.2, SW9.2, SW10.2, SW11.2, SW12.2, SW13.2, SW14.2, SW15.2, SW16.2, SW17.2, SW18.2, SW19.2, SW20.2, U1.1, U1.2, U1.3, U1.8, U2.1, U2.3, U2.8, U3.2, U3.3, U3.8, U4.3, U4.8
IRQ: J1.5, R1.2, U1.13, U2.13, U3.13, U4.13
unnamed: D1.1, D2.2
unnamed: D2.1, D3.2
unnamed: D3.1, D4.2
unnamed: D4.1, R12.1
unnamed: D5.1, D6.2
unnamed: D6.1, D7.2
unnamed: D7.1, D8.2
unnamed: D8.1, R13.1
unnamed: D10.1, D11.2
unnamed: D9.1, D10.2
unnamed: D11.1, D12.2
unnamed: D12.1, R14.1
unnamed: D13.1, D14.2
unnamed: D14.1, R15.1
unnamed: D17.1, D18.2
unnamed: D18.1, D19.2
unnamed: D19.1, R16.1
unnamed: D20.1, D21.2
unnamed: D21.1, D22.2
unnamed: D22.1, R17.1
unnamed: D23.1, D24.2
unnamed: D24.1, R18.1
unnamed: D25.1, D26.2
unnamed: D26.1, D27.2
unnamed: D27.1, R19.1
unnamed: D28.1, D29.2
unnamed: D29.1, D30.2
unnamed: D30.1, R20.1
unnamed: D31.1, D32.2
unnamed: D32.1, R21.1
SCL: J1.4, R2.2, U1.14, U2.14, U3.14, U4.14
SDA: J1.3, R3.2, U1.15, U2.15, U3.15, U4.15
VCC: D1.2, D5.2, D9.2, D13.2, D17.2, D20.2, D23.2, D25.2, D28.2, D31.2, J1.1

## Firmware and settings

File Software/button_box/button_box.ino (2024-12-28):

#include <Wire.h>

#define WITH_USB 1

#ifdef WITH_USB
#include <USB.h>
#include <Joystick_ESP32S2.h>
#endif

// Constants
const int INTERRUPT_PIN = 39;       // Pin connected to the interrupt source
const gpio_num_t INTERRUPT_GPIO_PIN = GPIO_NUM_39;

const uint8_t pcf8575Address = 0x20; // PCF8575 I2C address (all set low)

volatile bool interruptFlag = false; // Flag set in the ISR

uint16_t lastState = 0xFF;
unsigned long debounceTimes[32];
const unsigned long DEBOUNCE_TIME_MS = 10;

#ifdef WITH_USB
Joystick_ Joystick(JOYSTICK_DEFAULT_REPORT_ID, 
  JOYSTICK_TYPE_JOYSTICK, 32, 0,
  false, false, false, false, false, false,
  true, true, false, false, false);
#endif

const uint16_t BUTTON_PINS[] = {0, 1, 2};
const uint16_t SPST_PINS[] = {3, 4, 5, 6, 7};
const uint16_t SPST_VIRTUAL_PINS[] = {16, 17, 18, 19, 20};
bool SPST_VIRTUAL_PIN_STATES[] = {false, false, false, false, false};

const uint16_t THREE_POS1_PINS[] = {8, 9};
const uint16_t THREE_POS1_OFF_BUTTON = 31;
bool THREE_POS1_OFF_BUTTON_STATE = false;

const uint16_t DIAL1_PINS[] = {10, 11, 12, 13};
const uint16_t DIAL1_OFF_BUTTON = 30;
bool Dial1OffButtonState = false;
unsigned long dialDebounceTime = 0;

const uint16_t PB_ARDUINO_PINS[] = {2, 3, 5, 4};
int PbIsPull = -1;
int PbIsCCW = -1;
int PbLastHit = -1;
const uint16_t PB_BTN_CCW = 26;
const uint16_t PB_BTN_CW = 27;
const uint16_t PB_BTN_PULL = 28;
const uint16_t PB_BTN_STOW = 29;

bool isWaitingOnDebounce = false;

// ISR for the interrupt pin
void handleInterrupt() {
  interruptFlag = true;
}

void setup() {
  // Initialize serial monitor for debugging
  Serial.begin(19200);
  delay(50);
  Serial.println("Booting");

  if (sizeof(SPST_PINS) / sizeof(SPST_PINS[0]) != sizeof(SPST_VIRTUAL_PINS) / sizeof(SPST_VIRTUAL_PINS[0])) {
    Serial.println("ERROR: Mismatch between real and virtual SPST pin arrays");
  } else if (sizeof(SPST_PINS) / sizeof(SPST_PINS[0]) != sizeof(SPST_VIRTUAL_PIN_STATES) / sizeof(SPST_VIRTUAL_PIN_STATES[0])) {
    Serial.println("ERROR: Mismatch between real and virtual SPST state array");
  }

#ifdef WITH_USB
  USB.PID(0x2341);
	USB.VID(0x2341);
  USB.productName("Parking button box");
  USB.manufacturerName("Goldylox Buttons Inc.");
	
	USB.begin();
  Joystick.begin();
#endif

  memset(debounceTimes, 0, sizeof(debounceTimes));
  
  // Set up the interrupt pin for the I2C
  pinMode(INTERRUPT_PIN, INPUT_PULLUP); // Using internal pull-up resistor
  attachInterrupt(digitalPinToInterrupt(INTERRUPT_PIN), handleInterrupt, FALLING); // Interrupt on falling edge
  esp_sleep_enable_ext0_wakeup(INTERRUPT_GPIO_PIN, LOW);  // Wake up on LOW signal on !INT

  // set up PB input pins on the board itself
  for (int i = 0; i < sizeof(PB_ARDUINO_PINS) / sizeof(PB_ARDUINO_PINS[0]); i++) {
    pinMode(PB_ARDUINO_PINS[i], INPUT_PULLUP);
    attachInterrupt(digitalPinToInterrupt(PB_ARDUINO_PINS[i]), handleInterrupt, CHANGE);
  }
  
  // Initialize I2C communication
  Wire.begin();
  runButtonLogic(false);
  Serial.print("Setup complete. Initial state is ");
  Serial.println(lastState, BIN);
  Serial.flush();
}

void loop() {
  // zzzzz
  //Serial.println("Zzzzz");
  //Serial.flush();
  //esp_light_sleep_start();

  // Check if the interrupt has fired
  if (interruptFlag) {
    interruptFlag = false; // Reset flag

    runButtonLogic(true);
    while (isWaitingOnDebounce)  {
      delay(5);
      runButtonLogic(true);      
    }
  }
}

void runButtonLogic(bool withDebounce) {
    // Read input states from the PCF8575
    uint16_t inputState = readPCF8575();
    uint16_t diff = lastState ^ inputState;
    uint16_t debounceMask = makeDebounceMask();
    uint16_t hit = withDebounce ? diff & debounceMask : diff;

    isWaitingOnDebounce = ~debounceMask > 0;

    Serial.println(diff, BIN);
    Serial.println(hit, BIN);

    for (int i = 0; i < 16; i++) {
      if (hit & 1 << i) {
        debounceTimes[i] = millis();

        bool bWasReleased = inputState & 1 << i;

        if (bWasReleased) {
          Serial.print("Released ");  
        } else {
          Serial.print("Pressed ");  
        }
        Serial.print("input ");
        Serial.println(i);

        #ifdef WITH_USB  
       	Joystick.setButton(i, !bWasReleased);
        #endif
      }
    }

    HandlePBState();

    uint16_t nextState = lastState ^ hit;

    // correct for unwired inputs on 3pos, and SPST
    correctForUnwired(nextState, THREE_POS1_PINS, sizeof(THREE_POS1_PINS) / sizeof(THREE_POS1_PINS[0]), THREE_POS1_OFF_BUTTON, &THREE_POS1_OFF_BUTTON_STATE);    
    for (int i = 0; i < sizeof(SPST_PINS) / sizeof(SPST_PINS[0]); i++) {
      correctForUnwired(nextState, &SPST_PINS[i], 1, SPST_VIRTUAL_PINS[i], &SPST_VIRTUAL_PIN_STATES[i]);
    }

    // correct for unwired on dial -- requires debounce to settle since first we release the old value then we press the new one
    maybeDebounceDial(nextState, diff);

    if (dialDebounceTime <= millis()) {
      bool allOff = true;
      for (int i = 0; i < sizeof(DIAL1_PINS) / sizeof(DIAL1_PINS[0]); i++) {
        if ((nextState & 1 << DIAL1_PINS[i]) == 0) {
          allOff = false;
          if (Dial1OffButtonState) {
            #ifdef WITH_USB
              Joystick.setButton(DIAL1_OFF_BUTTON, false);
            #endif
            Serial.print("Released unwired ");
            Serial.println(DIAL1_OFF_BUTTON);    
            Dial1OffButtonState = false;
            break;
          }
        }
      }

      if (allOff && !Dial1OffButtonState) {
        #ifdef WITH_USB
          Joystick.setButton(DIAL1_OFF_BUTTON, true);
        #endif
        Serial.print("Pressed unwired ");
        Serial.println(DIAL1_OFF_BUTTON);    
        Dial1OffButtonState = true;
      }
    } else {
      isWaitingOnDebounce = true;
    }
    
    lastState = nextState;
}

void maybeDebounceDial(uint16_t nextState, uint16_t hit) {
  for (int i = 0; i < sizeof(DIAL1_PINS) / sizeof(DIAL1_PINS[0]); i++) {
    if (hit & 1 << DIAL1_PINS[i]) {
      // ok, something got hit in the dial. just delay for now (w/e) and then we'll check again
      Serial.println("Debouncing dial");
      dialDebounceTime = millis() + 25;
      return;
    }
  } 
}

// checks the pins[] array to see if any pin has been set. potentially sets or unsets unwiredButtonState and presses unwiredButton in response
void correctForUnwired(uint16_t newState, const uint16_t *pins, int numPins, int unwiredButton, bool *unwiredButtonState) {
    for (int i = 0; i < numPins; i++) {      
      if ((newState & 1 << pins[i]) == 0) {
        if (*unwiredButtonState) {
          #ifdef WITH_USB
            Joystick.setButton(unwiredButton, false);
          #endif
          Serial.print("Released unwired ");
          Serial.println(unwiredButton);          
          *unwiredButtonState = false;
        }
        return;
      }
    }

    if (*unwiredButtonState == false) {
      #ifdef WITH_USB
          Joystick.setButton(unwiredButton, true);
      #endif
        Serial.print("Pressed unwired ");
        Serial.println(unwiredButton);      
      *unwiredButtonState = true;
    }
}

void HandlePBState() {
  for (int i = 0; i < sizeof(PB_ARDUINO_PINS) / sizeof(PB_ARDUINO_PINS[0]); i++) {
    const int buttonState = !digitalRead(PB_ARDUINO_PINS[i]);  

    if (buttonState && PbLastHit != i) {
      Serial.print("PB hit ");
      Serial.println(i);

      if (i == 1) {
        // CCW stowed
        // if we came from CCW pulled, do a little dance
        if (PbIsCCW == 1 && PbIsPull == 1) {
          Serial.println("PB CCW Pull -> Stow");
          Joystick.setButton(PB_BTN_CW, false);
          Joystick.setButton(PB_BTN_PULL, false);
          Joystick.setButton(PB_BTN_CCW, false);
          delay(50);
          Serial.println("CCW hit");
          Joystick.setButton(PB_BTN_CCW, true);
          delay(150);
          Joystick.setButton(PB_BTN_CCW, false);
          delay(700);
          Serial.println("CCW hit 2");
          Joystick.setButton(PB_BTN_CCW, true);
          delay(150);
          Joystick.setButton(PB_BTN_CCW, false);
          PbIsCCW = 1;
          PbIsPull = 0;
        } else {
          if (PbIsCCW != 1) {
            Serial.println("PB CCW");
            PbIsCCW = 1;
            Joystick.setButton(PB_BTN_CW, false);  
            Joystick.setButton(PB_BTN_CCW, true);  
          }
          if (PbIsPull != 0) {
            Serial.println("PB Stow");
            PbIsPull = 0;
            Joystick.setButton(PB_BTN_PULL, false);
            Joystick.setButton(PB_BTN_STOW, true);  
          }
        }
        
      } else if (i == 3) {
        // CW stowed
        if (PbIsCCW != 0) {
          Serial.println("PB CW");
          PbIsCCW = 0;
          Joystick.setButton(PB_BTN_CCW, false);  
          Joystick.setButton(PB_BTN_CW, true);  
        }
        if (PbIsPull != 0) {
          Serial.println("PB Stow");
          PbIsPull = 0;
          Joystick.setButton(PB_BTN_PULL, false);
          Joystick.setButton(PB_BTN_STOW, true);  
        }
      } else if (i == 0) {
        // pull while CW
        if (PbIsCCW != 0) {
          Serial.println("PB CW");
          PbIsCCW = 0;
          Joystick.setButton(PB_BTN_CCW, false);  
          Joystick.setButton(PB_BTN_CW, true);  
        }
        if (PbIsPull != 1) {
          Serial.println("PB Pull");
          PbIsPull = 1;
          Joystick.setButton(PB_BTN_STOW, false);  
          Joystick.setButton(PB_BTN_PULL, true);
        }
      } else if (i == 2) {
        // pull while CCW
        if (PbIsCCW != 1) {
          Serial.println("PB CCW");
          PbIsCCW = 0;
          Joystick.setButton(PB_BTN_CW, false);  
          Joystick.setButton(PB_BTN_CCW, true);  
        }
        if (PbIsPull != 1) {
          Serial.println("PB Pull");
          PbIsPull = 1;
          Joystick.setButton(PB_BTN_STOW, false);  
          Joystick.setButton(PB_BTN_PULL, true);
        }
      }

      PbLastHit = i;
      isWaitingOnDebounce = true;
      return;
    }
  }
}

uint16_t makeDebounceMask() {
  unsigned long currTime = millis();

  uint16_t out = 0;
  for (int i = 0; i < 16; i++) {
    if (currTime - debounceTimes[i] > DEBOUNCE_TIME_MS) {
      out |= 1 << i;
    }
  }
  return out;
}

// Function to read all inputs from the PCF8575
uint16_t readPCF8575() {
  uint16_t state = 0xFFFF; // Default state for PCF8575 (all high)
  
  // Send a request to read 2 bytes from the PCF8575
  Wire.requestFrom(pcf8575Address, (uint8_t)2);
  delay(50); // Add small delay
  
  if (Wire.available() == 2) {
    uint8_t lowByte = Wire.read();
    uint8_t highByte = Wire.read();
    state = (highByte << 8) | lowByte; // Combine high and low bytes
  } else {
    Serial.println("Error: Could not read from PCF8575");
  }

  return state;
}

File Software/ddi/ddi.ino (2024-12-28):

#include <Wire.h>
#include <USB.h>
#include <Joystick_ESP32S2.h>
#include <PCA95x5.h>

#define IS_LEFT_DDI 1
#define IS_TEST 0

const int ROTARY_BUTTON_PRESS_TIME_MS = 150;

// Create io extenders
PCA9555 ioex[4];
uint16_t IOEX_ADDRESSES[] = { 0x20, 0x21, 0x22, 0x23 };

// Constants
const int INTERRUPT_PIN = 15;       // Pin connected to the interrupt source
volatile bool interruptFlag = false; // Flag set in the ISR
uint16_t DDIButtonStates[] = { 0xFF, 0xFF, 0xFF, 0xFF };

const int POT_PINS[] = { 1, 2 };
const int THREE_WAY_PINS[] = { 9, 11 };
int ThreeWayState = -1;

const int MASTER_ARM_PIN = 10;
const int MASTER_ARM_BUTTON = 4 * 8;
int MasterArmState = -1;
const int AA_AG_PINS[] = {6, 8};
const int AA_AG_BUTTONS[] = {MASTER_ARM_BUTTON + 2, MASTER_ARM_BUTTON + 3};
int AA_AG_States[] = { -1, -1 };

const int THREE_WAY_BASE = 4 * 8 + 2 + 2; // DDI buttons + master arm + AA + AG buttons
const int NUM_TOTAL_BUTTONS = THREE_WAY_BASE + 3;

unsigned long lastPotMeasurementTime = 0;
const unsigned long POT_REFRESH_TIME_MILLIS = 50;

struct SmoothingBuffer {
  float *buffer;
  int idx;
  int numElems;

  SmoothingBuffer(int numElemsIn) {
    idx = 0;
    numElems = numElemsIn;
    buffer = new float[numElemsIn];
  }

  float addAndRead(float sample) {
    buffer[idx] = sample;
    idx = (idx + 1) % numElems;

    float avg = 0;
    for (int i = 0; i < numElems; i++) {
      avg += (buffer[i] / numElems);
    }
    return avg;
  }
};

SmoothingBuffer PotSmoothers[2] = { SmoothingBuffer(6), SmoothingBuffer(6) };

Joystick_ Joystick(0x01, 
  JOYSTICK_TYPE_JOYSTICK, NUM_TOTAL_BUTTONS, 0,
  true, true, false, false, false, false, // include x and y axes
  true, true, false, false, false);

const int AXIS_RANGE = 128;

void onInterrupt()
{
  interruptFlag = true;
}

void setup()
{
  #if IS_TEST != 1
  char productName[128];
  snprintf(productName, sizeof(productName), "F18 DDI %s", IS_LEFT_DDI ? "LEFT" : "RIGHT");
  if (!USB.PID(0x2341) || !USB.VID(IS_LEFT_DDI ? 0x0002 : 0x0003) || !USB.productName(productName) || !USB.manufacturerName("Goldylox Buttons Inc.")) {
    while(1) {
      Serial.println("Error initializing USB");
      delay(100);
    }
  }
  #endif

  Joystick.setXAxisRange(-AXIS_RANGE, AXIS_RANGE);
  Joystick.setYAxisRange(-AXIS_RANGE, AXIS_RANGE);

	USB.begin();
  Joystick.begin();

  Serial.begin(9600);
  Serial.println(__FILE__);

  Wire.begin();

  // configure the PCA9555s
  for (int i = 0; i < 4; i++) {
    ioex[i].attach(Wire, IOEX_ADDRESSES[i]);
    ioex[i].polarity(PCA95x5::Polarity::ORIGINAL_ALL);
    ioex[i].direction(PCA95x5::Direction::IN_ALL);
  }

  // three way
  for (int i = 0; i < sizeof(THREE_WAY_PINS) / sizeof(THREE_WAY_PINS[0]); i++) {
    pinMode(THREE_WAY_PINS[i], INPUT_PULLUP);
  }

  // aa/ag buttons
  for (int i = 0; i < sizeof(AA_AG_PINS) / sizeof(AA_AG_PINS[0]); i++) {
    pinMode(AA_AG_PINS[i], INPUT_PULLUP);
  }

  // master arm
  pinMode(MASTER_ARM_PIN, INPUT_PULLUP);
  
  // setup interrupt on processor
  pinMode(INTERRUPT_PIN, INPUT_PULLUP);
  attachInterrupt(digitalPinToInterrupt(INTERRUPT_PIN), onInterrupt, FALLING);
}

void handleDDIButtons() {
  bool hitSomething = false;

  for (int ddiIdx = 0; ddiIdx < 4; ddiIdx++) {
    const uint16_t buttonStates = ioex[ddiIdx].read();
    const uint16_t diffMask = DDIButtonStates[ddiIdx] ^ buttonStates;

    if (diffMask != 0) {
      for (int i = 0; i < 8; i++) {
        if ((1 << i) & diffMask) {
          bool newValue = ((1 << i) & buttonStates) == 0;
          int buttonNum = ddiIdx * 8 + i;

          Serial.print(newValue ? "DDI Pressed " : "DDI Released ");
          Serial.println(buttonNum);
          Joystick.setButton(buttonNum, newValue);
          bool hitSomething = true;
        }
      }
      DDIButtonStates[ddiIdx] = buttonStates;
    }
  }

  if (hitSomething) {
    delay(20); // bad debouncing
  }
}

void handlePots() {
  unsigned long currTime = millis();
  if (currTime - lastPotMeasurementTime < POT_REFRESH_TIME_MILLIS) {
    return;
  }
  lastPotMeasurementTime = currTime;

  for (int i = 0; i < 2; i++) {
    int rawValue = analogRead(POT_PINS[i]);
    float normalizedValue = rawValue / 8192.0; // Normalize to 0...1 range

    float smoothedValue = PotSmoothers[i].addAndRead(normalizedValue);

    int actualValue = (smoothedValue * 2 * AXIS_RANGE) - AXIS_RANGE;

    if (i == 0) {
      Joystick.setXAxis(actualValue);
    } else {
      Joystick.setYAxis(actualValue);
    }
  }

  // TODO: REMOVE
  //Serial.println("--------------------------------");
  //delay(500);
}

void handleThreeWay() {
  int newState = 2;
  bool hitSomething = false;

  for (int i = 0; i < 2; i++) {
    int value = digitalRead(THREE_WAY_PINS[i]);
    if (value == 0) {
      newState = i;
    }
  }

  // the release can happen before the press. so it might look like release 0, (nothing...), press 2
  // we want to turn that into direct input, so pause after we see the release before we check again
  if (newState != ThreeWayState) {
    delay(30);
    
    for (int i = 0; i < 2; i++) {
      int value = digitalRead(THREE_WAY_PINS[i]);
      if (value == 0) {
        newState = i;
      }      
    }
    
    if (newState != ThreeWayState) {
      Serial.print("3W Released ");
      Serial.println(ThreeWayState);
      Joystick.setButton(THREE_WAY_BASE + ThreeWayState, false);

      Serial.print("3W Pressed ");
      Serial.println(newState);
      Joystick.setButton(THREE_WAY_BASE + newState, true);

      ThreeWayState = newState;
    }
  }
}

void handleMasterArm() {
  int masterArmRead = digitalRead(MASTER_ARM_PIN);
  if (masterArmRead == 0 && MasterArmState != 0) {
      Serial.println("Master arm ON");
      Joystick.setButton(MASTER_ARM_BUTTON + 1, false);
      Joystick.setButton(MASTER_ARM_BUTTON, true);
      MasterArmState = masterArmRead;
      delay(20);
  } else if (masterArmRead != 0 && MasterArmState == 0) {
    Serial.println("Master arm OFF");
    Joystick.setButton(MASTER_ARM_BUTTON, false);
    Joystick.setButton(MASTER_ARM_BUTTON + 1, true);
    MasterArmState = masterArmRead;
    delay(20);
  }
}

void handleAAAGButtons() {
  for (int i = 0; i < 2; i++) {
    int currState = digitalRead(AA_AG_PINS[i]);
    if (currState != AA_AG_States[i]) {
      AA_AG_States[i] = currState;

      Serial.print("AA/AG");
      Serial.print(currState == 0 ? " Pressed " : " Released ");
      Serial.println(i);
      Joystick.setButton(AA_AG_BUTTONS[i], currState == 0);
    }
  }
}

void loop()
{
  handleDDIButtons();
  handlePots();
  handleThreeWay();

  #if IS_LEFT_DDI == 1
    handleMasterArm();
    handleAAAGButtons();
  #endif
}

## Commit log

2024-11-21 new stuff
    [DDI desk Mount Plate.3mf, DDI desk mount arm left.3mf, DDI desk mount arm right.3mf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]
2024-11-22 shipped off v1.1
    [DDI desk Mount Plate.3mf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]
2024-12-28 complete for now
    [AP Switch Module.dxf, AntiSkidSwitchCover.3mf, BOM-UFC_Function Select.csv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]

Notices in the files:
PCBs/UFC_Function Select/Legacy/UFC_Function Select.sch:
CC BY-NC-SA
